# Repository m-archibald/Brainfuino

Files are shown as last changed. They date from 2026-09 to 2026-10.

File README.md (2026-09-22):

# Brainfuino [-]+.

```text
  ____            _        __       _           
 | __ ) _ __ __ _(_)_ __  / _|_   _(_)_ __   ___  
 |  _ \| '__/ _` | | '_ \| |_| | | | | '_ \ / _ \ 
 | |_) | | | (_| | | | | |  _| |_| | | | | | (_) |
 |____/|_|  \__,_|_|_| |_|_|  \__,_|_|_| |_|\___/ 
```

**An Arduino-like development board that executes raw Brainfuck natively in silicon.**

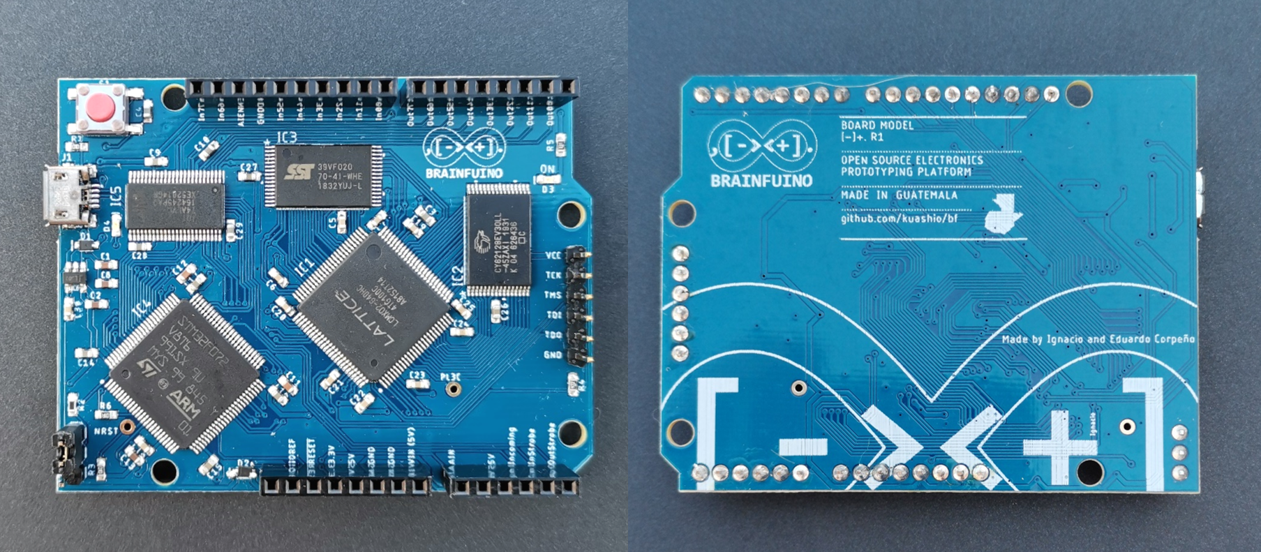
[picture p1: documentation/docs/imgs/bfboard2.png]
The Brainfuino [-]+.
[](https://youtu.be/QloNq8AoHvU)







> ### 📖 [Read the Full Documentation](https://m-archibald.github.io/Brainfuino/)
>
> Comprehensive guides covering quick start, hardware architecture, FPGA toolchain, DirtyJTAG / Diamond flashing, STM32 firmware, 3D printing, and Brainfuck programming are live at **[https://m-archibald.github.io/Brainfuino/](https://m-archibald.github.io/Brainfuino/)**!

---

## What is Brainfuino?

You may have seen the Brainfuino [Hackaday project](https://hackaday.com/2021/01/12/make-room-for-a-new-arduino-competitor-with-native-brainfck/) released during COVID in 2021. Originally created by Eduardo Corpeño, it's a programming board that runs the esoteric programming language Brainfuck completely in hardware. The language is extremely minimal, with just 8 characters, yet it is entirely Turing complete. When uploading code to the Brainfuino, there is no conversion or compression, the ascii brainfuck characters are saved into rom exactly as they are written. Programming in Brainfuck is difficult, hilarious, and rewarding, and doing it with Brainfuino is even better.

---

## Two Processors: Pure Hardware and Quality of Life

There are two processors on the Brainfuino, the actual Brainfuck based soft processor implemented in hardware on the Lattice FPGA, and the STM32 which makes the whole thing user "friendly". Since the FPGA is configured basically as an old fashioned Harvard CPU, instructions move through the soft processor in a continuous stream of parallel bits, these flash into and out of existence, and the STM32 is there to catch them and serialize them so you can use it with a modern PC instead of an ancient parallel based terminal interface. The FPGA does all the hard work here though. When programs are run, all the output is being generated real time in hardware via the FPGA. The FPGA reads bytes of data from good old parallel flash program memory, and when it encounters bytes representing one of the 8 ascii characters used in Brainfuck it executes that with its built in soft processor based instruction set according to the character. Since it's a harvard style cpu, it also uses parallel based RAM to read and write data to and from for computation purposes. The STM32 uses its hardware timer to drive a clock pin to the FPGA at speeds from 500 khz up to 12 mhz. You may wonder if the STM32 is overkill, and your curiosity is valid, it probably is overkill, but by leveraging a separate microcontroller for these quality of life improvements, it allows the Brainfuck soft processor implemented in Verilog on the Lattice FPGA to remain pure and stay true to its purpose to compute Brainfuck. We leave the rest to the STM32: Usb communication, parallel to serial conversion, program memory flushing and prep, variable clock speed control, and an interactive terminal interface.

---

## Why Brainfuino?

As to answer the question of why? Well: The challenge. And to quote the original author Eduardo Corpeño, with the Brainfuino you get "bragging rights for writing code that works! You certainly won't get that from the Arduino."

---

## What's in Revision 1.1

My revision 1.1 of the Brainfuino has:
- Improved clock routing to the FPGA soft processor using an FPGA pin optimized for clock input rather than a generic GPIO
- Proper VBus to 3.3v connection on the STM32 increasing STM32 clock stability
- JLCPCB compatible parts list and reduced cost by switching to prestocked "basic" components.
- USB C!
- A nifty 3D printed case
- KiCAD design files (migrated from the original Autodesk Eagle)

See the original demo video: [Brainfuino: Hardware Brainfuck Processor (YouTube)](https://www.youtube.com/watch?v=QloNq8AoHvU)

---

## Three Languages in One Project

Three different programming paradigms come together to bring Brainfuino to life:

| Language | Layer | Purpose |
| :--- | :--- | :--- |
| **Brainfuck** | **Application** | The end-user language. Programs are written in standard Brainfuck and run directly on the hardware tape. |
| **Verilog HDL** | **Processor Core** | Defines the`brainfuck_uP` digital architecture, instruction decoder, and state machine synthesized into the FPGA bitstream (`.jed`). |
| **Embedded C**  | **Coprocessor Firmware** | Powers the STM32F072 microcontroller, managing USB CDC communications, clock synthesis, and ROM flashing. |

---

## Repository Structure

This repository is the consolidated monorepo for the entire Brainfuino project:

- [`brainfuino-PCB/`](./brainfuino-PCB/): Hardware schematics and board layouts for **Rev 1.0** (Eagle) and **Rev 1.1** (KiCad with JLCPCB fabrication Gerbers, BOM, and CPL).
- [`brainfuck_uP-FPGA-softprocessor/`](./brainfuck_uP-FPGA-softprocessor/): Lattice MachXO2 soft-processor in Verilog, pin constraints (`.lpf`), and Lattice Diamond project files.
- [`companion-STM32-firmware/`](./companion-STM32-firmware/): STM32F072 firmware (STM32CubeIDE project) handling USB CDC serial, clock generation, and ROM flashing.
- [`3D-printable-case/`](./3D-printable-case/): SolidWorks (`.SLDPRT`) and 3D printing CAD models (`.STEP`) for the custom enclosure.
- [`documentation/`](./documentation/): Comprehensive MkDocs Material documentation source files and project guides.

---

## Project Origins & Acknowledgements

The Brainfuino project was originally conceived, designed, and built by **Eduardo Corpeño** ([kuashio](https://github.com/kuashio)).

- **Video Demonstration:** [Brainfuino: Hardware Brainfuck Processor (YouTube)](https://youtu.be/QloNq8AoHvU)
- **Project Build Log:** [Brainfuino on Hackaday.io](https://hackaday.io/project/176757-brainfuino)
- **Original Soft-Processor:** [kuashio/brainfuck_uP](https://github.com/kuashio/brainfuck_up)
- **Original STM32 Firmware:** [kuashio/brainfuino-firmware](https://github.com/kuashio/brainfuino-firmware)
- **Brainfuck IDE:** [Visual brainfuck](https://sites.google.com/site/visualbf/)

Continued and maintained by:

- **Matthew Archibald:** Hardware modernization, KiCad Rev 1.1 redesign, JLCPCB manufacturing packages, 3D-printable case, and documentation.
- **Thalia Archibald:** Software architecture, compiler engineering, and curator of the [bfcorpus repository](https://github.com/thaliaarchi/bfcorpus) and [bfcoq](https://github.com/thaliaarchi/bfcoq).

---

### Ready to Build or Program?

Check out the official documentation for step-by-step assembly guides, bitstream flashing, and terminal operation:
**[https://m-archibald.github.io/Brainfuino/](https://m-archibald.github.io/Brainfuino/)**

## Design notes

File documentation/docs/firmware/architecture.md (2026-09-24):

# STM32 Coprocessor Firmware Architecture

The **STM32F072V8T6** acts as the executive companion to the FPGA soft-processor. While the FPGA executes Brainfuck code, the STM32 manages everything outside the CPU core:

1. Synthesizing system clock pulses.
2. Managing USB communications and CDC virtual serial port emulation.
3. Controlling reset lines and programming parallel ROM with new Brainfuck code.
4. Relaying characters between the terminal and the FPGA.
5. Sampling analog voltages via its internal 12-bit ADC.

---

## State Machine Overview

The firmware implements two primary operational states:

```mermaid
stateDiagram-v2
    [*] --> STATE_RUN: Boot / Reset
    
    state STATE_RUN {
        [*] --> CleanPassthrough
        CleanPassthrough --> SerialInput: Keyboard Keystrokes (passes to FPGA inPort)
        CleanPassthrough --> ReadFPGAOutput: FPGA asserts portWR
    }
    
    STATE_RUN --> STATE_PROGRAM: Hold Button (>= 3 seconds)
    
    state STATE_PROGRAM {
        HoldReset: Assert BF_RST low
        StatusLED: Turn ON Red LED
        RAMBuffer: Buffer paste (or stream to Flash if > 8 kB)
        EraseROM: Erase parallel Flash sectors
        FastWriteROM: Direct register write to Flash with progress %
        VerifyROM: Read-back verification against RAM
        HoldReset --> StatusLED
        StatusLED --> RAMBuffer
        RAMBuffer --> EraseROM
        EraseROM --> FastWriteROM
        FastWriteROM --> VerifyROM
    }
    
    STATE_PROGRAM --> STATE_RUN: Short Press Button (< 3 seconds)
```

---

## Flash ROM Programming & Streaming Engine

The 256 kB Flash memory chip (`SST39LF020`) has its control and address pins shared between the FPGA and the STM32:

1. **Isolation:** When `STATE_PROGRAM` is active, the STM32 pulls the FPGA reset line low (`BF_RST = 0`). This places the FPGA's 18-bit program counter lines into high impedance (`assign pc_pins = (reset) ? pc : 18'bzz...`), releasing the ROM address bus.
2. **Dual-Mode Flashing Strategy:**
   * **Programs ≤ 4 kB:** Buffered in internal STM32 SRAM (`prog_buffer`). Once a 100 ms idle timeout elapses, the STM32 erases ROM, programs bytes with live percentage updates, verifies against RAM, appends an endless loop (`[-]+[]`), and auto-launches.
   * **Streaming Engine (> 4 kB up to 256 kB):** When incoming code exceeds 4 kB, the firmware transitions into streaming mode. It erases the Flash chip and writes the initial 4 kB chunk. Subsequent packets are buffered through a circular staging FIFO (`stream_staging`, 1 kB) and continuously written to Flash.
3. **Hardware USB CDC Flow Control (NAK Backpressure):**
   * Parallel Flash erase takes ~20 ms, and byte programming takes ~10 µs per byte. To prevent host USB buffer overflows during rapid terminal pasting, the firmware implements true hardware flow control at the USB CDC endpoint level.
   * When the staging buffer is near capacity or during Flash erase, `CDC_Receive_Callback` halts endpoint re-arming and sets `cdc_rx_paused = 1`. The STM32 hardware USB engine returns hardware **NAK tokens** to the host PC, pausing host transmissions with zero dropped bytes.
   * As the main execution loop drains the staging FIFO to Flash, `CDC_Resume_Rx()` re-arms the OUT endpoint (`USBD_CDC_ReceivePacket`), smoothly resuming host transmission.
4. **Byte Programming:** Using direct single-cycle register writes (`GPIOE->ODR` for address lines `A0`–`A15` and `GPIOB->ODR` for data lines `D0`–`D7`), the STM32 writes the program to Flash in tens of milliseconds while streaming live percentage progress to the terminal.
5. **Auto-Launch & Termination:** Automatically appends `[-]+[]` to cleanly park the FPGA PC at end-of-program, pulses reset, and auto-launches.

---

## USB CDC Virtual Serial Port & Software DFU Jump

The STM32F072 features built-in USB 2.0 Full-Speed hardware with an internal PHY and dedicated crystal-less clock recovery (using ST's Clock Recovery System `CRS`), eliminating the need for an external crystal oscillator.

Incoming serial bytes are processed in `CDC_Receive_Callback()` in `main.c`, while outgoing characters from the FPGA are collected via an interrupt routine and buffered into the CDC transmit endpoint.

### Software DFU Bootloader Jump Architecture

To eliminate the need for physical jumper manipulation during firmware updates:

1. **Trigger Command:** Receiving the serial token `!DFU!` in `STATE_RUN` sets `dfu_requested = 1`.
2. **Physical USB Disconnect:** In Thread Mode, `Execute_DFU_Jump()` shuts down the USB stack and pulls the USB DP line (`PA12`) LOW for 200 ms. This forces the host operating system to recognize a genuine physical USB disconnection.
3. **SRAM Persistence Flag:** The firmware writes `0xDEADBEEF` to a reserved address at the top of SRAM (`0x20003FF0`) and invokes `NVIC_SystemReset()`.
4. **Startup Intercept:** In `startup_stm32f072v8tx.s`, the very first instructions in `Reset_Handler` inspect `0x20003FF0`. If the magic value is present, the handler clears the flag, re-initializes the Main Stack Pointer (`MSP`) from the ST system ROM vector table at `0x1FFFC800`, and branches directly to the ROM DFU bootloader entry point (`0x1FFFC804`). The board seamlessly re-enumerates as an ST DFU bootloader device.

---

## Smart Hardware Clock-Pausing & Output Throttling

Brainfuino's MachXO2 FPGA soft-processor executes Brainfuck instructions in parallel without hardware wait-states. At high frequencies, output instructions (`.`) hold data on the bus for only 20 clock cycles (1.66 µs at 12 MHz). Closely-spaced prints (e.g. `\r\n` line endings in Mandelbrot or ASCII banner loops) would outpace Cortex-M0 interrupt latency, causing dropped characters.

To guarantee **100% character fidelity at all speeds**, the firmware implements a hardware clock-pausing mechanism:

1. **Falling-Edge Strobe Detection:** `BF_OUTSTRB` (`PC3`) is configured in `GPIO_MODE_IT_FALLING`. When `portWR` drops LOW, data on `PB0`–`PB7` has already settled for 20 clock cycles, catching the FPGA at the start of its output hold window.
2. **Instant Hardware Clock Gating:** The very first assembly instruction inside `EXTI2_3_IRQHandler` gates the STM32's MCO output on `PA8`:
   ```c
   RCC->CFGR &= ~RCC_CFGR_MCO;  // 1 CPU cycle hardware freeze
   ```
   This instantly suspends the FPGA master clock, freezing the soft-processor with the output byte held static on the bus.
3. **Trace Settle & Bus Latch:** Two `__NOP()` cycles allow all PCB trace line skews to settle completely. The STM32 reads `(uint8_t)GPIOB->IDR` directly from register memory.
4. **Buffer Backpressure & Resume:**
   * If the USB circular queue has capacity, the clock is resumed in the same interrupt (`~200 ns` total pause).
   * If the USB circular queue is near capacity (`used >= OUTBOX_CAPACITY - 8`), `mco_throttled = 1` keeps the FPGA clock suspended until the USB endpoint transmits a packet and the queue drains below 50%.

---

## 25-Speed Dual-Engine Frequency Ladder & Parallel ROM Timing

The clock fed to the FPGA soft-processor pin `PA8` utilizes a **dual-engine architecture** supporting 25 distinct frequencies across 6 orders of magnitude (10 Hz to 12 MHz):

1. **Hardware PWM Engine (10 Hz – 50 kHz):** Generated by STM32 Timer 1 Channel 1 (`TIM1_CH1`, Alternate Function `AF2` on `PA8`) operating with 50% duty cycle, driven by the 48 MHz system clock through configurable prescalers (`PSC`) and auto-reload registers (`ARR`).
2. **Master Clock Output Engine (62.5 kHz – 12 MHz):** Generated by Microcontroller Clock Output (`MCO`, Alternate Function `AF0` on `PA8`) dividing either `HSI` (8 MHz) or `HSI48` (48 MHz).

--8<-- "snippets/clock-speeds.md"

### The 55 ns Physical Silicon Ceiling
The parallel NOR Flash on Brainfuino is the `SST39LF020-55-4C-WHE` (*T*~AA~ = 55 ns). Because the MachXO2 fetches instructions in a single cycle without wait-states:

$$F_{\text{max}} = \frac{1}{T_{AA} + T_{co} + T_{su} + 2\cdot T_{\text{trace}}} \approx \frac{1}{55\text{ ns} + 8.5\text{ ns}} \approx 15.75\text{ MHz}$$

Speeds above 12 MHz (such as 24 MHz at 41.6 ns or 48 MHz at 20.8 ns) physically violate the Flash access time, causing un-waitstated fetches to fail. **12 MHz** is the highest divider that provides positive timing margin (+28.3 ns) and delivers 100% character fidelity.

---

## Manual Stepping & Burst Accumulator Engine

When Manual Stepping Mode is enabled, the STM32 halts the continuous clock signal on `PA8`. The coprocessor features an accumulator engine (`manual_step_ticks_pending`) that coordinates stepping:

* **Keystroke Accumulation:** Each trigger keystroke adds the configured step multiplier (1, 10, 100, 1k, 10k, or 100k ticks) to the pending counter. Rapidly pressed or spammed keys pile up in the accumulator and drain without loss.
* **PWM Stepping Precision:** For frequencies ≤ 50 kHz, the engine enables `TIM1->CR1 |= TIM_CR1_CEN` and monitors hardware update interrupt flags (`TIM_SR_UIF`) on full cycle transitions.
* **MCO Burst Gating:** For frequencies ≥ 62.5 kHz, the engine gates `RCC->CFGR` using calibrated microsecond bursts while servicing USB CDC character streaming in real time.

---

## Non-Volatile Flash Configuration Persistence

Configuration menu preferences (active clock frequency, manual stepping mode, step multiplier, step trigger key, auto-program on paste, upload threshold, auto-reset, endless loop injection, and run mode speed hotkeys) are preserved across power cycles:

* **Flash Emulation Sector:** Stored in the top 2 kB page of the STM32F072's internal Flash memory: Page 63 (`0x0801F800` – `0x0801FFFF`), located above application code.
* **Integrity Validation:** Validated via a 32-bit magic word (`0xBF072C01`) and an additive checksum. If the page is unwritten or corrupted, safe defaults are loaded.
* **Delayed Wear Mitigation:** Runtime hotkey speed changes (`PgUp`/`PgDn` or numeric keys) start a non-blocking 3-second debounce timer. Settings only commit to internal Flash once the user stops adjusting speeds, preventing unnecessary flash write cycles during rapid frequency adjustments.
* **Seamless Boot Restoration:** `settings_load()` executes during system initialization before `state = STATE_RUN`, guaranteeing the user's preferred clock speed and settings apply immediately on power-up.

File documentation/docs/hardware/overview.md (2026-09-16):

# Hardware Architecture & Specifications

The Brainfuino is engineered in the classic **Arduino Uno form factor**. Why? Mostly for the fun and comedy of having an Arduino-compatible board that runs Brainfuck in native silicon! 

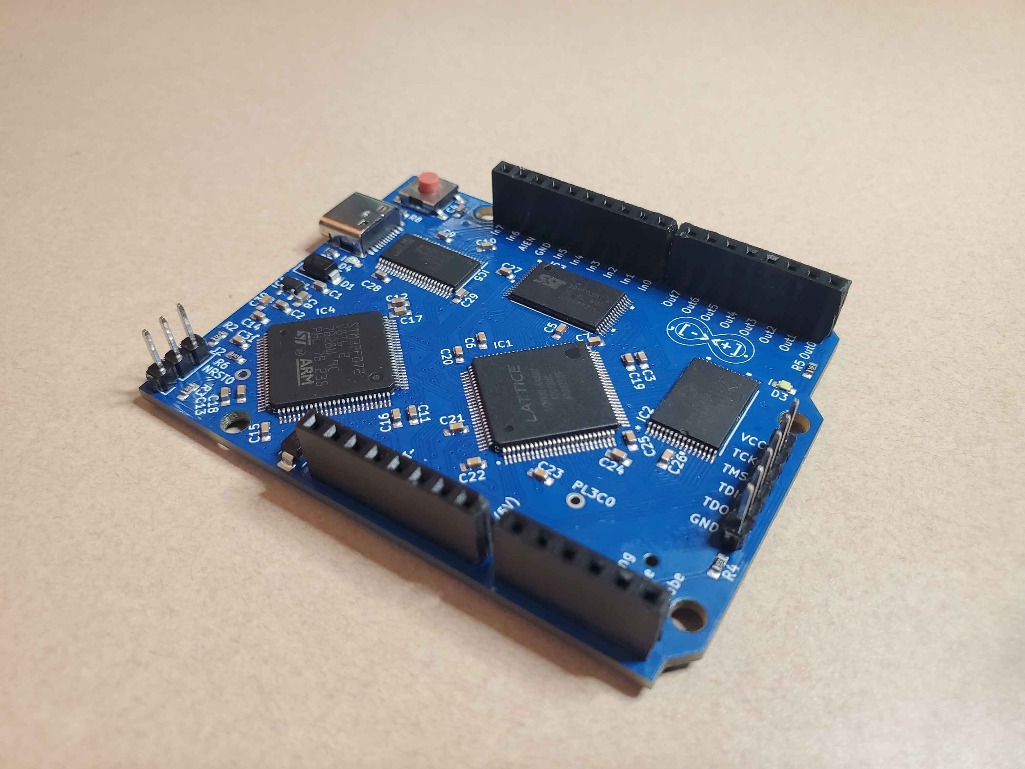
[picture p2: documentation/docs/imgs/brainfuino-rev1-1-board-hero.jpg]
Brainfuino Rev 1.1 Fully Assembled Board

*The Brainfuino Rev 1.1 hardware: featuring the Lattice MachXO2 FPGA, STM32F072 coprocessor, parallel SRAM/ROM, and Arduino Uno-compatible shield headers.*

While standard Arduino shields can physically plug into the headers ("if you really like pain, lol"), the pin definitions are customized to support Brainfuino's native **8-bit parallel I/O buses**.

---

## The Center of the Machine: Lattice MachXO2

Architecturally, the **Lattice MachXO2 FPGA is the absolute center of the universe**. All other subsystems—Flash memory, SRAM, level translators, and the STM32 coprocessor—exist entirely to serve the FPGA's execution pipeline:

```mermaid
flowchart TD
    ROM["256 kB Flash ROM<br/>(SST39LF020)<br/>Brainfuck ASCII Code Space"]
    RAM["128 kB Parallel SRAM<br/>(CY62128EV30)<br/>Brainfuck Data Tape"]
    
    FPGA["Lattice MachXO2 FPGA<br/>LCMXO2-640HC-4TG100C<br/>'brainfuck_uP' Soft-Processor"]

    STM["STM32F072 Coprocessor<br/>System Clock • USB CDC • Flash Writer"]
    TRANS["74ALVC164245 Level Shifter<br/>16-bit 3.3V to 5V Buffer"]
    HEADERS["Physical Arduino Headers<br/>8-bit Parallel In • 8-bit Parallel Out<br/>InStrobe • OutStrobe • Incoming"]

    PWR["Power: USB-C 5V to SPX3819 3.3V LDO"]

    ROM <-->|18-bit PC Address and 8-bit Instruction| FPGA
    FPGA <-->|17-bit Data Pointer and 8-bit Tape Bus| RAM
    STM -->|Clock: 0.5 to 48 MHz| FPGA
    STM <-->|Reset and USB Serial Stream| FPGA
    STM -.->|Sector Erase and Flash Burner| ROM
    FPGA <-->|3.3V Parallel In and Out Buses| TRANS
    TRANS <-->|5V Pin Signals| HEADERS
    PWR --> FPGA
    PWR --> STM
    PWR --> ROM
    PWR --> RAM
```

---

## Bill of Materials (Core Silicon)

| Designator | Part Number | Package | Role |
| :--- | :--- | :--- | :--- |
| **IC1** | `LCMXO2-640HC-4TG100C` | TQFP-100 | **Lattice MachXO2 FPGA**: Hosts the `brainfuck_uP` processor state machine. |
| **IC2** | `CY62128EV30LL-45AXI` | TSOP-32 | **128 kB Static RAM**: Serves as the Brainfuck data tape memory. |
| **IC3** | `SST39LF020-55-4C-WHE` | TSOP-32 | **256 kB Parallel Flash**: Holds the Brainfuck ASCII program code. |
| **IC4** | `STM32F072V8T6` | TQFP-100 | **ARM Cortex-M0 Coprocessor**: Bridges USB, drives system clock, writes ROM, and provides ADC input. |
| **IC5** | `74ALVC164245PAG8` | TSSOP-48 | **16-bit Level Shifter**: Translates between 3.3V FPGA logic levels and 5V header pin levels. |
| **IC6** | `SPX3819M5-L-3-3` | SOT-23-5 | **3.3V 500mA LDO Regulator**: Powers the FPGA, MCU, and memories from USB 5V. |
| **J1** | 16-pin USB-C | SMD | **USB 2.0 Interface**: Host data and 5V board power. |

---

## Power & Level Shifting (3.3V to 5V)

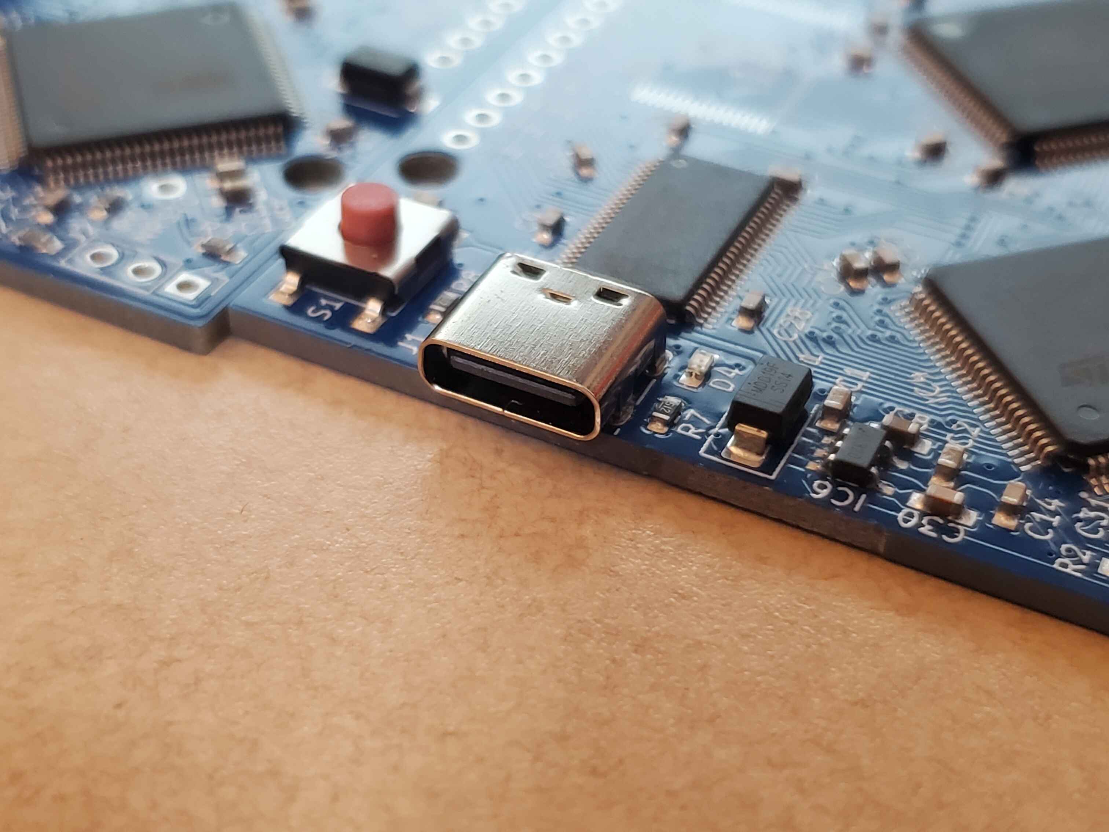
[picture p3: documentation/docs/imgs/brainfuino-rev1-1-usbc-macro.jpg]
Brainfuino Rev 1.1 USB-C and Power Subsystem

*Macro view of the USB Type-C connector J1, reset button S1, Schottky diode D4, and SPX3819 LDO regulator.*

### Power Rails
* **5V Rail:** Sourced directly from USB-C VBUS through protection Schottky diodes (`SS12`). Supplies the 5V power header and the 5V side of the `74ALVC164245` transceiver.
* **3.3V Rail:** Regulated by the `SPX3819` ultra-low-noise LDO. Powers the FPGA core, I/O banks, STM32 MCU, SRAM, and Flash ROM.

### Shield Compatibility & Translation
Standard Arduino Uno shields typically expect 5V logic. The MachXO2 FPGA operates strictly at 3.3V logic levels. Connecting 5V directly to the FPGA pins would damage the silicon.

The **74ALVC164245** dual-supply bus transceiver provides bidirectional level translation between the 3.3V FPGA I/O and the 5V shield headers with nanosecond switching delays.

---

## Physical Headers & Pinout

Unlike an Arduino Uno, which exposes arbitrary general-purpose GPIOs (D0–D13), the Brainfuino headers directly expose the FPGA soft-processor's native **8-bit parallel buses** (`In0`–`In7`, `Out0`–`Out7`) and handshake control strobes (`InStrobe`, `OutStrobe`, `Incoming`, `AIN`, `AIEN`).

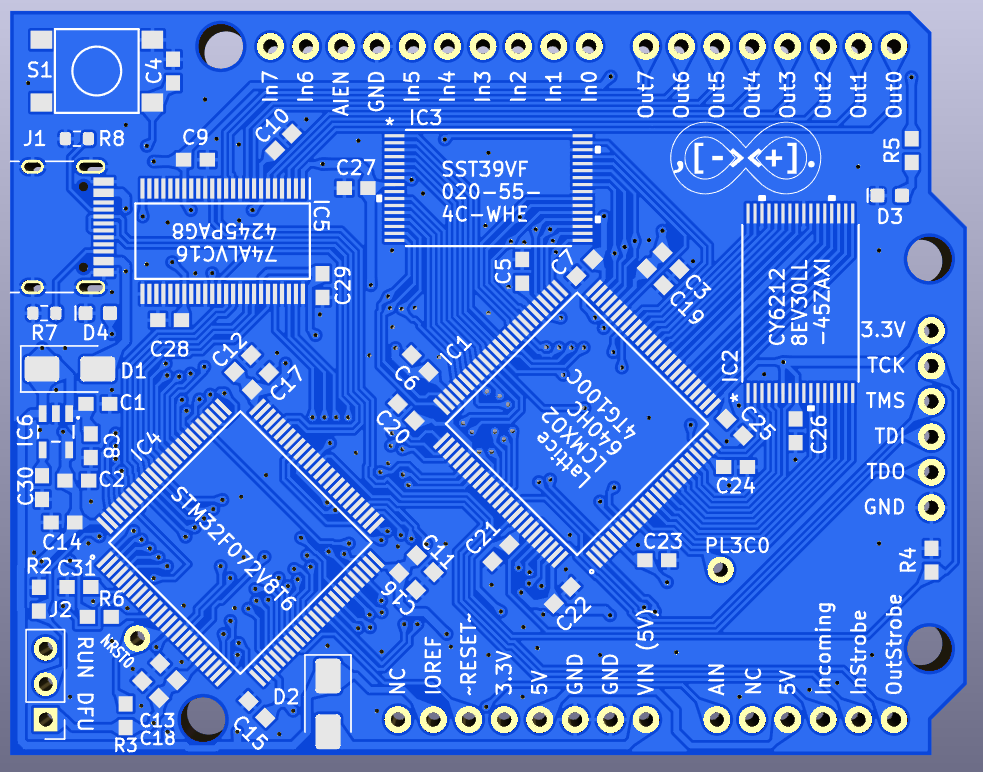
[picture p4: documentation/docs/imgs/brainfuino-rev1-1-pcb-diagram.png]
Brainfuino Rev 1.1 PCB Layout & Pinout

*Top-down PCB layout diagram showing IC designators, parallel I/O buses (In0–In7, Out0–Out7), control strobes, and programming headers.*

### Onboard Programming Headers
* **FPGA JTAG (6-pin):** `TCK`, `TMS`, `TDI`, `TDO`, `GND`, `3.3V` (used with Lattice Diamond or DirtyJTAG).
* **STM32 SWD (4-pin):** `SWDIO`, `SWCLK`, `GND`, `3.3V` (used with ST-Link).

---

## Board Silkscreen & Artwork

The underside of the Brainfuino Rev 1.1 PCB showcases custom silkscreen graphics celebrating the Brainfuck instruction set and open-source origins:

<div class="grid cards" markdown="1">

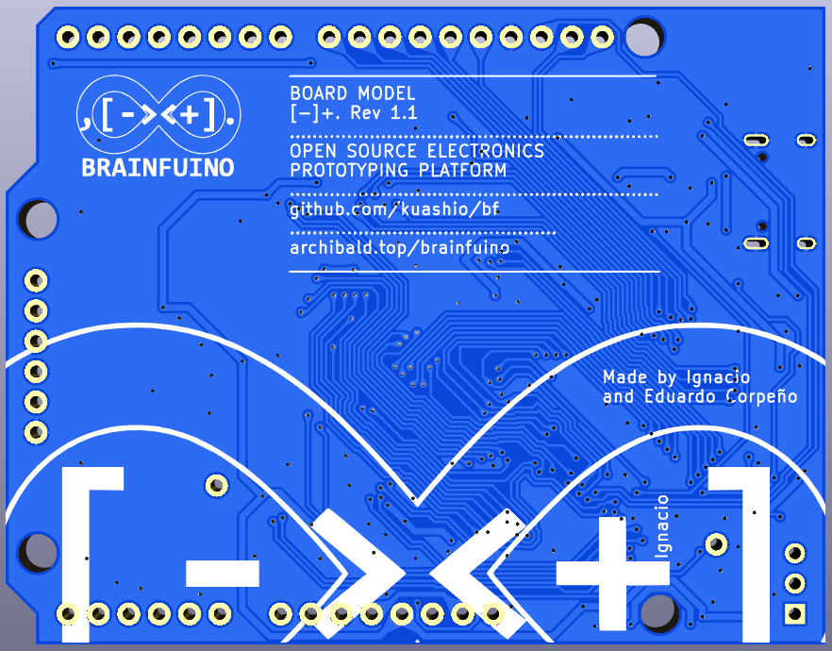
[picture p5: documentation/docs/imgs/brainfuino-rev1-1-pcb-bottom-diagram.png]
Brainfuino Rev 1.1 Bottom Silkscreen Render
-   
    
    ---
    
    **Bottom Artwork Layout**
    Vector silkscreen rendering highlighting the Arduino-style infinity loop transformed into `[-><+]`, project URLs, and attribution to Ignacio and Eduardo Corpeño.

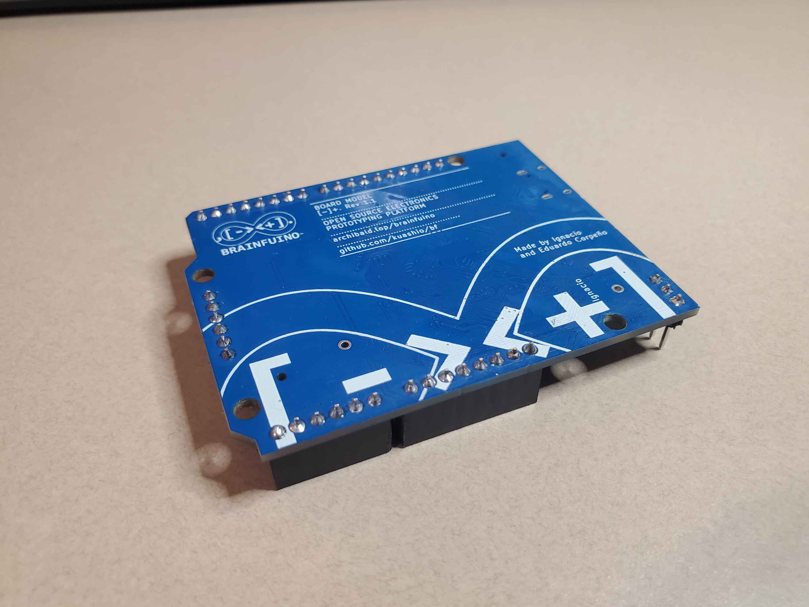
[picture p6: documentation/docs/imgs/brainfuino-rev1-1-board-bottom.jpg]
Brainfuino Rev 1.1 Manufactured Board Bottom
-   
    
    ---
    
    **Fabricated Physical Board**
    The finished Rev 1.1 board fresh from fabrication, showing the crisp white silkscreen artwork on blue solder mask.

</div>

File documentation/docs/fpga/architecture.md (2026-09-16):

# FPGA Soft-Processor Architecture

At the heart of the Brainfuino lies **`brainfuck_uP`**, a custom soft-processor core designed in Verilog by Eduardo Corpeño and synthesized for the **Lattice MachXO2-640HC** FPGA.

Unlike general-purpose microprocessors that require an instruction set architecture (ISA) decoding binary opcodes into ALU control signals, `brainfuck_uP` natively interprets **raw ASCII characters** directly in hardware.

---

## Harvard Memory Model

The architecture features strict separation between code and data memories:

```mermaid
flowchart LR
    subgraph Core ["Brainfuino Core"]
        CPU["brainfuck_uP Core<br/>(MachXO2 FPGA)"]
        PC["Program Counter pc<br/>18-bit register"]
        PTR["Data Pointer p<br/>17-bit register"]
        BRK["Brackets Counter<br/>18-bit register"]
    end

    subgraph Memory ["Memory Subsystems"]
        ROM["Parallel Flash ROM (256 kB)<br/>Instruction Memory"]
        RAM["Parallel SRAM (128 kB)<br/>Data Memory (Brainfuck Tape)"]
    end

    PC -->|18-bit Address Bus| ROM
    ROM -->|8-bit ASCII Instruction| CPU
    PTR -->|17-bit Address Bus| RAM
    CPU <-->|8-bit Data Bus and Control| RAM
```

* **Instruction Memory (ROM):**
    * **Size:** 256 kB (Addresses `0x00000` to `0x3FFFF`).
    * **Bus:** 18-bit unidirectional address bus (`pc_pins[17:0]`), 8-bit instruction bus.
    * **Contents:** The raw Brainfuck source file, stored as ASCII text.
* **Data Memory (RAM):**
    * **Size:** 128 kB (Addresses `0x00000` to `0x1FFFF`).
    * **Bus:** 17-bit address bus (`p[16:0]`), 8-bit bidirectional data bus (`pData[7:0]`), with active-low Read (`RD`) and Write (`WR`) strobes.
    * **Contents:** The Brainfuck memory tape, initialized to zeroes at boot.

---

## Native ASCII Instruction Decoder

In the Verilog source code, the processor state machine matches incoming bytes directly against ASCII character literals:

```verilog
case (instruction)
    "+": begin ... end // Increment current memory cell
    "-": begin ... end // Decrement current memory cell
    ">": begin ... end // Increment data pointer (p <= p + 1)
    "<": begin ... end // Decrement data pointer (p <= p - 1)
    ".": begin ... end // Output character from current memory cell
    ",": begin ... end // Wait for incoming character and store in memory
    "[": begin ... end // Jump forward to matching ']' if *p == 0
    "]": begin ... end // Jump backward to matching '[' if *p != 0
    default: begin
        // Any character other than the 8 Brainfuck commands
        // is treated as a comment / NOP!
        pc <= pc + 8'd1;
    end
endcase
```

Because all non-Brainfuck characters hit the `default` branch and simply advance the Program Counter (`pc <= pc + 1`), you can freely include whitespace, tabs, newlines, and comments directly inside your Brainfuck source files!

---

## State Machine Execution Flow & One-Hot Encoding

The processor is orchestrated by a 7-state finite state machine (FSM). 

### What is "One-Hot" Encoding?

In software or simple microcontroller firmware, state machines often use an integer counter:
* State 0 = `3'b000`
* State 1 = `3'b001`
* State 2 = `3'b010` ... up to State 6 = `3'b110`.

While binary encoding saves bits (only 3 bits for 7 states), inside an FPGA it is suboptimal because every state transition requires combinational logic gates (AND, OR, NOT) to decode the binary pattern.

In an FPGA, flip-flops are physically integrated into every logic slice and are effectively "free." **One-hot encoding** allocates a dedicated flip-flop to each individual state. Exactly **one** flip-flop is active (`1` or "hot") at any given moment:

```verilog
`define STATE_0 7'b0000001
`define STATE_1 7'b0000010
`define STATE_2 7'b0000100
`define STATE_3 7'b0001000
`define STATE_4 7'b0010000
`define STATE_5 7'b0100000
`define BOOT_UP 7'b1000000
```

**Advantages of One-Hot in FPGAs:**
1. **Blazing Speed:** Testing if the CPU is in `STATE_0` requires reading a single register bit (`state[0] == 1`). There is zero decoding latency, allowing clock speeds up to **48 MHz**.
2. **Glitch-Free Operation:** In binary encoding, transitioning from `001` to `010` can briefly pass through `000` or `011` due to microsecond path delays, causing electrical glitches. One-hot transitions directly and cleanly.
3. **Minimal Logic Depth:** Synthesis tools can implement state transitions using direct multiplexer multiplexing rather than wide Boolean equations.

---

### Detailed State-by-State Execution

| State | Purpose | Description & Actions |
| :--- | :--- | :--- |
| `BOOT_UP` | Power-on Initialization | Asserts active-low `WR = 0` to SRAM and counts down an internal `delay` timer to ensure parallel RAM is fully stabilized and zeroed before code execution begins. |
| `STATE_0` | Instruction Fetch & Decode | Evaluates the incoming byte on `instruction`:<br/>• **Pointer moves (`<`, `>`):** Execute in a **single clock cycle** (`p <= p ± 1; pc <= pc + 1;`).<br/>• **Arithmetic (`+`, `-`):** Latches memory byte into accumulator `acc <= pData ± 1`, stages `RD <= 1`, and advances to `STATE_1`.<br/>• **Input (`,`):** Waits for `incoming == 1`, latches `inPort`, and moves to `STATE_1`.<br/>• **Output (`.`):** Latches `outPort <= pData` and moves to `STATE_1`.<br/>• **Loops (`[`, `]`):** Checks `pData` condition. If jump needed, stages `brackets <= 1` and moves to `STATE_5`. |
| `STATE_1` | Memory & Strobe Staging | Drives or samples the bidirectional RAM data bus (`pData`). Stages port read/write strobes (`portRD`, `portWR`). |
| `STATE_2` | Active Strobe Assertion | Asserts active read/write strobes (`WR <= 0` or `RD <= 0`, `portRD <= 0`, `portWR <= 0`) to initiate physical memory latching. |
| `STATE_3` | Strobe Hold Time | Enforces the minimum write pulse width and hold times required by the `CY62128` SRAM datasheet. |
| `STATE_4` | Writeback & PC Increment | Completes the memory write cycle, sets `WR <= 1`, increments the program counter (`pc <= pc + 1`), and returns cleanly to `STATE_0` for the next instruction. |
| `STATE_5` | Bracket Nesting Search | Multi-cycle seek state. Scans forward or backward through ROM instruction-by-instruction, incrementing/decrementing `brackets` until finding the matching pair. |

---

## Hardware Bracket Matching (`[` and `]`)

Handling nested loops in hardware is typically challenging. `brainfuck_uP` achieves this using a dedicated **18-bit bracket nesting counter** (`reg [17:0] brackets`) and a direction flag (`reg FWD`):

1. **Loop Entry (`[`):**
    * If the current memory cell `pData == 0`, the loop must be skipped.
    * The processor sets `FWD = 1`, initializes `brackets = 1`, and enters `STATE_5`.
    * In `STATE_5`, the PC advances byte-by-byte:
        * If another `[` is encountered: `brackets <= brackets + 1`
        * If a `]` is encountered: `brackets <= brackets - 1`
    * When `brackets == 0`, the matching closing bracket has been found, and normal execution resumes.
2. **Loop Exit (`]`):**
    * If `pData != 0`, execution must jump back to the loop header.
    * The processor sets `FWD = 0`, sets `brackets = 1`, and steps the PC backward (`pc <= pc - 1`) in `STATE_5` until the corresponding `[` is located.

Because the counter is 18 bits wide, the processor supports loops nested up to **262,143 levels deep**—vastly exceeding any practical Brainfuck program!

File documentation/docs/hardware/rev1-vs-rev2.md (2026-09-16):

# Revision Comparison: Rev 1.0 vs Rev 1.1

The Brainfuino hardware has evolved through two primary revisions.

---

## High-Level Comparison

| Feature | Rev 1.0 | Rev 1.1 (Current) |
| :--- | :--- | :--- |
| **EDA Tool** | Autodesk Eagle (`.sch`, `.brd`) | **KiCad 9** (`.kicad_sch`, `.kicad_pcb`) |
| **Connector** | Micro-USB | **USB Type-C** |
| **Fabrication Prep** | Generic Eagle CAM outputs | **Pre-packaged JLCPCB Gerber, BOM, and CPL files** |
| **FPGA Pin Mapping** | Original pin assignments | **Optimized routing layout** (requires updated `.lpf` file) |
| **Trace Lengths & Timing** | Initial layout | **Length-checked parallel traces** with propagation delay calculations so data arrives synchronized |
| **Mounting & Case** | Standalone board | Tested with 3D printed case |

---

## FPGA Pin Mapping Changes (`.lpf`)

??? warning "FPGA Pin Mapping Changes (`.lpf`)"
    Revision 1.0 (micro-USB) and Rev 1.1 (USB-C) have slightly different pin assignments for the FPGA. Specifically, in Rev 1.1 the clock input pin was moved to a **dedicated clock-optimized FPGA pin**, which requires a different pin assignment (`.lpf`) file when compiling the firmware in Lattice Diamond:
    
    * Use `brainfuino_v1.1.jed` (or default `brainfuck_uP.lpf`) for **Rev 1.1 boards**.
    * Use `brainfuino_v1.0.jed` for older **Rev 1.0 Eagle boards**.
    * Precompiled `.jed` bitstreams for both revisions are located in [`brainfuck_uP-FPGA-softprocessor/bitstreams/`](https://github.com/m-archibald/Brainfuino/tree/main/brainfuck_uP-FPGA-softprocessor/bitstreams).

---

## Why Switch from Eagle to KiCad?

1. **Open & Accessible Toolchain:** KiCad 9 is completely open-source and free without board size or layer restrictions, making it much easier for community members to inspect, fork, and modify the design.
2. **Modern JLCPCB Integration:** Rev 1.1 uses the KiCad JLCPCB Fabrication Toolkit, generating accurate Pick-and-Place (CPL) and Bill of Materials (BOM) files automatically with matched LCSC part numbers.
3. **USB-C Upgrade:** Eliminates fragile micro-USB connectors in favor of modern, reversible USB Type-C connectivity.

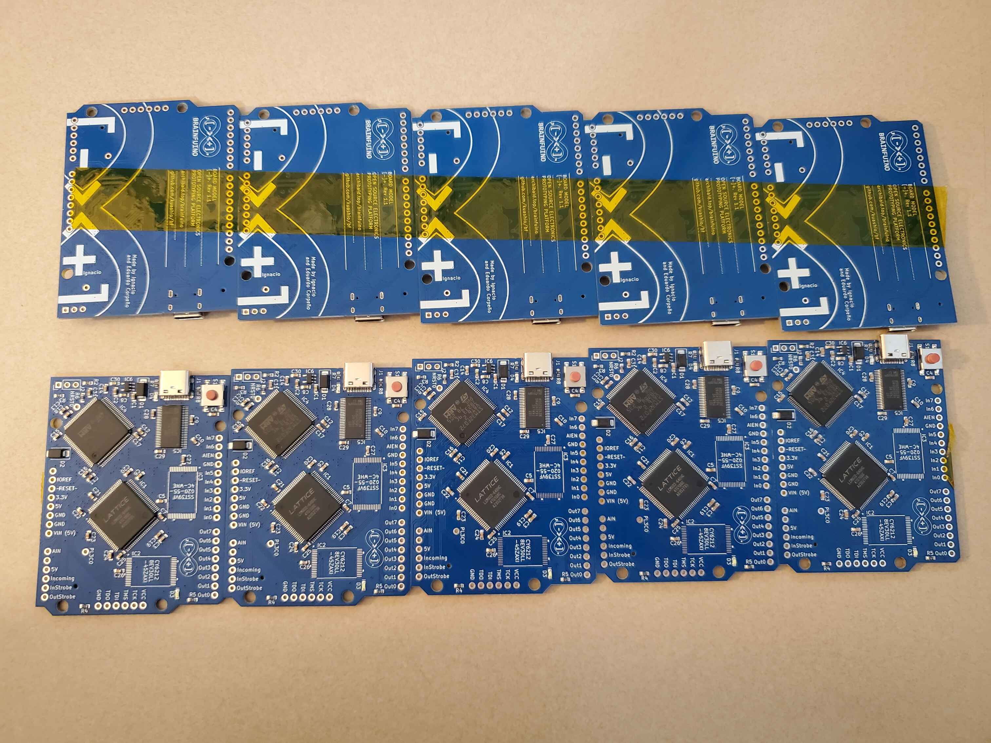
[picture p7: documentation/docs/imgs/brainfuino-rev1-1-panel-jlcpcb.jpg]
Brainfuino Rev 1.1 JLCPCB Production Panel

*A manufactured panel of 5 Brainfuino Rev 1.1 boards fresh from JLCPCB: showing bottom silkscreen and top SMT assembly before hand-soldering unstocked memory chips.*

---

## Hand-Soldering Unstocked Components

When ordering small prototype batches from JLCPCB, certain specialized parallel memory ICs (such as the TSOP-32 SRAM or Flash ROM) may occasionally be out of stock in JLCPCB's local parts library.

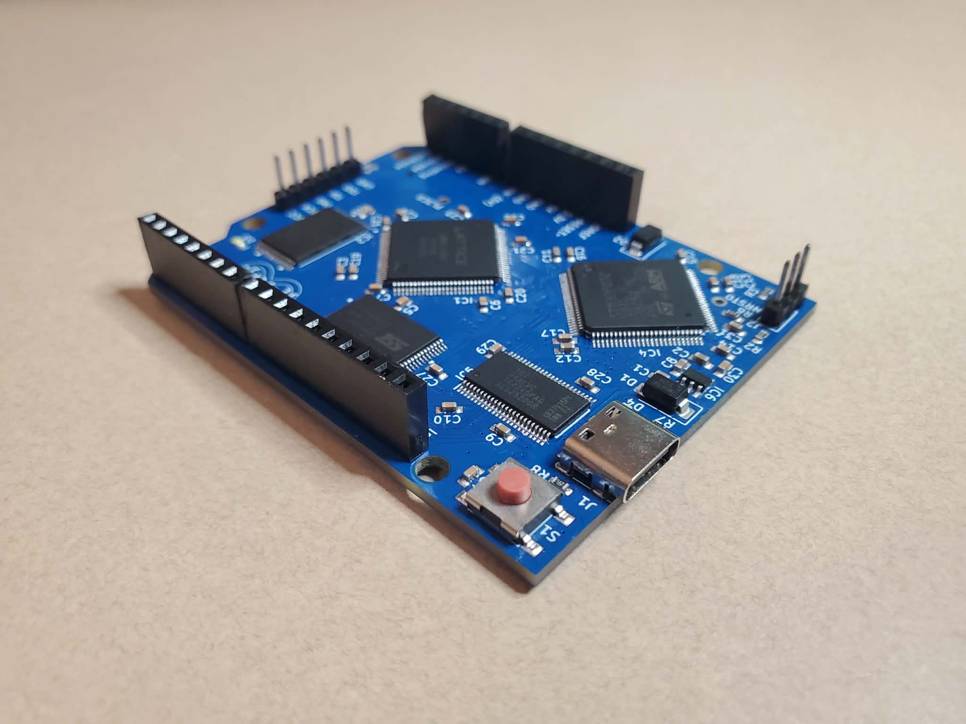
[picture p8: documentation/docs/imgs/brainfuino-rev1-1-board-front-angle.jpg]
Brainfuino Rev 1.1 Hand-Soldered Board

*Completed Brainfuino Rev 1.1 board after hand-soldering TSOP-32 RAM/ROM and pin headers onto the SMT-assembled JLCPCB baseboard.*

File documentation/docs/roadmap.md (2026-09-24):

# Project Roadmap & Future Enhancements

The Brainfuino project continues to evolve from an esoteric proof-of-concept into a polished, hackable hardware development platform. This roadmap outlines current progress, architectural enhancements, and future hardware/firmware milestones.

---

## Status Overview

| Feature | Subsystem | Status | Priority / Notes |
| :--- | :--- | :---: | :--- |
| **3D-Printable Enclosure** | Mechanical | :material-check-circle: **Done** | Custom case with retention hook and single M3 fastener ([Assembly Guide](case/assembly.md)) |
| **KiCad 9 PCB Revision (Rev 1.1)** | Hardware | :material-check-circle: **Done** | USB-C, length-tuned buses, JLCPCB SMT files ([Comparison](hardware/rev1-vs-rev2.md)) |
| **Documentation Suite & CI/CD** | Docs | :material-check-circle: **Done** | MkDocs Material suite, automated GitHub Pages deployment |
| **Dedicated Program Mode** | STM32 Firmware | :material-check-circle: **Done** | Dedicated mode switch via 3s button hold, fast flasher with progress bar and streaming fallback |
| **Smart Clock-Pausing & Throttle** | STM32 Firmware | :material-check-circle: **Done** | 1-cycle MCO gating on falling edge with bus settle and outbox backpressure |
| **25-Speed Ladder & Manual Stepping** | STM32 Firmware | :material-check-circle: **Done** | 10 Hz to 12 MHz dual-engine (PWM + MCO), single & burst stepping accumulator |
| **Non-Volatile Settings Storage** | STM32 Firmware | :material-check-circle: **Done** | Flash Page 63 emulated EEPROM preserves user configuration across power cycles |
| **Multi-Program Library & TOC** | STM32 Firmware | :material-check-circle: **Done** | Internal 76 kB flash partition, 64-slot TOC, dynamic compaction, non-BF pruning |
| **Interactive Terminal Menu UI** | STM32 Firmware | :material-check-circle: **Done** | Multi-page raspi-config style interface with Left/Right option cycling ([Guide](user-guide/config-menu.md)) |
| **USB DFU Bootloader Mode** | STM32 Firmware | :material-check-circle: **Done** | Soft-jump into ST factory ROM bootloader over USB (`!DFU!` or `.\build.ps1 -Flash`) |
| **In-Circuit FPGA JTAG Flashing** | Hardware (Rev 1.2) | :material-clock-outline: **Planned** | Route STM32 GPIOs directly to MachXO2 JTAG for zero-dongle single-cable bitstream updates |
| **High-Capacity QSPI/SPI Flash** | Hardware (Rev 1.2) | :material-clock-outline: **Planned** | 8 MB – 16 MB W25Q128 NOR Flash for massive offline program library and media streaming |
| **Hardware Flow Control UART** | Hardware (Rev 1.2) | :material-clock-outline: **Planned** | USART1 (PA9/PA10) + RTS/CTS (PD11/PD12) for DEC VT100 / vintage terminal pause support |

---

## Firmware & Software Roadmap

### Multi-Program Flash Library & Dynamic TOC Engine — :material-check-circle: Completed
* **The Goal:** Enable storing, organizing, and launching multiple Brainfuck programs directly from non-volatile memory without relying on an external PC.
* **Implementation Details:**
    * **Memory Architecture:** Dedicated 76 kB user partition (Pages 25–62) and 2 kB Table of Contents (Page 24) in the STM32F072's internal 128 kB Flash.
    * **Dynamic Allocation:** Programs of arbitrary lengths (from tiny 50-byte snippets to 76 kB full-scale programs) pack consecutively.
    * **Zero-Erase Tombstone Deletion:** Deleting a program writes `0x0000` to its 16-bit status field in the TOC without erasing Flash pages.
    * **On-Demand Compaction:** Active programs are packed forward only when contiguous space at the end of the pool is exhausted.
    * **Comment Pruning Engine:** Settings for pruning non-Brainfuck characters on paste and when uploading to the library maximize storage efficiency.
    * **Pre-Run Verification:** Interactive prompt allows running a program on the FPGA soft-processor to verify correct execution before committing to Flash, with a 10-second countdown and option to skip (`n`) for instant saving.
    * **Protected Slot 00:** Factory Brainfuino ASCII demo is permanently preserved in Slot 00.

### Dedicated Program Mode — :material-check-circle: Completed
* **The Problem:** Single-key commands (`1`–`7` for clock speed, `!` for dump) previously intercepted terminal keystrokes directly. Interactive programs could not accept number keys without accidentally switching clock speeds.
* **The Solution:** Implemented a dedicated **Program Mode** entered via a 3-second button hold. When in standard Run Mode, incoming characters pass cleanly through to the running Brainfuck soft-processor without interception.

### Smart Variable Clock Rate & Output Throttle — :material-check-circle: Completed
* **The Problem:** At high clock speeds, output instructions (`.`) hold data on the bus for only 20 clock cycles (1.66 µs at 12 MHz). Closely-spaced prints (e.g. `\r\n` line endings in Mandelbrot) outpaced Cortex-M0 interrupt latency, causing dropped characters.
* **The Solution:** Implemented hardware clock-pausing directly in `EXTI2_3_IRQHandler` on `BF_OUTSTRB` falling edge. The STM32 gates MCO in 1 instruction (`RCC->CFGR &= ~RCC_CFGR_MCO`), latches data with zero bus skew, and resumes or throttles based on USB queue capacity.

### 25-Speed Frequency Ladder (10 Hz – 12 MHz) & Manual Stepping Mode — :material-check-circle: Completed
* **The Finding:** Discovered that the `SST39LF020-55` parallel Flash ROM has a maximum address access time of 55 ns (18.18 MHz physical limit). Speeds of 24 MHz (41.6 ns) and 48 MHz (20.8 ns) violated silicon access times during single-cycle fetch.
* **The Solution:** Implemented a dual-engine architecture providing 25 speeds spanning 6 orders of magnitude:
    * **10 Hz – 50 kHz:** Hardware TIM1 PWM generating square wave clocks with full cycle precision.
    * **62.5 kHz – 12 MHz:** MCO hardware clock dividers with positive timing margin (+28.3 ns at 12 MHz).
* **Manual Stepping Mode:** Added single-stepping and burst-stepping capabilities with an accumulator queue engine supporting Spacebar, Tab, or Enter trigger keys with 1 to 100k tick multipliers.

### Non-Volatile Flash Configuration Persistence & Delayed Wear Leveling — :material-check-circle: Completed
* **The Feature:** All configuration menu settings automatically write to the STM32's top internal Flash page (Page 63: `0x0801F800`) on exit with CRC verification and wear-mitigation checking.
* **Delayed Wear Leveling:** Runtime hotkey speed changes (`PgUp`/`PgDn`) use a 3-second debounce timer before committing to Flash, safeguarding flash cycle endurance during rapid adjustments.

### Interactive Terminal Menu & UI Improvements (raspi-config style) — :material-check-circle: Completed
* **The Goal:** Enhance the companion serial terminal with an interactive, user-friendly multi-page text UI for managing programs and configuring STM32 firmware features, accessible via a 6-second button hold (with smooth breathing PWM fade on the Red LED) or terminal command (`!MENU` / `!CONFIG`).
* **Implementation Details:**
    * **Architecture:** Multi-page layout (Main Menu, Program Library, Hardware Settings) with non-blocking ISR-to-Thread-Mode event passing.
    * **Full Navigation:** ANSI / VT100 cursor control (`Up`/`Down`), Left/Right value cycling, direct numeric shortcuts, and quick-action hotkeys (`a` to add, `d` to delete).
    * **Full Documentation:** See the [Configuration Menu & Program Library Guide](user-guide/config-menu.md).

---

## Hardware Roadmap (Rev 1.2 & Beyond)

With over 15 uncommitted GPIO pins available on the 100-pin TQFP package of the `STM32F072V8T6`, the next hardware revision (Rev 1.2) is planned around three key additions:

---

### 1. In-Circuit FPGA JTAG Flashing via STM32
* **The Goal:** Eliminate external JTAG programmers (no Raspberry Pi Pico, ST-Link, or Lattice HW-USBN dongles) and allow both the FPGA bitstream (`.jed`) and Brainfuck code (`.b`) to be flashed over a single USB-C cable or directly through the Web Flasher.
* **Architecture & Wiring:**
    * Route 4 dedicated STM32 GPIO pins directly to the Lattice MachXO2 JTAG port:
        * **`PD8`** → `TCK` (Test Clock)
        * **`PD9`** → `TMS` (Test Mode Select)
        * **`PD10`** → `TDI` (Test Data In)
        * **`PD11_JTAG`** (or `PF6`) → `TDO` (Test Data Out)
    * The external 6-pin header is retained for backwards compatibility with external debuggers.
* **Firmware Implementation:**
    * Integrate an embedded XSVF/SVF player or expose a USB-JTAG bridge (such as CMSIS-DAP or DirtyJTAG) via a secondary USB endpoint.
    * Users can drag-and-drop a new `.jed` bitstream in the browser or terminal to update the `brainfuck_uP` core instantly.

---

### 2. High-Capacity QSPI / SPI NOR Flash Memory
* **The Goal:** Expand onboard offline storage from the internal 76 kB STM32 partition to **8 MB – 16 MB** using an inexpensive 8-pin NOR Flash IC (e.g. Winbond `W25Q64` or `W25Q128` in SOIC-8 / WSON-8).
* **Architecture & Wiring:**
    * Connected to STM32 high-speed SPI/QSPI peripheral pins (`SCK`, `MOSI`, `MISO`, `CS`).
    * Proposed pinout: `PD12` (CS), `PD13` (SCK), `PD14` (MISO), `PD15` (MOSI).
* **Use Cases:**
    * **Massive Program Library:** Store hundreds of full-length Brainfuck programs, self-interpreters, benchmarks, and operating systems permanently on-board.
    * **Offline Flasher Mode:** The STM32 can stage programs into the parallel Flash ROM on the fly with zero host PC connected.
    * **High-Bandwidth Media Streaming:** Store complete 30 fps video animations (e.g., Bad Apple) or audio samples and stream them into the soft-processor in real time.

---

### 3. Vintage Terminal UART with Hardware Flow Control (RTS/CTS)
* **The Goal:** Provide a dedicated serial interface with hardware handshaking for interfacing with vintage ASCII video terminals (DEC VT100, VT220, Wyse), thermal printers, and retro computers without dropping characters.
* **Why Hardware Flow Control is Critical:**
    * Vintage CRT terminals have small input buffers and slow screen-scrolling rates. When scrolling or processing escape sequences, the terminal drops its **CTS (Clear To Send)** line LOW to signal: *"Pause transmission, my screen buffer is full!"*
    * With dedicated CTS/RTS handshaking, the STM32 catches FPGA output characters into a ring buffer and automatically pauses UART transmission while CTS is deasserted, resuming instantly when the terminal is ready.
* **Simultaneous USB & UART Operation:**
    * On the STM32F072, `PA11` and `PA12` are dedicated to USB Full-Speed (`USB_DM` / `USB_DP`).
    * By assigning `USART1` data to `PA9`/`PA10` and mapping flow control to Port D, USB CDC and the hardware UART operate **simultaneously without pin conflicts**:
        * **`PA9`**: `USART1_TX` (Transmit Data to Terminal)
        * **`PA10`**: `USART1_RX` (Receive Data from Keyboard)
        * **`PD11`**: `USART1_CTS` (Clear To Send — input from Terminal)
        * **`PD12`**: `USART1_RTS` (Request To Send — output to Terminal)
* **Bonus — Emergency ROM Bootloader:**
    * ST's built-in factory ROM bootloader natively listens on **`PA9`/`PA10`** when `BOOT0 = 1`. If USB is unavailable, users can unbrick or flash firmware directly over this header using any standard USB-UART adapter.

---

### Rev 1.2 Pin Budget & Assignment Table

| Subsystem | Signal Name | STM32 Pin | Alternate Function / Role |
| :--- | :--- | :--- | :--- |
| **FPGA JTAG** | `TCK` | **`PD8`** | Clock input to MachXO2 JTAG engine |
| **FPGA JTAG** | `TMS` | **`PD9`** | Mode select input to MachXO2 |
| **FPGA JTAG** | `TDI` | **`PD10`** | Serial data input to MachXO2 |
| **FPGA JTAG** | `TDO` | **`PF6`** | Serial data output from MachXO2 |
| **SPI Flash** | `FLASH_CS` | **`PD13`** | Chip select for W25Q128 Flash |
| **SPI Flash** | `FLASH_SCK` | **`PD14`** | SPI master clock (up to 18 MHz) |
| **SPI Flash** | `FLASH_MISO` | **`PD15`** | SPI master in / slave out |
| **SPI Flash** | `FLASH_MOSI` | **`PF9`** | SPI master out / slave in |
| **Terminal UART** | `USART1_TX` | **`PA9`** | Transmit data (also ST ROM bootloader TX) |
| **Terminal UART** | `USART1_RX` | **`PA10`** | Receive data (also ST ROM bootloader RX) |
| **Terminal UART** | `USART1_CTS` | **`PD11`** | Hardware flow control input (AF0) |
| **Terminal UART** | `USART1_RTS` | **`PD12`** | Hardware flow control output (AF0) |
| **USB Interface** | `USB_DM` | **`PA11`** | Dedicated USB-C data minus line |
| **USB Interface** | `USB_DP` | **`PA12`** | Dedicated USB-C data plus line |

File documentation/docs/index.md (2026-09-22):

# Brainfuino [-]+.

> **Yes, this is real. Yes, it runs Brainfuck natively in silicon. No, we will not apologize.**

<div class="grid cards" markdown="1">

-   Brainfuino Rev 1.1 Assembled Hardware

    ---

    **Rev 1.1 Hardware**
    
    Lattice MachXO2 FPGA soft-processor paired with an STM32F072 coprocessor, parallel SRAM tape memory, and Flash ROM.

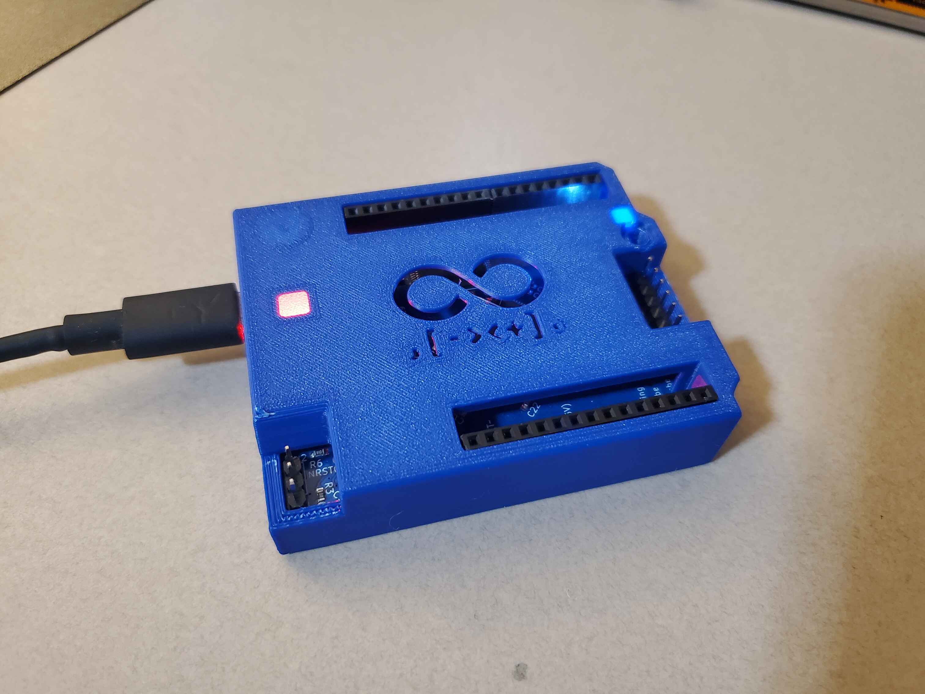
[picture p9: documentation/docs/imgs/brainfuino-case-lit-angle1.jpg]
Brainfuino in 3D Printed Case Running
-   

    ---

    **Custom 3D-Printed Enclosure**
    
    Protective portable case with status LED illumination, single-screw assembly, and exposed programming cutouts.

</div>

---

## What is Brainfuino?

You may have seen the Brainfuino [Hackaday project](https://hackaday.com/2021/01/12/make-room-for-a-new-arduino-competitor-with-native-brainfck/) released during COVID in 2021. Originally created by Eduardo Corpeño, it's a programming board that runs the esoteric programming language Brainfuck completely in hardware. The language is extremely minimal, with just 8 characters, yet it is entirely Turing complete. When uploading code to the Brainfuino, there is no conversion or compression, the ascii brainfuck characters are saved into rom exactly as they are written. Programming in Brainfuck is difficult, hilarious, and rewarding, and doing it with Brainfuino is even better.

---

## Two Processors: Pure Hardware and Quality of Life

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

```mermaid
flowchart TD
    ROM["256 kB Parallel ROM<br/>(Raw ASCII Brainfuck Code)"]
    RAM["128 kB Parallel RAM<br/>(The Physical Tape Memory)"]
    
    FPGA["Lattice MachXO2 FPGA<br/>'brainfuck_uP' Soft-Processor Core<br/>Native ASCII State Machine"]

    STM32["STM32F072 Coprocessor<br/>(Host Interface & Clock Synth)<br/>Clock Generation • USB Serial • Flash Burner"]

    SHIELD["Arduino-Style Headers<br/>Parallel 8-bit In/Out & Handshakes<br/>(Via 74ALVC164245 Level Shifter)"]

    ROM <-->|18-bit PC Address and 8-bit Instruction| FPGA
    FPGA <-->|17-bit Pointer and 8-bit Bidirectional Tape| RAM
    STM32 -->|Clock Pulses: 500 kHz to 12 MHz| FPGA
    STM32 <-->|Reset and Serialized ASCII Stream| FPGA
    STM32 -.->|Flash Programming Bus| ROM
    FPGA <-->|3.3V to 5V Level Shifter| SHIELD
```

---

## Why Brainfuino?

As to answer the question of why? Well: The challenge. And to quote the original author Eduardo Corpeño, with the Brainfuino you get "bragging rights for writing code that works! You certainly won't get that from the Arduino."

---

## What's in Revision 1.1

My revision 1.1 of the Brainfuino has:
- Improved clock routing to the FPGA soft processor using an FPGA pin optimized for clock input rather than a generic GPIO
- Proper VBus to 3.3v connection on the STM32 increasing STM32 clock stability
- JLCPCB compatible parts list and reduced cost by switching to prestocked "basic" components.
- USB C!
- A nifty 3D printed case
- KiCAD design files (migrated from the original Autodesk Eagle)

See the original demo video: [Brainfuino: Hardware Brainfuck Processor (YouTube)](https://www.youtube.com/watch?v=QloNq8AoHvU)

---

## Project Origins & The Team

The Brainfuino project is the brainchild of **Eduardo Corpeño**, a brilliant electrical and computer engineer, FPGA specialist, and university professor of 20+ years:

* Watch Eduardo's original video demo: **[Brainfuino: Hardware Brainfuck Processor (YouTube)](https://youtu.be/QloNq8AoHvU)**.
* Read the original project build log: **[Brainfuino on Hackaday.io](https://hackaday.io/project/176757-brainfuino)**.

Today, the project is maintained and expanded by:

* **Matthew Archibald (Hardware):** Hardware redesigns (Rev 1.1 in KiCad), PCB fabrication, 3D printable case engineering, and documentation.
* **Thalia Archibald (Software):** Software architecture, and curator of the [bfcorpus repository](https://github.com/thaliaarchi/bfcorpus).

---

## Explore the Docs

Use the left sidebar to navigate the guides:

* **[Quick Start Guide](user-guide/quick-start.md):** Connect via USB and run your first Brainfuck program in under 5 minutes.
* **[Terminal Commands](user-guide/terminal-commands.md):** Clock speed toggles (`1`–`7`), program dump (`!`), output buffer dumping (`@`), and upload instructions.
* **[Hardware & PCB](hardware/overview.md):** Schematic walkthrough, BOM, level shifting, and the actual header pinout.
* **[FPGA Soft-Processor](fpga/architecture.md):** Deep dive into the `brainfuck_uP` Verilog core, state machine, and bracket depth counter.
* **[STM32 Firmware](firmware/architecture.md):** Coprocessor architecture, clock generator, USB CDC, and memory flashing.
* **[3D Printed Case](case/assembly.md):** Printing specs and assembly instructions.
* **[Brainfuck Guide & Examples](brainfuck/language-guide.md):** Language cheat sheet, hardware quirks, and tested sample programs.
* **[Project Roadmap](roadmap.md):** Planned firmware modes, dynamic clock throttling, multi-program storage, and potential future ideas.

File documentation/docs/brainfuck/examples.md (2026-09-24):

# Brainfuck Code Examples & Demos

These tested Brainfuck examples are verified for native execution on the Brainfuino. Copy and paste them into your serial terminal to run them!

---

## 1. Official Brainfuino Text Art Banner

[:material-download: Download `banner.b`](../programs/basic/banner.b){ .md-button .md-button--small }

This program outputs the official Brainfuino ASCII logo to the serial terminal. With the companion STM32's **Append Endless Loop** feature enabled (on by default), the hardware automatically halts the program counter at EOF without needing manual halt loops. Paste this code directly into your serial terminal (e.g. Tera Term or PuTTY) at 9600 or 115200 baud:

```brainfuck title="Brainfuino Text Art Banner Generator"
++++++++++[>+++++++++>++++++++++++>++++++>+++++>++++++++>+++++++++++>++++<<<<<<<-]>+>+++>>>>>--------..<<<<<<++++....>>>>>>............<<<<<<.>>>>>>........<<<<<<..>>>>>>.......<<<<<<.>>>>>>.............<<<<<<<+++++++++++++.---.>>>>>>>.<<<<<+.>>>>>.<<<<<<..>>>>>>.+++++++++.---------.<<<<<<.>>>>>>.<<<<<<..>>>>>>.<<<<<<..>>>>>>.<<<<<<.>>>>>>++++++++.<<<<<<.>>>>>>+.<<<<<<.>>>>>>---------.<<<<<<..>>>>>>..+++++++++++++++.---------------.<<<<<<.>.<.>>>>>>...<<<<<<.>>>>>>++++++++.<<<<<<.>>>>>>+.<<<<<<.>>>>>>---------.<<<<<<..>>>>>>...<<<<<<...>>>>>>..<<<<<<<+++.---.>>>>>>>.<<<<<.>>>>>..<<<<<<.>>>>>>.<<<<<<---.>.>>>>>.+++++++.<<<<<<+++..>>>>>>++++++++.---------------.<<<<<<.+.>>>>>>.<<<<<.>>>>>.<<<<<.>>>>>.+++++++.<<<<<<-.>>>>>>-------.<<<<<<---.>.>>>>>.<<<<<.<+++.>.>>>>>.<<<<<.>>>>>.<<<<<.>>>>>.<<<<<.>>>>>.<<<<<.>>>>>.+++++++.<<<<<<.>>>>>>-------.<<<<<<---.>>>>>>.+++++++++++++++.---------------.<<<<<<+++.>>>>>>.<<<<<<---.>>>>>>.<<<<<<<+++.---.>>>>>>>.<<<<<.>>>>>.<<<<<.<+++.>>>>>>+++++++++.---------.<<<<<.>>>>>.<<<<<.>>>>>.<<<<<.>>>>>.++++++++.<<<<<<.>.>>>>>--------.<<<<<.>>>>>.<<<<<.>>>>>.<<<<<.>>>>>.<<<<<.>>>>>.<<<<<.>>>>>..<<<<<<.>.>>>>>.<<<<<.<.>.>>>>>.<<<<<.>>>>>.<<<<<.>>>>>.<<<<<.>>>>>.<<<<<.>>>>>.<<<<<.>>>>>.++++++++.<<<<<<.>>>>>>+.---------.<<<<<.<<+++.---.>>>>>>>.<<<<<.<....>>>>>>+++++++++++++++.<<<<<.<.>.>>>>>---------------..<<<<<<---.+++..>>>>>>++++++++++++.<<<<<<.>.<.>.<.>.>>>>>------------.<<<<<.<.>.<.>.>>>>>..<<<<<<---.+++..>>>>>>++++++++++++.<<<<<<.>.<.>.<.>.>>>>>------------.<<<<<.<.>.<---.+++...>>>>>>+++++++++++++++.---------------.<<<<<<<+++.---.>>>>>>>..................................................<<<<<<<+++.---.
```

**Terminal Output:**
<pre class="ascii-banner">
  ____            _        __       _             
 | __ ) _ __ __ _(_)_ __  / _|_   _(_)_ __   ___  
 |  _ \| '__/ _` | | '_ \| |_| | | | | '_ \ / _ \ 
 | |_) | | | (_| | | | | |  _| |_| | | | | | (_) |
 |____/|_|  \__,_|_|_| |_|_|  \__,_|_|_| |_|\___/ 
</pre>

---

## 2. Classic "Hello World!"

[:material-download: Download `hello.b`](../programs/basic/hello.b){ .md-button .md-button--small }

The quintessential Brainfuck program, taken from the [cwfitzgerald/brainfuck-benchmark](https://github.com/cwfitzgerald/brainfuck-benchmark/blob/master/benches/hello.b) suite. It sets up an initial counter to multiply values into cell targets before printing each ASCII character. Because none of the comment letters contain Brainfuck operator characters, the commented source can be pasted or flashed directly into memory.

```brainfuck title="Hello World (Benchmark Edition)"
+++++ +++++             initialize counter (cell #0) to 10
[                       use loop to set the next four cells to 70/100/30/10
    > +++++ ++              add  7 to cell #1
    > +++++ +++++           add 10 to cell #2 
    > +++                   add  3 to cell #3
    > +                     add  1 to cell #4
    <<<< -                  decrement counter (cell #0)
]                   
> ++ .                  print 'H'
> + .                   print 'e'
+++++ ++ .              print 'l'
.                       print 'l'
+++ .                   print 'o'
> ++ .                  print ' '
<< +++++ +++++ +++++ .  print 'W'
> .                     print 'o'
+++ .                   print 'r'
----- - .               print 'l'
----- --- .             print 'd'
> + .                   print '!'
> .                     print '\n'
```

*Source: [cwfitzgerald/brainfuck-benchmark](https://github.com/cwfitzgerald/brainfuck-benchmark/blob/master/benches/hello.b)*

**Terminal Output:**
```text
Hello World!
```

---

## 3. Interactive Character Echo

[:material-download: Download `echo.b`](../programs/basic/echo.b){ .md-button .md-button--small }

Reads an incoming character from the serial terminal and echoes it back immediately.

```brainfuck title="Echo Program"
,[.,]
```

**Explanation:**
1. `,`: Waits for incoming serial byte and stores it in the current cell.
2. `[`: If the character is non-zero, enters the loop.
3. `.`: Outputs the character back to the terminal.
4. `,`: Reads the next character from the input buffer.
5. `]`: Loops back to check if the next character is non-zero.

---

## 4. Sierpinski Triangle Generator

[:material-download: Download `sierpinski.b`](../programs/fractals/sierpinski.b){ .md-button .md-button--small }

An iconic Brainfuck fractal program authored by **NYYRIKKI** (2002) formatted in the shape of a Sierpinski triangle. It computes and renders a 32-line Sierpinski fractal pattern across an 80-column display (the EOF halt loop is automatically appended by the firmware):

```brainfuck title="Sierpinski Triangle by NYYRIKKI (2002)"
[ This program prints Sierpinski triangle on 80-column display. ]
                                >    
                               + +    
                              +   +    
                             [ < + +    
                            +       +    
                           + +     + +    
                          >   -   ]   >    
                         + + + + + + + +    
                        [               >    
                       + +             + +    
                      <   -           ]   >    
                     > + + >         > > + >    
                    >       >       +       <    
                   < <     < <     < <     < <    
                  <   [   -   [   -   >   +   <    
                 ] > [ - < + > > > . < < ] > > >    
                [                               [    
               - >                             + +    
              +   +                           +   +    
             + + [ >                         + + + +    
            <       -                       ]       >    
           . <     < [                     - >     + <    
          ]   +   >   [                   -   >   +   +    
         + + + + + + + +                 < < + > ] > . [    
        -               ]               >               ]    
       ] +             < <             < [             - [    
      -   >           +   <           ]   +           >   [    
     - < + >         > > - [         - > + <         ] + + >    
    [       -       <       -       >       ]       <       <    
   < ]     < <     < <     ] +     + +     + +     + +     + +    
  +   .   +   +   +   .   [   -   ]   <   ]   +   +   +   +   +    
 * * * * * M a d e * B y : * N Y Y R I K K I * 2 0 0 2 * * * * *    
```

---

---

## 5. Mandelbrot Fractal Viewer

[:material-download: Download `mandelbrot.b` (11.6 kB)](../programs/fractals/mandelbrot.b){ .md-button .md-button--primary }

Authored by **Erik Bosman** (2004), this is one of the most famous Brainfuck benchmark programs in existence. It computes and renders a 2D ASCII visualization of the Mandelbrot set directly over serial. It rigorously stresses nested loop pipelines, 16-bit register arithmetic, and high-frequency character transmission.

* **Author:** Erik Bosman (2004)
* **Source:** [kostya/benchmarks/mandel.b](https://github.com/kostya/benchmarks/blob/master/brainfuck/mandel.b) / [frerich/brainfuck samples/mandelbrot.bf](https://github.com/frerich/brainfuck/blob/master/samples/mandelbrot.bf)

**Terminal Output Preview:**
```text
                                                 ****                                   
                                               ********                                 
                                              **********                                
                                              **********                                
                                               ********                                 
                                           ***************                              
                                       ***********************                          
                                     ***************************                        
                                   *******************************                      
                                   *******************************                      
                                 ***********************************                    
                                *************************************                   
                                *************************************                   
...
```

??? example "View Brainfuck Source (`mandelbrot.b` - 11,669 bytes)"
    Because `mandelbrot.b` is 11.6 kB, it is recommended to download the file directly or run it via the Python runner:
    ```bash
    python programs/pi/run_pi.py programs/fractals/mandelbrot.b --count 200
    ```

---

## 6. Decimal Fibonacci Sequence Generator

[:material-download: Download `fibonacci.b`](../programs/math/fibonacci.b){ .md-button .md-button--small }

Authored by **Daniel B. Cristofani**, this program computes and outputs an unbounded stream of multi-precision decimal Fibonacci numbers (0, 1, 1, 2, 3, 5, 8, 13, 21, 34, ...) with newline separation. Unlike naive implementations that overflow 8-bit cells after the 13th number (233), this program maintains multi-cell decimal registers to scale indefinitely across the tape.

* **Author:** Daniel B. Cristofani
* **Source:** [Daniel B. Cristofani's `fib.b` (brainfuck.org)](http://www.brainfuck.org/fib.b)

```brainfuck title="Decimal Fibonacci Generator by Daniel B. Cristofani"
>++++++++++>+>+[
    [+++++[>++++++++<-]>.<++++++[>--------<-]+<<<]>.>>[
        [-]<[>+<-]>>[<<+>+>-]<[>+<-[>+<-[>+<-[>+<-[>+<-[>+<-
            [>+<-[>+<-[>+<-[>[-]>+>+<<<-[>+<-]]]]]]]]]]]+>>>
    ]<<<
]
```

**Terminal Output:**
```text
0
1
1
2
3
5
8
13
21
34
55
89
144
233
377
610
...
```

---

## 7. Streaming Golden Ratio Generator

[:material-download: Download `golden.b`](../programs/math/golden.b){ .md-button .md-button--small }

Authored by **Daniel B. Cristofani** (2019), this program computes and streams the decimal digits of the Golden Ratio (φ = (1 + √5)/2 ≈ 1.6180339887..., [OEIS A001622](https://oeis.org/A001622)) continuously in pure Brainfuck.

* **Author:** Daniel B. Cristofani (2019)
* **Source:** [Daniel B. Cristofani's `golden.b` (brainfuck.org)](http://www.brainfuck.org/golden.b)

```brainfuck title="Golden Ratio Generator by Daniel B. Cristofani (2019)"
+>>>>>>>++>+>+>+>++<[
    +[
        --[++>>--]->--[
            +[
                +<+[-<<+]++<<[-[->-[>>-]++<[<<]++<<-]+<<]>>>>-<<<<
                <++<-<<++++++[<++++++++>-]<.---<[->.[-]+++++>]>[[-]>>]
            ]+>>--
        ]+<+[-<+<+]++>>
    ]<<<<[[<<]>>[-[+++<<-]+>>-]++[<<]<<<<<+>]
    >[->>[[>>>[>>]+[-[->>+>>>>-[-[+++<<[-]]+>>-]++[<<]]+<<]<-]<]]>>>>>>>
]
```

**Terminal Output:**
```text
1.618033988749894848204586834365638117720309...
```

---

## 8. Arbitrary-Precision Factorials

[:material-download: Download `factorial.b`](../programs/math/factorial.b){ .md-button .md-button--small }

Authored by **Daniel B. Cristofani** (2019), this program computes and emits consecutive factorials (1!, 2!, 3!, 4!, ..., [OEIS A000142](https://oeis.org/A000142)) in multi-precision decimal format. It uses an optimized long-multiplication and carry algorithm.

* **Author:** Daniel B. Cristofani (2019)
* **Source:** [Daniel B. Cristofani's `factorial2.b` (brainfuck.org)](http://www.brainfuck.org/factorial2.b)

```brainfuck title="Arbitrary-Precision Factorials by Daniel B. Cristofani (2019)"
>>>>++>+[
    [
        >[>>]<[>+>]<<[>->>+<<<-]>+[
            [+>>[<<+>>-]>]+[-<<+<]>-[
                -[<+>>+<-]++++++[>++++++++<-]+>.[-]<<[
                    >>>[[<<+>+>-]>>>]<<<<[[>+<-]<-<<]>-
                ]>>>[
                    <<-[<<+>>-]<+++++++++<[
                        >[->+>]>>>[<<[<+>-]>>>+>>[-<]<[>]>+<]<<<<<<-
                    ]>[-]>+>>[<<<+>>>-]>>>
                ]<<<+[-[+>>]<<<]>[<<<]>
            ]>>>[<[>>>]<<<[[>>>+<<<-]<<<]>>>>>>>-[<]>>>[<<]<<[>+>]<]<<
        ]++>>
    ]<<++++++++.+
]
```

**Terminal Output:**
```text
1
1
2
6
24
120
720
5040
40320
362880
3628800
...
```

---

## 9. Interactive Conway's Game of Life

[:material-download: Download `life.b`](../programs/games/life.b){ .md-button .md-button--small }

John Horton Conway's Game of Life 2D cellular automaton running on a 10×10 toroidal grid. Authored by **Daniel B. Cristofani** (2021), this program duplicates the interactive interface of the classic program by **Linus Åkesson** (2007). Enter cell coordinates (e.g. `be` to toggle row `b`, column `e`), type `q` to quit, or send a bare newline (`\n`) to advance to the next generation!

* **Author:** Daniel B. Cristofani (2021) based on interface by Linus Åkesson (2007)
* **Source:** [Daniel B. Cristofani's `life.b` (brainfuck.org)](http://www.brainfuck.org/life.b) / [Linus Åkesson's Game of Life](http://www.linusakesson.net/programming/brainfuck/index.php)

```brainfuck title="Conway's Game of Life (10x10 Toroidal)"
>>>->+>+++++>++++++++++[[>>>+<<<-]>+++++>+>>+[<<+>>>>>+<<<-]<-]>>>>[
  [>>>+>+<<<<-]+++>>+[<+>>>+>+<<<-]>>[>[[>>>+<<<-]<]<<++>+>>>>>>-]<-
]+++>+>[[-]<+<[>+++++++++++++++++<-]<+]>>[
  [+++++++++.-------->>>]+[-<<<]>>>[>>,----------[>]<]<<[
    <<<[
      >--[<->>+>-<<-]<[[>>>]+>-[+>>+>-]+[<<<]<-]>++>[<+>-]
      >[[>>>]+[<<<]>>>-]+[->>>]<-[++>]>[------<]>+++[<<<]>
    ]<
  ]>[
    -[+>>+>-]+>>+>>>+>[<<<]>->+>[
      >[->+>+++>>++[>>>]+++<<<++<<<++[>>>]>>>]<<<[>[>>>]+>>>]
      <<<<<<<[<<++<+[-<<<+]->++>>>++>>>++<<<<]<<<+[-<<<+]+>->>->>
    ]<<+<<+<<<+<<-[+<+<<-]+<+[
      ->+>[-<-<<[<<<]>[>>[>>>]<<+<[<<<]>-]]
      <[<[<[<<<]>+>>[>>>]<<-]<[<<<]]>>>->>>[>>>]+>
    ]>+[-<<[-]<]-[
      [>>>]<[<<[<<<]>>>>>+>[>>>]<-]>>>[>[>>>]<<<<+>[<<<]>>-]>
    ]<<<<<<[---<-----[-[-[<->>+++<+++++++[-]]]]<+<+]>
  ]>>
]
```

**Terminal Output:**
```text
 abcdefghij
a----------
b----------
c----------
d----------
e----------
f----------
g----------
h----------
i----------
j----------
>
```

---

## 10. Unbounded Streaming π Spigot (128 kB SRAM)

[:material-download: Download `pi_stream.b` (20.2 kB)](../programs/pi/pi_stream.b){ .md-button .md-button--primary }
[:material-book-open-page-variant: Read Full Technical Deep-Dive →](pi-spigot.md){ .md-button }

An unbounded streaming π spigot executing directly on bare FPGA silicon. Based on Jeremy Gibbons' Linear Fractional Transformation (LFT) spigot algorithm, it features a **pure Brainfuck dynamic on-demand self-expanding tape engine**:
- **Instantaneous Boot**: Starts with only 4 active slots (64 bytes), emitting early digits in **< 0.05 seconds** (2,033× faster than fixed-allocation startup).
- **Dynamic Growth**: Dynamically activates new 16-byte register slots across the full 128 kB SRAM tape (8,000 slots) whenever arithmetic carries propagate.
- **Hardware Verified**: Emits continuous digits (`3.141592653...`) at 12 MHz on bare silicon.

* **Algorithm:** Jeremy Gibbons (2004), *Unbounded Spigot Algorithms for the Digits of Pi*
* **Architecture:** [Brainfuino Dynamic Tape Spigot Specification](pi-spigot.md)

**Terminal Output:**
```text
=======================================================
>>> FPGA SOFT-PROCESSOR LAUNCHED ON SILICON!
>>> Streaming Pi digits in real-time:
=======================================================
3.141592653...
```

??? example "View Brainfuck Code Preview (`pi_stream.b` - 20,261 bytes)"
    Because `pi_stream.b` is 20 kB, it is recommended to download the file directly or use the automated Python runner:
    ```bash
    python programs/pi/run_pi.py programs/pi/pi_stream.b --count 10
    ```
    For the complete source code, mathematical proofs, and architectural details, see the [Streaming π Spigot Deep-Dive](pi-spigot.md).

---

??? tip "Brainfuck Programs, Compilers & Formal Verification"
    Looking for more Brainfuck programs, compilers, or formal proofs?
    
    * **[Daniel B. Cristofani (brainfuck.org)](http://brainfuck.org/):** Archive of classic Brainfuck algorithms, quines, games, and reference implementations.
    * **[Linus Åkesson (linusakesson.net)](http://www.linusakesson.net/programming/brainfuck/index.php):** Creator of the original Brainfuck Game of Life and Mandelbrot viewer explorations.
    * **[bfcoq (Thalia Archibald)](https://github.com/thaliaarchi/bfcoq):** A formally verified Brainfuck compiler and Turing-completeness proof written in the Coq theorem prover.
    * **[Thalia's Research (thalia.dev)](https://thalia.dev/):** Compilers, programming language theory, and explorations of unexpected Turing completeness.
    * **[Brainfuck Community Archive](https://esolangs.org/wiki/Brainfuck):** Comprehensive reference collection of classic Brainfuck algorithms, games, fractals, and interpreters.

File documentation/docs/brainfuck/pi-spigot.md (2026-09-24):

# Unbounded Streaming π Spigot on Bare Silicon

This document details the architecture, mathematics, and hardware verification of an unbounded streaming π spigot executing in pure Brainfuck on the Brainfuino FPGA soft-processor.

Operating directly on bare silicon with a 128 kB SRAM memory tape and 12 MHz clock, the program emits continuous decimal digits of π in real-time without external floating-point libraries, operating systems, or runtimes.

---

## Downloads & Source Files

| File | Description | Download |
| :--- | :--- | :--- |
| **`pi_stream.b`** | Pure Brainfuck streaming binary (20,261 bytes, dynamic tape) | [Download `pi_stream.b`](../programs/pi/pi_stream.b){ .md-button } |
| **`generate_pi_stream.py`** | Python generator that synthesizes the spigot Brainfuck code | [Download `generate_pi_stream.py`](../programs/pi/generate_pi_stream.py){ .md-button } |
| **`run_pi.py`** | Hardware flasher & real-time digit verification runner | [Download `run_pi.py`](../programs/pi/run_pi.py){ .md-button } |

---

## 1. Mathematical Spigot Foundation

The algorithm is based on **Jeremy Gibbons' streaming spigot algorithm** (2004) using 2×2 integer matrices to represent Linear Fractional Transformations (LFTs):

$$\begin{pmatrix} q & r \\ s & t \end{pmatrix}(x) = \frac{q x + r}{s x + t}$$

Using the Lambert / Euler continued fraction expansion for π:

$$\pi = \begin{pmatrix} 1 & 0 \\ 0 & 1 \end{pmatrix} \prod_{k=1}^\infty \begin{pmatrix} k & 4k+2 \\ 0 & 2k+1 \end{pmatrix}(0)$$

Since the lower-left element s remains 0 throughout execution, the transformation simplifies to an upper-triangular state matrix (q, r, 0, t).

### Spigot Step Logic

At each iteration k ≥ 1 with state matrix (q, r, t):

1. **Extract Digit Candidate**:

    $$
    n = \lfloor (3q + r) / t \rfloor
    $$

2. **Refinement Check**:
    Test whether the interval bounds produce the same integer digit:

    $$
    4q + 2r - 2t < n \cdot t
    $$

3. **Branch A (Digit Produced)**:
    If the condition holds, digit n is confirmed:
    - Output ASCII digit n (`'0' + n`)
    - If this is the first digit, also output decimal point `.`
    - Scale matrix for base-10 streaming:

        $$
        q \leftarrow 10q, \quad r \leftarrow 10(r - n \cdot t)
        $$

4. **Branch B (Ingest Next Matrix)**:
    If the digit cannot yet be confirmed:
    - Ingest next term (k, 4k+2, 2k+1) where l = 2k+1:

        $$
        r \leftarrow q(4k+2) + r \cdot l, \quad t \leftarrow t \cdot l, \quad q \leftarrow q \cdot k, \quad l \leftarrow l + 2, \quad k \leftarrow k + 1
        $$

---

## 2. Multi-Precision Tape Memory Architecture

To handle numbers growing to thousands of decimal digits, memory is partitioned into **16-byte register slots** across the 128 kB SRAM tape (8,000 total slots available).

```text
[ Tape Cell 0..15: Global State Header ]
  Cell 0 : Zero boundary marker (always 0)
  Cell 1 : Streaming loop condition
  Cell 2-4: Global arithmetic scratch cells
  Cell 5 : k (current iteration, 8-bit)
  Cell 6 : l (odd factor 2k+1, 8-bit)
  Cell 7 : n (extracted digit candidate)
  Cell 8 : Comparison sign flag
  Cell 9 : Branch condition result
  Cell 10: Inverted branch flag
  Cell 11: Decimal point emitted flag
  Cell 12: Output ASCII character buffer
  Cell 13: Loop control
  Cell 14: Return pass comparison accumulator
  Cell 15: Scratch / temporary

[ Slot 0..N-1: 16-byte Multi-Precision BCD Register Slots ]
  Offset 0 : Active Slot Flag (1 = active slot, 0 = tape boundary)
  Offset 1 : q (decimal digit, 0..9)
  Offset 2 : r (decimal digit, 0..9)
  Offset 3 : t (decimal digit, 0..9)
  Offset 4 : TMP1 (scratch register A)
  Offset 5 : TMP2 (scratch register B)
  Offset 6 : CARRY (arithmetic carry / borrow)
  Offset 7 : SCRATCH1 (local register preservation)
  Offset 8 : SCRATCH2 (local division scratch)
  Offset 9 : DM_C (divmod constant 10 scratch)
  Offset 10: DM_T1 (divmod temporary 1)
  Offset 11: DM_T2 (divmod temporary 2)
  Offset 12: DM_Z (divmod zero-detect flag)
  Offset 13-15: Spare auxiliary scratch cells
```

---

## 3. Dynamic On-Demand Tape Expansion

Fixed-length tapes suffer from a fundamental trade-off: small tapes run quickly but run out of digits, while large tapes (like 8,000 slots) waste millions of clock cycles sweeping across empty memory.

The Brainfuino spigot solves this with **pure Brainfuck self-expansion**:

1. **Minimal Boot Allocation**:
   Execution starts with only **4 active slots** (64 bytes). Slot 4 has `FLAG = 0`.
2. **Carry Out Detection**:
   In `add_reg` and `mul_scalar_const`, when the forward pass exits the last active slot, the pointer lands on `slot_{last+1}`:
   - If `CARRY > 0`: an arithmetic overflow occurred.
   - `slot_{last+1}.FLAG` is set to 1.
   - The carry is moved into the destination register of `slot_{last+1}`.
   - `slot_{last+2}.FLAG` is cleared to 0.
3. **The 20-Byte Pure Brainfuck Conditional Advance Idiom**:
   ```brainfuck
   [ >>>>>>>>>>>>>>>> [-] ]
   ```
   - **If expansion occurred (`*ptr == 1`)**: loop enters, steps right 16 cells to the new inactive slot boundary, clears it to 0, and exits cleanly.
   - **If no expansion occurred (`*ptr == 0`)**: loop is skipped entirely.
   - In both cases, the pointer lands on the first inactive slot, allowing the exact same return sweep (`<16 [ <16 ]`) to step back to `Cell 0`.

This ensures **0% wasted cycles on inactive slots** while dynamically scaling up to the full 128 kB SRAM boundary.

---

## 4. Bare Silicon Hardware Benchmarks (`COM22` at 12 MHz)

Verified on physical Brainfuino hardware with the companion STM32 clock generator set to 12 MHz:

```text
=======================================================
HARDWARE EXECUTION SUMMARY
=======================================================
Target Program     : programs/pi/pi_stream.b (Dynamic Tape)
Code Size Flashed  : 20,261 bytes (Flash ROM: 256 kB)
Hardware Output    : 3.141592653
Expected Reference : 3.141592653

>>> [PASS] 100% HARDWARE VERIFICATION SUCCESSFUL!
>>> Computed 10 digits of Pi on bare FPGA silicon!

Digit Streaming Timeline:
  Digit '3': +0.00s (sub-millisecond boot!)
  Digit '.': +0.00s
  Digit '1': +0.05s
  Digit '4': +1.03s
  Digit '1': +1.46s
  Digit '5': +4.32s
  Digit '9': +10.89s
  Digit '2': +14.27s
  Digit '6': +21.33s
  Digit '5': +33.05s
  Digit '3': +40.67s
=======================================================
```

### Comparative Architecture Performance

| Metric / Digit | Fixed 8,000 Slots (128 kB) | Fixed 256 Slots (4 kB) | Dynamic Self-Expanding (4 → N) |
| :--- | :--- | :--- | :--- |
| **Startup / Boot Latency** | 42.84 s | 1.35 s | **< 0.05 s (Instantaneous)** |
| **Digit 1 (`3.1`)** | 101.67 s | 3.81 s | **0.05 s (2,033× faster!)** |
| **Digit 3 (`3.141`)** | ~220 s | 13.23 s | **1.46 s (150× faster!)** |
| **Digit 5 (`3.14159`)** | ~500 s | 50.26 s | **10.89 s (45× faster!)** |
| **Digit 9 (`3.141592653`)**| > 1,000 s | 120.54 s | **40.67 s (25× faster!)** |
| **Tape Capacity** | Fixed at 128 kB | Fixed at 4 kB | **Scales on demand up to 128 kB** |
| **Wasted Cycles** | 99.9% on early digits | 95% on early digits | **0% (Only active slots are swept)** |

---

## 5. Running on Your Brainfuino

### Using the Python Hardware Runner (Automated)

The automated runner connects to Brainfuino over USB CDC serial, streams the 20 kB code into SPI Flash ROM, resets the processor, and monitors the real-time digit stream:

```bash
# Flash and validate first 10 digits
python programs/pi/run_pi.py programs/pi/pi_stream.b --count 10 --timeout 60

# Run already-flashed program from Flash ROM without re-uploading
python programs/pi/run_pi.py programs/pi/pi_stream.b --run-only --count 15
```

### Using a Serial Terminal (Manual)

1. Connect Brainfuino to your PC via USB CDC serial (`COM22` on Windows, `/dev/ttyACM0` on Linux) at **115200 baud**.
2. If using Tera Term or PuTTY, send the contents of [`pi_stream.b`](../programs/pi/pi_stream.b) using the **Send File** feature.
3. Once transmission finishes, the companion STM32 automatically detects the end of the file, flashes the program into SPI Flash ROM, and resets the FPGA soft-processor to begin streaming digits.

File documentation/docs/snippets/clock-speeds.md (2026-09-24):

| Idx | Frequency | Generator / Prescaler | Period | Application / Timing Margin |
| :---: | :--- | :--- | :--- | :--- |
| `1` | **10 Hz** | TIM1 PWM (PSC: 47999, ARR: 99) | 100.0 ms | Human-speed instruction stepping, visually tracking register LEDs |
| `2` | **25 Hz** | TIM1 PWM (PSC: 47999, ARR: 39) | 40.0 ms | Ultra-slow execution, oscilloscope & visual debugging |
| `3` | **50 Hz** | TIM1 PWM (PSC: 47999, ARR: 19) | 20.0 ms | Very slow pacing |
| `4` | **100 Hz** | TIM1 PWM (PSC: 47999, ARR: 9) | 10.0 ms | Slow step-by-step program inspection |
| `5` | **250 Hz** | TIM1 PWM (PSC: 47999, ARR: 3) | 4.0 ms | Smooth slow-motion execution |
| `6` | **500 Hz** | TIM1 PWM (PSC: 47999, ARR: 1) | 2.0 ms | Low frequency inspection |
| `7` | **1 kHz** | TIM1 PWM (PSC: 479, ARR: 99) | 1.0 ms | 1 kHz clock baseline |
| `8` | **2 kHz** | TIM1 PWM (PSC: 479, ARR: 49) | 500.0 µs | Audio-frequency experimentation |
| `9` | **5 kHz** | TIM1 PWM (PSC: 479, ARR: 19) | 200.0 µs | Moderate low-speed execution |
| `10` | **10 kHz** | TIM1 PWM (PSC: 479, ARR: 9) | 100.0 µs | Logic analyzer trace verification |
| `11` | **25 kHz** | TIM1 PWM (PSC: 479, ARR: 3) | 40.0 µs | High PWM speed |
| `12` | **50 kHz** | TIM1 PWM (PSC: 479, ARR: 1) | 20.0 µs | **Maximum hardware PWM speed** (+19.9 µs ROM margin) |
| `13` | **62.5 kHz** | MCO HSI (8 MHz) / 128 | 16.0 µs | Ultra-slow MCO stepping |
| `14` | **125 kHz** | MCO HSI (8 MHz) / 64 | 8.0 µs | Slow visual stepping, watching I/O operations |
| `15` | **250 kHz** | MCO HSI (8 MHz) / 32 | 4.0 µs | Stepping and interactive algorithm inspection |
| `16` | **500 kHz** | MCO HSI (8 MHz) / 16 | 2.0 µs | **Default safe clock**, balanced speed for general programs |
| `17` | **750 kHz** | MCO HSI48 (48 MHz) / 64 | 1.33 µs | Intermediate speed |
| `18` | **1 MHz** | MCO HSI (8 MHz) / 8 | 1.0 µs | 1 MHz baseline |
| `19` | **1.5 MHz** | MCO HSI48 (48 MHz) / 32 | 666.7 ns | Intermediate speed |
| `20` | **2 MHz** | MCO HSI (8 MHz) / 4 | 500.0 ns | Smooth intermediate speed |
| `21` | **3 MHz** | MCO HSI48 (48 MHz) / 16 | 333.3 ns | Moderate speed |
| `22` | **4 MHz** | MCO HSI (8 MHz) / 2 | 250.0 ns | Fast execution |
| `23` | **6 MHz** | MCO HSI48 (48 MHz) / 8 | 166.7 ns | High speed |
| `24` | **8 MHz** | MCO HSI (8 MHz) / 1 | 125.0 ns | High speed execution |
| `25` | **12 MHz** | MCO HSI48 (48 MHz) / 4 | 83.3 ns | **Maximum safe speed** (+28 ns margin above 55 ns ROM limit) |

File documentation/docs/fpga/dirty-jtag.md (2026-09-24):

# DIY JTAG Programming with DirtyJTAG & openFPGALoader

You do not need an expensive proprietary ($300) Lattice hardware programmer to flash the Brainfuino. Any open-source or commercial JTAG adapter supported by **[openFPGALoader](https://trabucayre.github.io/openFPGALoader/compatibility/cable.html)** will work!

If you don't already own a dedicated JTAG debugger, you can turn a low-cost microcontroller board into a high-speed JTAG programmer using **DirtyJTAG**.

---

## Choosing a DIY JTAG Adapter

| Adapter Option | Typical Cost | Setup Complexity | Notes |
| :--- | :---: | :--- | :--- |
| **Raspberry Pi Pico** | ~$4 | **Extremely Easy (Recommended)** | Just drag-and-drop a `.UF2` firmware file onto the Pico over USB. |
| **STM32F103 "Blue Pill"** | ~$3 | Easy | Requires flashing firmware onto the Blue Pill using an ST-Link (~$6). |
| **FTDI / Commercial JTAG** | $10 – $30 | None | Directly supported by openFPGALoader out of the box. |

---

## 1. Setting Up the DirtyJTAG Firmware

### Option A: Raspberry Pi Pico (Recommended)
1. Download the pre-built `.UF2` firmware from the **[pico-dirtyJtag releases page](https://github.com/phdussud/pico-dirtyJtag/releases/tag/V1.07)**.
2. Hold down the `BOOTSEL` button on your Raspberry Pi Pico and plug it into your computer via USB.
3. Drag and drop the downloaded `.UF2` file onto the `RPI-RP2` mass storage drive.
4. The Pico will reboot automatically as an open-source DirtyJTAG programmer!

### Option B: STM32F103 "Blue Pill"
Follow the official **[DirtyJTAG Blue Pill installation guide](https://github.com/dirtyjtag/DirtyJTAG/blob/master/docs/install-bluepill.md)** to flash the firmware using an ST-Link programmer.

---

## 2. JTAG Header Wiring

Connect the jumper wires from your programmer directly to the 6-pin JTAG header on the Brainfuino (**Programmer &rarr; Brainfuino**):

### Option A: Raspberry Pi Pico (`pico-dirtyJtag`)

| JTAG Signal | Pico Pin Number | Pico GPIO | Brainfuino JTAG Pin | Description |
| :--- | :---: | :---: | :---: | :--- |
| **TCK** | **Pin 24** | GPIO18 | **TCK** | Test Clock |
| **TMS** | **Pin 25** | GPIO19 | **TMS** | Test Mode Select |
| **TDI** | **Pin 21** | GPIO16 | **TDI** | Test Data In |
| **TDO** | **Pin 22** | GPIO17 | **TDO** | Test Data Out |
| **GND** | **Pin 23 / 28** | GND | **GND** | Common Ground |
| **3.3V** | **Pin 36** | 3V3 (OUT) | **3.3V / VCC** | Target Logic Supply / Sense |

*(Note: Optional debug UART RX/TX on `pico-dirtyJtag` is GPIO12 / Pin 16 and GPIO13 / Pin 17).*

### Option B: STM32F103 "Blue Pill" (`DirtyJTAG`)

| JTAG Signal | Blue Pill Pin | Brainfuino JTAG Pin | Description |
| :--- | :---: | :---: | :--- |
| **TCK** | **PA0** | **TCK** | Test Clock |
| **TMS** | **PA1** | **TMS** | Test Mode Select |
| **TDI** | **PA2** | **TDI** | Test Data In |
| **TDO** | **PA3** | **TDO** | Test Data Out |
| **GND** | **GND** | **GND** | Common Ground |
| **3.3V** | **3.3V** | **3.3V / VCC** | Target Logic Supply / Sense |

---

## 3. Flashing with openFPGALoader (Linux)

This flashing method runs on Linux (e.g. Ubuntu / Debian):

### Install openFPGALoader
```bash
sudo apt update && sudo apt install openFPGALoader
```

*(For other Linux distributions or building from source, see the [openFPGALoader documentation](https://trabucayre.github.io/openFPGALoader/)).*

### Program the MachXO2 Bitstream
1. Obtain the compiled `.jed` bitstream file from [`brainfuck_uP-FPGA-softprocessor/bitstreams/`](https://github.com/m-archibald/Brainfuino/tree/main/brainfuck_uP-FPGA-softprocessor/bitstreams) (`brainfuino_v1.1.jed` for Rev 1.1 boards or `brainfuino_v1.0.jed` for Rev 1.0 boards).
2. Plug your DirtyJTAG programmer into your USB port and connect the JTAG wires to the Brainfuino.
3. Run the following command (substituting `brainfuino_v1.1.jed` or `brainfuino_v1.0.jed`):

```bash
openFPGALoader -c dirtyJtag -f brainfuino_v1.1.jed
```

*(If you are using a different programmer cable, replace `dirtyJtag` with your cable type, e.g. `ft2232`, `ft232RL`, etc.)*

### Verification

The utility will detect the MachXO2 FPGA, erase Flash, and stream the bitstream:

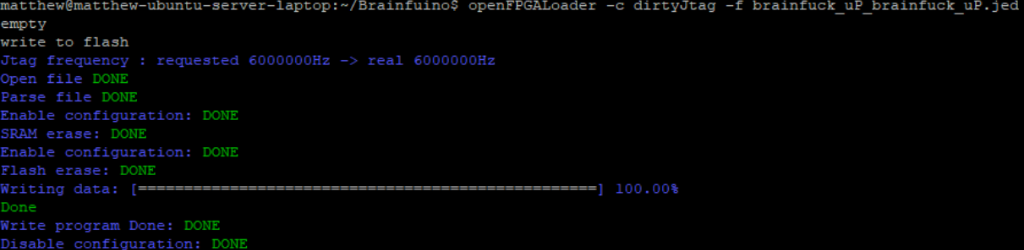
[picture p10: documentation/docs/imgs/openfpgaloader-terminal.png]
openFPGALoader programming the Brainfuino FPGA over DirtyJTAG


```text
write to flash
Jtag frequency : requested 60000000Hz -> real 60000000Hz
Open file DONE
Parse file DONE
Enable configuration: DONE
SRAM erase: DONE
Enable configuration: DONE
Flash erase: DONE
Writing data: [==================================================] 100.00%
Done
Write program Done: DONE
Disable configuration: DONE
```

Once you see `Disable configuration: DONE`, the FPGA is permanently programmed and ready to run!

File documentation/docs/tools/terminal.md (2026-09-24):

# Web Serial Terminal

The **Brainfuino Web Serial Terminal** allows you to connect directly to your Brainfuino from modern web browsers (Chrome, Edge, Opera, or Brave) using the **Web Serial API**—with zero software installation required.

<div class="grid cards" markdown="1">

-   [:octicons-link-external-16: **Open Dedicated Fullscreen Terminal**](web-terminal.html){ .md-button .md-button--primary target="_blank" }

    ---

    Launches the full-screen terminal interface with sidebar controls, quick speed toggles, and log downloading.

-   [:octicons-terminal-16: **CLI Runner**](../user-guide/quick-start.md)

    ---

    Prefer a command-line terminal? Use `python run_program.py` from your local terminal.

</div>

---

## Live Embedded Terminal

You can interact with your board right here inside the documentation:

<iframe src="../web-terminal.html" style="width: 100%; height: 750px; border: 1px solid var(--md-default-fg-color--lightest); border-radius: 12px; background: #ffffff;" allow="serial"></iframe>

---

## Supported Browsers & Setup

| Browser | Web Serial Support | Setup Required |
| :--- | :---: | :--- |
| **Google Chrome** | :material-check-circle: **Native** | None. Supported out of the box on Windows, Mac, Linux, and ChromeOS. |
| **Microsoft Edge** | :material-check-circle: **Native** | None. Works out of the box. |
| **Brave Browser** | :material-alert: **Permission Flag** | Brave blocks Web Serial by default. Navigate to `brave://settings/content/serialPorts` and allow sites to ask for permission, or enable the `#brave-commands` flag in `brave://flags`. |
| **Opera** | :material-check-circle: **Native** | None. Works out of the box. |
| **Firefox / Safari** | :material-close-circle: **Unsupported** | Mozilla and Apple have not yet implemented the Web Serial API. Please use a Chromium browser. |

---

## Features & Shortcuts

- **Universal Port Picker:** Click **Connect Brainfuino** to pick any available COM port.
- **Direct Keystroke Streaming:** Click inside the terminal to stream keystrokes directly to the FPGA (supports arrow keys, Backspace, Enter, and hotkeys).
- **Line Mode:** Type commands into the bottom bar and press `Enter` to send with configurable line endings (`LF`, `CR`, `CRLF`).
- **Hardware Quick Actions:**
    - `!RST`: Reset the FPGA soft-processor.
    - `!MENU`: Open the interactive VT100 configuration menu.
    - `1`–`7`: Dynamically switch clock speeds on the fly (500 kHz to 12 MHz).
- **Save Log:** Download the entire session output as a timestamped `.txt` file with one click.

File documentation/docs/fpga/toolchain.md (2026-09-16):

# FPGA Toolchain & Bitstream Generation

The FPGA project is built using **Lattice Diamond**, the official development environment for Lattice MachXO2 devices.

The source files and project configuration reside in [`brainfuck_uP-FPGA-softprocessor/`](https://github.com/m-archibald/Brainfuino/tree/main/brainfuck_uP-FPGA-softprocessor).

---

## Toolchain Requirements

* **Software:** [Lattice Diamond](https://www.latticesemi.com/latticediamond) (v3.11 or newer recommended).
* **License:** Lattice Diamond Free Node-Locked License (available free from Lattice Semiconductor).
* **Hardware Programmer:** Lattice HW-USBN-2A USB programmer, an FTDI-based JTAG cable, or a Raspberry Pi Pico running DirtyJTAG.

---

## Project Structure

Within `brainfuck_uP-FPGA-softprocessor/`:

* `brainfuck_uP.ldf`: The main Lattice Diamond project file.
* `brainfuck_uP.lpf`: Logical Preference File (pin assignments, I/O standards, and timing constraints).
* `brainfuck_uP/brainfuck_uP.xcf`: Pre-configured Lattice Programmer session file.
* `brainfuck_uP/source/brainfuck_uP.v`: The top-level Verilog module describing the CPU core, state machine, and memory buses.
* `brainfuck_uP/source/memory.v`: Memory interface simulation model.
* `brainfuck_uP/source/testing_brainfuck_uP.v`: Testbench harness for logic verification.

---

## Building the Bitstream (`.jed`)

1. Open **Lattice Diamond**.

2. Go to **File → Open → Project** and select `brainfuck_uP.ldf`.

3. In the **Process View** pane, verify the active target device parameters:
    * **Family:** MachXO2
    * **Device:** `LCMXO2-640HC`
    * **Package:** `TG100` (TQFP-100)
    * **Speed Grade:** `4`
    * **Synthesis Tool:** Lattice Synthesis Engine (`LSE`)

4. Verify that `brainfuck_uP.lpf` is the active constraint file.

5. In the Process pane, expand **Export Files** and check the box next to **JEDEC File** (or right-click and click **Run**).

6. Lattice Diamond will automatically execute the complete build flow:
    * **Synthesize Design (LSE):** Parses Verilog and synthesizes gates into MachXO2 LUT primitives.
    * **Translate Design (NGDBuild):** Merges primitives and constraints.
    * **Map Design:** Maps logic to physical slices, I/O banks, and clock trees.
    * **Place & Route Design (PAR):** Optimizes trace routes and checks timing limits.
    * **Generate JEDEC File:** Produces `brainfuck_uP/brainfuck_uP_brainfuck_uP.jed`.

---

## Flashing the MachXO2 FPGA

The Lattice MachXO2 features onboard non-volatile Flash configuration memory, meaning it retains its bitstream permanently across power cycles.

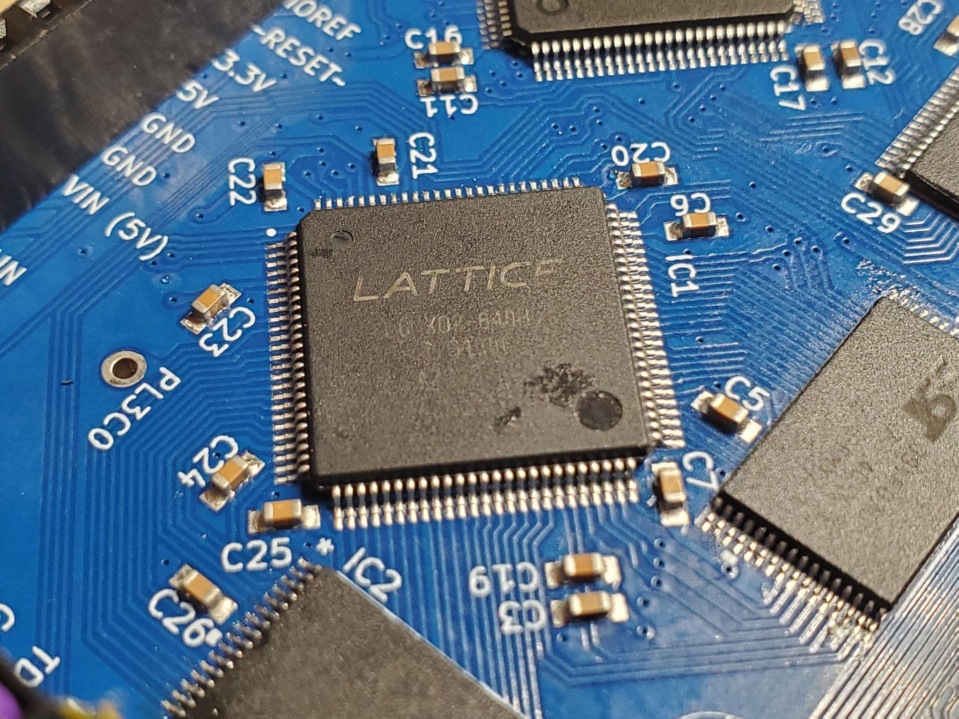
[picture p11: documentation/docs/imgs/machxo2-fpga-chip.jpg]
Lattice MachXO2 FPGA on the Brainfuino PCB


1. Connect your JTAG programmer to the 6-pin JTAG header on the Brainfuino board:
    * Pins: `TCK`, `TMS`, `TDI`, `TDO`, `GND`, `3.3V`

2. In Lattice Diamond, go to **Tools → Programmer** (or open the pre-configured project file `brainfuck_uP/brainfuck_uP.xcf`).

3. In Programmer:
    * Click **Detect Cable** and select your connected USB programmer.
    * Click **Scan** to detect the connected `LCMXO2-640HC` device.

4. Ensure the device operation is configured as:
    * **Access Mode:** `Flash Programming Mode`
    * **Operation:** `FLASH Erase,Program,Verify`
    * **File:** Browse to `brainfuck_uP/brainfuck_uP_brainfuck_uP.jed`

5. Click **Program** (the green icon) in the toolbar.

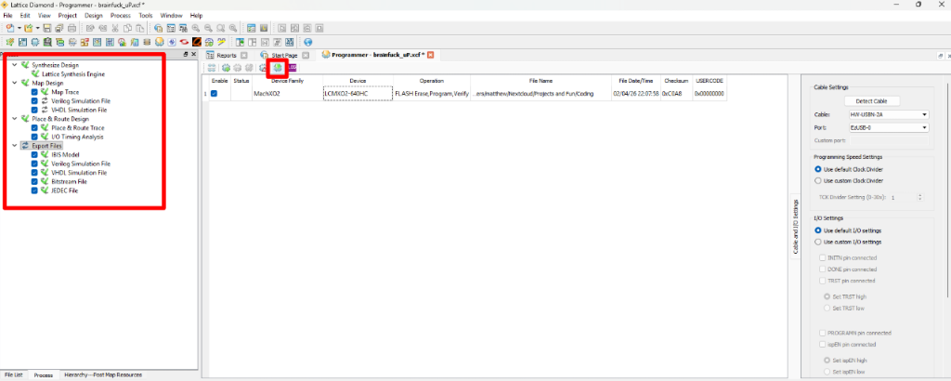
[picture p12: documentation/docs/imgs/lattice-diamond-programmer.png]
Lattice Diamond Synthesis and Programmer Session
    

6. Once the status bar turns green (**PASS**), the FPGA is configured and ready to execute native Brainfuck!

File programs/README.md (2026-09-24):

# Brainfuino Example Programs Catalog

A collection of tested, hardware-verified Brainfuck programs for the **Brainfuino** native hardware Brainfuck computer (Lattice MachXO2 FPGA soft-processor + STM32 coprocessor).

---

## Directory Structure

```text
programs/
├── basic/
│   ├── banner.b          # Official Brainfuino ASCII text art banner (1.3 kB)
│   ├── hello.b           # Classic benchmark Hello World with comments (0.8 kB)
│   └── echo.b            # Interactive character echo via serial UART (5 bytes)
├── fractals/
│   ├── sierpinski.b      # 80-column Sierpinski triangle by NYYRIKKI (1.3 kB)
│   └── mandelbrot.b      # ASCII Mandelbrot set renderer by Erik Bosman (11.6 kB)
├── math/
│   ├── fibonacci.b       # Unbounded decimal Fibonacci generator by Daniel B. Cristofani (247 B)
│   ├── golden.b          # Infinite streaming Golden Ratio by Daniel B. Cristofani (375 B)
│   └── factorial.b       # Arbitrary-precision factorial generator by Daniel B. Cristofani (554 B)
├── games/
│   └── life.b            # Conway's Game of Life by Daniel B. Cristofani / Linus Åkesson (760 B)
└── pi/
    ├── pi_stream.b       # Dynamic self-expanding streaming Pi spigot (20.2 kB)
    ├── generate_pi_stream.py # Pure Brainfuck spigot code generator
    └── run_pi.py         # Hardware flasher & real-time digit validation runner
```

---

## How to Flash to Hardware

### Method 1: Paste directly into Serial Terminal
For short-to-medium programs (`banner.b`, `hello.b`, `echo.b`, `sierpinski.b`, `fibonacci.b`, `golden.b`, `factorial.b`, `life.b`):
1. Connect Brainfuino via USB CDC serial (`COM22` on Windows, `/dev/ttyACM0` on Linux) at **115200 baud**.
2. Copy and paste the raw Brainfuck code directly into your terminal emulator (Tera Term, PuTTY, minicom).
3. The companion STM32 automatically buffers the incoming code, flashes it to memory, and launches execution on the FPGA soft-processor.

### Method 2: Flash via Python Hardware Runner
For large programs like `pi_stream.b` or `mandelbrot.b`:
```bash
python programs/pi/run_pi.py programs/fractals/mandelbrot.b --count 20 --timeout 120
python programs/pi/run_pi.py programs/pi/pi_stream.b --count 10 --timeout 60
```

---

## Program Details & Verified Sources

### 1. Basic Demos (`programs/basic/`)
* **`banner.b`** (1,348 bytes)
    * **Description:** Emits the official Brainfuino ASCII text banner over serial.
    * **Author:** Brainfuino Project
* **`hello.b`** (779 bytes)
    * **Description:** Canonical benchmark edition of Hello World featuring comments that skip non-operator characters.
    * **Source:** [cwfitzgerald/brainfuck-benchmark](https://github.com/cwfitzgerald/brainfuck-benchmark/blob/master/benches/hello.b)
* **`echo.b`** (5 bytes)
    * **Description:** Character echo loop `, [ . , ]` testing bidirectional serial UART I/O.
    * **Author:** Urban Müller (1993)

### 2. Fractals (`programs/fractals/`)
* **`sierpinski.b`** (1,327 bytes)
    * **Description:** Computes and renders a 32-line Sierpinski fractal pattern across an 80-column display.
    * **Author:** NYYRIKKI (2002)
    * **Source:** [Brainfuck Community Archive](https://esolangs.org/wiki/Brainfuck#Sierpinski_triangle)
* **`mandelbrot.b`** (11,669 bytes)
    * **Description:** ASCII Mandelbrot set renderer testing deep nested loops, 16-bit register arithmetic, and high-frequency output throttling.
    * **Author:** Erik Bosman (2004)
    * **Source:** [kostya/benchmarks/mandel.b](https://github.com/kostya/benchmarks/blob/master/brainfuck/mandel.b) / [frerich/brainfuck](https://github.com/frerich/brainfuck/blob/master/samples/mandelbrot.bf)

### 3. Mathematical Sequences (`programs/math/`)
* **`fibonacci.b`** (247 bytes)
    * **Description:** Generates and outputs an unbounded stream of multi-precision decimal Fibonacci numbers (0, 1, 1, 2, 3, 5, 8, 13, 21, 34, ...).
    * **Author:** Daniel B. Cristofani
    * **Source:** [Daniel B. Cristofani's fib.b (brainfuck.org)](http://www.brainfuck.org/fib.b)
* **`golden.b`** (375 bytes)
    * **Description:** Computes and streams the digits of the Golden Ratio (φ = 1.6180339887...) continuously in decimal.
    * **Author:** Daniel B. Cristofani (2019)
    * **Source:** [Daniel B. Cristofani's golden.b (brainfuck.org)](http://www.brainfuck.org/golden.b)
* **`factorial.b`** (554 bytes)
    * **Description:** Arbitrary-precision factorial generator emitting 1!, 2!, 3!, 4!, ... in decimal with newline separation.
    * **Author:** Daniel B. Cristofani (2019)
    * **Source:** [Daniel B. Cristofani's factorial2.b (brainfuck.org)](http://www.brainfuck.org/factorial2.b)

### 4. Interactive Games (`programs/games/`)
* **`life.b`** (760 bytes)
    * **Description:** John Horton Conway's Game of Life 2D cellular automaton with a 10×10 toroidal grid. Enter coordinates (e.g. `be`) to toggle cells, or send a bare newline to advance generations.
    * **Author:** Daniel B. Cristofani (2021) based on the interface by Linus Åkesson (2007)
    * **Source:** [Daniel B. Cristofani's life.b (brainfuck.org)](http://www.brainfuck.org/life.b) / [Linus Åkesson's Game of Life](http://www.linusakesson.net/programming/brainfuck/index.php)

### 5. Streaming π Spigot (`programs/pi/`)
* **`pi_stream.b`** (20,261 bytes)
    * **Description:** Unbounded streaming π spigot based on Jeremy Gibbons' Linear Fractional Transformation (LFT) matrix algorithm.
    * **Dynamic On-Demand Tape:** Starts with 4 active slots (64 bytes) for sub-millisecond boot and dynamically expands across 128 kB SRAM (up to 8,000 slots) on carry propagation.
    * **Source:** [Brainfuino Pi Spigot Architecture](../documentation/docs/brainfuck/pi-spigot.md)

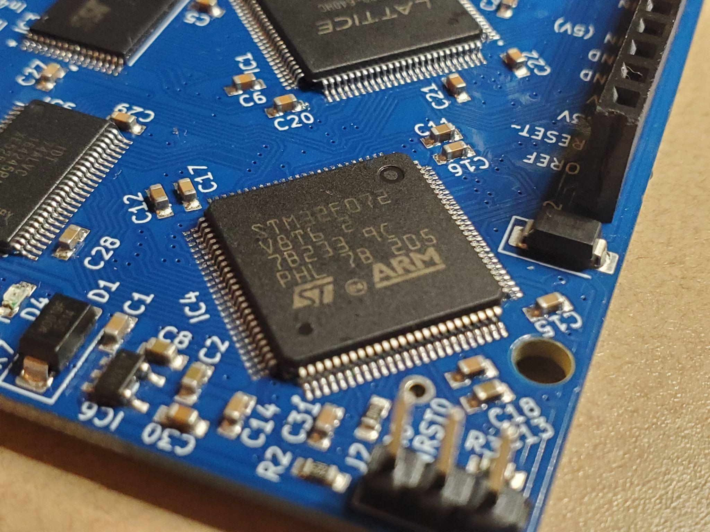
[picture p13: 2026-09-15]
documentation/docs/imgs/stm32-board-closeup.jpg

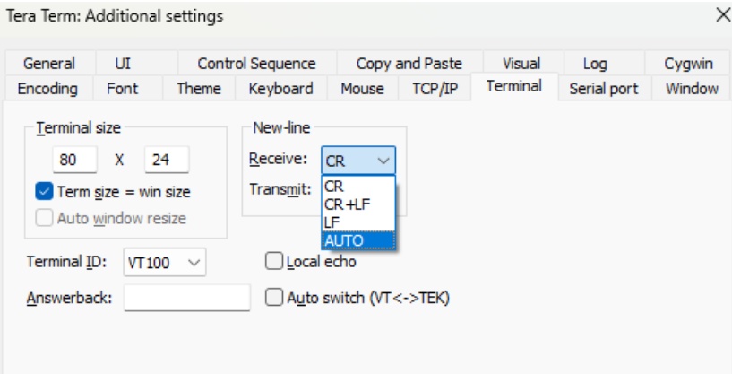
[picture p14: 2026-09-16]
documentation/docs/imgs/teraterm-newline-settings.jpg

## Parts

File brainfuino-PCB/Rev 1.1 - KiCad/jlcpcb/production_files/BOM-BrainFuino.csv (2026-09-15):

Comment | Designator | Footprint | LCSC | Quantity
0.1uF | C10,C14,C15,C16,C17,C26,C27,C28,C29,C3,C31,C4,C9 | 0603 | C14663 | 13
1.0uF | C13,C2,C8 | 0603 | C15849 | 3
100k | R3 | 0603 | C25803 | 1
10nF | C18,C19,C20,C21,C22,C23,C24,C25,C30,C5,C6,C7 | 0603 | C57112 | 12
10uF | C1 | 0603 | C19702 | 1
22k | R2 | 0603 | C31850 | 1
4.7k | R4,R5 | 0603 | C23162 | 2
4.7uF | C11,C12 | 0603 | C19666 | 2
5.1k | R7,R8 | R_0603_1608Metric | C23186 | 2
680 | R6 | 0603 | C23212 | 1
74ALVC164245PAG8 | IC5 | SOP50P810X120-48N | C2677360 | 1
CY62128EV30LL-45AXI | IC2 | TSOP-32 | C2944685 | 1
GREEN | D3 | LED-0603 | C2290 | 1
LCMXO2-640HC-4TG100C | IC1 | QFP50P1600X1600X160-100N | C1519051 | 1
RED | D4 | LED-0603 | C2286 | 1
RESET | S1 | TACTILE_SWITCH_SMD_6.2MM_TALL | C2909692 | 1
SPX3819M5_3_3 | IC6 | SOT23-5 | C9055 | 1
SS12 | D1,D2 | D_SMA | C2480 | 2
SST39LF020-55-4C-WHE | IC3 | TSOP32_WH_SST | C630573 | 1
STM32F072V8T6 | IC4 | QFP50P1600X1600X160-100N | C125825 | 1
USB_C_Receptacle_USB2.0_16P | J1 | USB_C_Receptacle_HRO_TYPE-C-31-M-12 | C165948 | 1

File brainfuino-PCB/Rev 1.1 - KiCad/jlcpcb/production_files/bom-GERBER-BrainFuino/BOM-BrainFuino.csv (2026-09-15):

Comment | Designator | Footprint | LCSC | Quantity
0.1uF | C10,C14,C15,C16,C17,C26,C27,C28,C29,C3,C4,C9 | 0603 | C1591 | 12
1.0uF | C13,C2,C8 | 0603 | C15849 | 3
100 | R6 | 0603 | C22775 | 1
100k | R1,R3 | 0603 | C25803 | 2
10nF | C18,C19,C20,C21,C22,C23,C24,C25,C30,C5,C6,C7 | 0603 | C57112 | 12
10uF | C1 | 0603 | C19702 | 1
1981568-1 | J1 | CONN5_1981568-1_TEC | C428487 | 1
22k | R2 | 0603 | C25768 | 1
330 | R5 | 0603 | C23138 | 1
3A/10V/280mV | D1,D2 | SOD-323 | C7502697 | 2
4.7k | R4 | 0603 | C25900 | 1
4.7uF | C11,C12 | 0603 | C19666 | 2
74ALVC164245PAG8 | IC5 | SOP50P810X120-48N | C2677360 | 1
CY62128EV30LL-45AXI | IC2 | TSOP-32 | C2944685 | 1
GREEN | D3 | LED-0603 | C2290 | 1
LCMXO2-640HC-4TG100C | IC1 | QFP50P1600X1600X160-100N | C1519051 | 1
RED | D4 | LED-0603 | C2286 | 1
RESET | S1 | TACTILE_SWITCH_SMD_6.2MM_TALL | C318884 | 1
SPX3819M5_3_3 | IC6 | SOT23-5 | C9055 | 1
SST39LF020-55-4C-WHE | IC3 | TSOP32_WH_SST | C630573 | 1
STM32F072V8T6 | IC4 | QFP50P1600X1600X160-100N | C125825 | 1

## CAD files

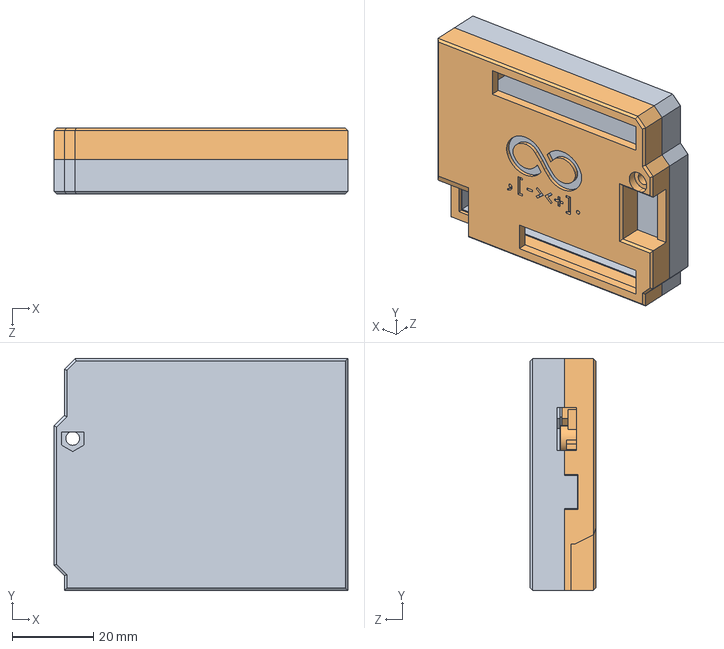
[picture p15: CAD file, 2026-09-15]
3D-printable-case/BrainFuinoCase.STEP
72.4 x 57.2 x 16.3 mm

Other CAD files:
3D-printable-case/BrainFuinoCase.SLDPRT

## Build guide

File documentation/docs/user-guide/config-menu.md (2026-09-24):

# Interactive Configuration Menu & Program Library

The Brainfuino coprocessor includes a rich, multi-page interactive text configuration menu (reminiscent of Raspberry Pi's `raspi-config`). It allows you to manage an onboard **Program Library** stored directly in the STM32's internal Flash, tune FPGA clock frequencies, customize upload thresholds and character pruning, configure runtime hotkeys, restore the default factory demo, or soft-reboot into the STM32 USB DFU bootloader without touching hardware jumpers.

---

## Accessing the Menu

You can enter the Configuration Menu at any time using either the hardware button or serial terminal:

=== "Physical Hardware Button"
    1. Press and hold the **Reset Button** on the Brainfuino.
    2. At **1 second**, the Red LED turns solid ON (Dedicated Program Mode threshold).
    3. Keep holding! At **3 seconds**, the Red LED begins **smoothly breathing / pulsing** (Settings Menu threshold).
    4. **Release the button** during this breathing window (between 3s and 8s).
    5. The soft-processor halts in reset, the Red LED pulses continuously, and the configuration menu appears in your terminal.
    6. *(Holding past **8 seconds** triggers a rapid LED strobe and restores the burned-in factory demo).*

=== "Serial Terminal Command"
    * While running, send either of the following commands:
      ```text
      !MENU
      ```
      or
      ```text
      !CONFIG
      ```
    * The menu will immediately render on your screen.

---

## Multi-Page Menu Architecture

The menu interface is divided into a **Main Menu** and dedicated submenus for **Program Library** management and **Hardware Settings**:

### Main Menu
```text
+-------------------------------------------------+
|          BRAINFUINO CONFIGURATION MENU          |
+-------------------------------------------------+
|  Use [Up/Down] & [Enter], or type [1-5, 0]      |
+-------------------------------------------------+
| > 1. Program Library         : [ ENTER -->] < |
|   2. Hardware Settings       : [ ENTER -->]   |
|   3. Reboot to USB DFU       : [   BOOT   ]   |
|   4. Restore Factory Demo    : [  FLASH   ]   |
|   5. Save & Exit             : [   EXIT   ]   |
|   0. Exit without Saving     : [ CANCEL   ]   |
+-------------------------------------------------+
|  Hardware: STM32F072 | Parallel ROM: 256 kB     |
+-------------------------------------------------+
Select option or use arrows + Enter: 
```

### Submenu 1: Program Library
```text
+-------------------------------------------------+
|            BRAINFUINO PROGRAM LIBRARY           |
+-------------------------------------------------+
| [Enter/L] Run [A] Add [D] Dump [X] Del [0] Back |
+-------------------------------------------------+
| > 00. Brainfuino Demo               [  1.6kB] < |
|   01. Mandelbrot                    [ 11.2kB]   |
|   02. Game of Life                  [  4.8kB]   |
|   [ + Add New Program ]                         |
|   0. Back to Main Menu             [   BACK   ] |
+-------------------------------------------------+
|  Library:  2 / 63 Programs | Used: 16.0 / 76 kB |
+-------------------------------------------------+
Select program [Enter/L=Run, A=Add, D=Dump, X=Del, 0=Back]: 
```

### Submenu 2: Hardware Settings
```text
+-------------------------------------------------+
|          BRAINFUINO HARDWARE SETTINGS           |
+-------------------------------------------------+
|  Use [Up/Down], [Left/Right], [Enter], or [1-9] |
+-------------------------------------------------+
| > 1. Auto-Program on Paste   : [ ENABLED  ] < |
|   2. Paste Upload Threshold  : [   16 B   ]   |
|   3. Auto-Reset after Flash  : [ ENABLED  ]   |
|   4. Append Endless Loop     : [  [-]+[]  ]   |
|   5. Prune non-BF on Paste   : [ ENABLED  ]   |
|   6. Prune non-BF in Library : [ ENABLED  ]   |
|   7. FPGA Clock Frequency    : [ 500 kHz  ]   |
|   8. Run Mode Speed Hotkeys  : [ PgUp/Dn  ]   |
|   9. Manual Stepping Mode    : [ DISABLED ]   |
|   0. Back to Main Menu       : [   BACK   ]   |
+-------------------------------------------------+
|  Hardware: STM32F072 | Parallel ROM: 256 kB     |
+-------------------------------------------------+
Select option or use arrows + Enter: 
```

*(When **Manual Stepping Mode** is set to `ENABLED`, options `A. Step Advance Ticks` and `B. Step Trigger Key` dynamically appear before option `0`).*

---

## Dual-Mode Navigation Controls

The menu architecture uses a hybrid parser supporting both modern rich terminal emulators and basic line-oriented serial monitors:

| Control | Modern Terminals (Tera Term, PuTTY, minicom) | Basic Terminals (Arduino Serial Monitor) |
| :--- | :--- | :--- |
| **Navigate Up / Down** | :material-arrow-up: Up Arrow / :material-arrow-down: Down Arrow | Type item number and press Send |
| **Cycle Option Forward** | :material-arrow-right: Right Arrow, :material-keyboard-space: Spacebar, or :material-keyboard-return: Enter | Type item number and press Send |
| **Cycle Option Backward** | :material-arrow-left: Left Arrow | — |
| **Direct Select / Enter** | Numbers `1` – `9`, `A` / `B` | Numbers `1` – `9`, `A` |
| **Dump Program Source (Library)**| `d` or `D` on highlighted slot | Type `d` and press Send |
| **Delete Program (Library)**| `x`, `X`, or `Delete` key on highlighted slot | Type `x` and press Send |
| **Add Program (Library)** | `a` or `A`, or select `[ + Add New Program ]` | Type `a` and press Send |
| **Return / Cancel / Exit**| `0`, `q`, `Q`, or `ESC` | `0` or `q` |
| **Hardware Button Exit** | Quick tap (< 3s) on Reset Button | Quick tap (< 3s) on Reset Button |

---

## Onboard Program Library

The STM32 internal Flash features a dedicated **76 kB storage partition** and a **64-slot Table of Contents (TOC)** allowing you to upload, name, store, verify, and run multiple Brainfuck programs on demand.

### 1. Running a Stored Program
From the **Program Library** submenu:
1. Use Up/Down arrows to highlight the desired program (or type its two-digit slot number).
2. Press **Enter** (or `l` / `L`).
3. The STM32 provides full visual feedback matching terminal pasting:
   * Displays program title and size.
   * Reports parallel Flash ROM erasure progress.
   * Streams 0–100% writing progress bar.
   * Performs readback verification (`Verifying ROM... OK!`).
   * Pulses the FPGA reset line and auto-launches program execution cleanly.

### 2. Adding a New Program
1. Select `[ + Add New Program ]` (or press `a` / `A`).
2. **Program Name:** Enter a custom name up to 15 characters (e.g. `Mandelbrot`) and press Enter.
3. **Paste Code:** The terminal prompts:
   ```text
   Preparing scratchpad... Ready.
   Paste Brainfuck code now (press Enter or pause 100ms when done)...
   ```
   Paste your Brainfuck code. If `Prune non-BF in Library` is enabled, all non-Brainfuck characters (comments, spaces, newlines) are stripped in real-time.
4. **Pruning Statistics & Pre-Run Verification Prompt:**
   Upon paste completion, the coprocessor displays exact pruning metrics:
   ```text
   Received 11264 valid bytes.
   [Prune Stats: Received 15300 B | Kept 11264 B | Saved 26.3% non-BF comments]
   Run on FPGA to verify before saving? [Y/n]: 
   ```
   * **Skip Verification (`n` or `N`):** Immediately commits the program to internal Flash without running.
   * **Verify on FPGA (`y`, `Y`, or Enter):** Immediately launches execution on the FPGA soft-processor. Program characters stream live to the terminal while a 10-second countdown runs:
     * **Abort / Cancel:** Press the hardware Reset Button or send `!RST` within 10 seconds. The program is discarded and parallel ROM is restored to the factory demo.
     * **Confirm Early:** Press **Enter** to save immediately before 10 seconds elapse.
     * **Auto-Save:** If no reset occurs within 10 seconds, the program auto-saves to internal Flash:
       ```text
       [10s Verification Elapsed: Auto-saving to Library...]
       [SUCCESS: Saved to Slot 01: 'Mandelbrot' (11264 bytes)]
       ```

### 3. Interactive Capacity Management & Defrag Progress
* **Scratchpad Architecture:** Incoming programs stream into the 256 kB external parallel Flash ROM as a fast scratchpad, allowing programs up to 256 kB to be pasted without exceeding STM32 internal RAM limits.
* **Insufficient Pool Space Warning:** If a pasted program exceeds remaining space in the 76 kB library pool, the coprocessor displays a warning listing active programs and prompts:
  ```text
  [Warning: Program requires 11264 B, but only 4096 B free (need 7168 B more)]
  Active programs that can be deleted to make room:
    Slot 01: TestGame        [8192 B]
  Type slot number to delete, or [0] to cancel: 
  ```
  Typing a slot number instantly deletes it and rechecks space. Once sufficient space is freed, the program proceeds directly to saving—**no re-pasting required!**
* **Defragmentation / Compaction Progress:** When active programs must be packed forward to create contiguous space, the coprocessor reports each program shifted and displays rewriting progress:
  ```text
  [Contiguous space needed: Defragmenting Library Partition...]
    Compacting Slot 01: 'Mandelbrot' (11264 B)...
    Compacting Slot 02: 'GameOfLife' (4800 B)...
  Rewriting Flash pool... Done.
  [Compaction complete: Active programs packed forward]
  ```
* **Tombstone Deletion (`x`):** Highlighting any user program (slots 01–63) and pressing `x`, `X`, or the `Delete` key immediately marks its status as deleted (`0x0000`). This takes **0 page erasures**, preserving Flash endurance.
* **Program Source Code Dumping (`d`):** Highlighting any program (including `00. Brainfuino Demo`) and pressing `d` or `D` dumps its raw Brainfuck source code directly to the serial terminal. Pressing any key returns smoothly to the Program Library menu.
* **Slot 00 Protection:** Slot `00. Brainfuino Demo` is permanently burned-in and cannot be deleted or overwritten.

---

## Configurable Hardware Options

### 1. Auto-Program on Paste
* **Options:** `ENABLED` *(default)*, `DISABLED`
* **Description:** When enabled, pasting Brainfuck code in standard Run Mode automatically transitions to Program Mode and flashes the new code to parallel ROM. When disabled, code uploads can only occur after deliberately entering Dedicated Program Mode (via 3-second button hold).

### 2. Paste Upload Threshold
* **Options:** `4 B`, `8 B`, `16 B` *(default)*, `32 B`, `64 B`
* **Description:** The minimum byte burst size required to trigger auto-programming. Setting this to 16 bytes or higher ensures that terminal escape sequences (such as arrow keys `\x1b[A`, Home `\x1b[1~`, or function keys) are never misinterpreted as code uploads while interacting with running Brainfuck programs.

### 3. Auto-Reset after Flash
* **Options:** `ENABLED` *(default)*, `DISABLED`
* **Description:** When enabled, the STM32 automatically un-resets the FPGA soft-processor and launches execution immediately upon completion of code writing. When disabled, the firmware holds the soft-processor halted until you press the hardware Reset Button.

### 4. Append Endless Loop
* **Options:** `[-]+[]` *(default)*, `NONE`
* **Description:** Automatically appends the robust Brainfuck halt idiom (`[-]+[]`) to the end of your program. This prevents the FPGA Program Counter from marching through unprogrammed ROM space (`0xFF`) and restarting at address `0`.
* **Recommendation:** Keep this enabled (`[-]+[]`). With this setting on, you do not need to append manual halt loops to your Brainfuck programs; standard Brainfuck programs will halt cleanly upon completion.

### 5. Prune non-BF on Paste
* **Options:** `ENABLED` *(default)*, `DISABLED`
* **Description:** When enabled, non-Brainfuck characters (comments, tabs, spaces, newlines) are automatically filtered out during direct paste uploads in Run Mode and Dedicated Program Mode, ensuring only valid instructions (`+`, `-`, `<`, `>`, `[`, `]`, `.`, `,`) are written to parallel ROM.

### 6. Prune non-BF in Library
* **Options:** `ENABLED` *(default)*, `DISABLED`
* **Description:** When enabled, non-Brainfuck characters are stripped during uploads to the internal Flash **Program Library**, maximizing storage density across the 76 kB pool.

### 7. FPGA Clock Frequency
* **Options (25 Speeds):**
  * **Ultra-Low Frequencies (TIM1 PWM):** `10 Hz`, `25 Hz`, `50 Hz`, `100 Hz`, `250 Hz`, `500 Hz`, `1 kHz`, `2 kHz`, `5 kHz`, `10 kHz`, `25 kHz`, `50 kHz`
  * **Standard & High Frequencies (MCO):** `62.5 kHz`, `125 kHz`, `250 kHz`, `500 kHz` *(default)*, `750 kHz`, `1 MHz`, `1.5 MHz`, `2 MHz`, `3 MHz`, `4 MHz`, `6 MHz`, `8 MHz`, `12 MHz`
* **Description:** Selects the master clock frequency fed to the MachXO2 FPGA soft-processor. Clock signals ≤ 50 kHz are generated by hardware timer `TIM1_CH1` (AF2 on PA8) in 50% PWM mode, providing clean square waves down to 10 Hz with 0% CPU overhead. Frequencies ≥ 62.5 kHz are generated via the STM32 Master Clock Output (`MCO`) pin using HSI/HSI48 clock dividers.
* **Silicon Timing Limit:** The parallel Flash ROM on Brainfuino (`SST39LF020-55`) has a maximum address access time of 55 ns (18.18 MHz theoretical maximum). **12 MHz** (83.3 ns cycle) is the maximum safe operating speed with +28 ns timing margin.

### 8. Run Mode Speed Hotkeys
* **Options:** `PgUp/Dn` *(default)*, `Up/Down`, `+ / -`, `NONE`
* **Description:** Allows dynamically stepping clock speeds up or down across all 25 frequencies during live program execution in Run Mode without entering the configuration menu. When a speed change occurs, a transient dimmed HUD indicator is displayed:
  ```text
  [Clock: 50 kHz]
  ```
* **Wear-Leveling Delayed Save:** Changes made via hotkeys use a **3-second debounce timer** before saving to internal Flash Page 63, preventing flash wear during rapid speed adjustments.

### 9. Manual Stepping Mode
* **Options:** `DISABLED` *(default)*, `ENABLED`
* **Description:** When enabled, the FPGA master clock is **halted by default in Run Mode**. Toggling this setting to `ENABLED` dynamically reveals sub-options **A** and **B** in the hardware settings menu:
  * **A. Step Advance Ticks:** `1 Tick`, `10 Ticks`, `100 Ticks` *(default)*, `1k Ticks`, `10k Ticks`, `100k Ticks`
  * **B. Step Trigger Key:** `Spacebar` *(default)*, `Tab`, `Enter`
* **Queueing / Tick Piling Behavior:** If the trigger key is held down or spammed rapidly, keystroke bursts accumulate in a pending tick queue and drain continuously without dropping a single clock cycle. All generated program characters stream out to the terminal in real time.

---

## Main Menu Actions

### 3. Reboot to USB DFU
* **Description:** Soft-resets the STM32 directly into the factory system memory USB DFU bootloader without touching hardware boot jumpers. Firmware can then be updated using `dfu-util` or STM32CubeProgrammer.

### 4. Restore Factory Demo
* **Description:** Immediately erases parallel Flash ROM, writes the built-in official Brainfuino ASCII logo banner demo from internal Flash, and restarts execution.

### 5. Save & Exit
* **Description:** Commits all modified hardware settings to internal Flash Page 63, exits the configuration menu, turns off the pulsing Red LED, and pulses the FPGA reset line to resume execution cleanly. On reset, prints:
  ```text
  [bf_µP reset] 500 kHz
  ```

### 0. Exit without Saving
* **Description:** Discards any pending hardware setting modifications and resumes execution without touching Flash Page 63.

---

## STM32 Internal Memory Map

The STM32F072's 128 kB internal Flash is cleanly organized into non-overlapping partitions:

| Range | Pages | Size | Purpose |
| :--- | :---: | :---: | :--- |
| `0x08000000` – `0x08013FFF` | 0 – 39 | 80 kB | **STM32 Firmware Application Code** |
| `0x08014000` – `0x080147FF` | 40 | 2 kB | **Library Table of Contents (TOC)** (64 slots × 32 B) |
| `0x08014800` – `0x0801F7FF` | 41 – 62 | 44 kB | **Library Program Payload Pool** (Dynamic allocation) |
| `0x0801F800` – `0x0801FFFF` | 63 | 2 kB | **Persistent Hardware Configuration** (Page 63) |

---

## Automated Hardware Verification Suite

The entire multi-page menu, program library partition, TOC engine, and navigation workflows are continuously validated on physical hardware using an automated Python test harness:

* **Script:** [`scripts/test_library_and_menu.py`](https://github.com/m-archibald/Brainfuino/blob/main/scripts/test_library_and_menu.py)
* **Execution:**
  ```powershell
  python scripts/test_library_and_menu.py
  ```
* **Coverage (10 Automated Verification Stages):**
  1. **Main Menu Rendering:** Verifies banner, framing, options 1–5, and 0.
  2. **Hardware Settings Submenu:** Validates all configuration entries, including both pruning toggles.
  3. **Left/Right Arrow Cycling:** Confirms bidirectional setting value cycling with VT100 escape codes.
  4. **Menu Navigation:** Tests back navigation (`0` key) and state persistence.
  5. **Program Library Listing:** Verifies TOC rendering, slot allocations, and capacity gauges.
  6. **Program Addition & Pruning:** Uploads code with comments, verifies comment stripping, and tests skipping pre-run verification (`n`).
  7. **Dynamic TOC Updating:** Confirms program name and byte size register in the Table of Contents.
  8. **Execution from Flash:** Loads the newly saved program into parallel ROM and verifies execution on the FPGA soft-processor.
  9. **Zero-Erase Tombstone Deletion:** Tests instant program deletion (`d` key) and confirms freed slot recovery.
  10. **Factory Restore:** Validates restoring the burned-in demo banner to parallel Flash.

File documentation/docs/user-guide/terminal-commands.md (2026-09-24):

# Terminal Commands & Interactive Controls

The FPGA soft-processor (`brainfuck_uP`) is pure hardware. It doesn't have a USB stack, an operating system, or a serial terminal interface. If you ran the FPGA standalone, you would need an external programmer to burn ROM chips, a function generator to pump clock signals, and a logic analyzer just to see your program's output.

To make the system actually user-friendly, the Brainfuino includes an **STM32F072 ARM Cortex-M0 coprocessor**. The STM32 acts as the FPGA's dedicated digital butler: generating clock signals, managing USB Virtual COM communication, writing programs to Flash, and translating parallel FPGA pulses into readable serial characters.

---

## Single-Key Shortcuts

When you send an individual character (payload length under 3 bytes), the STM32 intercepts it and performs the following actions:

### Clock Frequency Selection (Keys `1` – `7`)

--8<-- "snippets/clock-speeds.md"

### System Commands (Prefix `!`)

| Command | Action | Description |
| :---: | :--- | :--- |
| `!RESET` / `!RST` | Reset FPGA | Pulses the FPGA soft-processor reset line (`BF_RST`) and announces `[bf_µP reset] <speed>`. |
| `!DFU!` | Software DFU Reboot | Reboots STM32 into built-in USB DFU Bootloader mode for firmware updates without moving the `BOOT` jumper. |
| `!MENU!` / `!CONFIG!` | Config Menu | Opens interactive configuration and clock tuning menu. |

---

### Manual Stepping Mode (Single-Stepping & Burst Stepping)

When **Manual Stepping Mode** is enabled via the [Configuration Menu](config-menu.md#9-manual-stepping-mode), the FPGA master clock remains stopped until triggered by the configured keyboard shortcut:

* **Configurable Trigger Key:** Spacebar, Tab, or Enter.
* **Configurable Step Multiplier:** 1, 10, 100, 1,000, 10,000, or 100,000 clock ticks per keypress.
* **Burst Accumulation:** If you hold or spam the key rapidly, keystroke bursts accumulate in an internal queue and drain cleanly without dropping ticks, allowing frame-by-frame observation of Brainfuck execution.

---

## When the FPGA is "Too Fast": The Serial Bottleneck

??? warning "High Clock Speeds & Missed Characters"
    The Lattice MachXO2 FPGA soft-processor processes bytes with extreme speed. However, serial transmission over USB is fundamentally serialized. 
    
    When executing **write-intensive programs**—programs that spam the `.` output command in tight loops (such as Mandelbrot fractals, large ASCII art dumps, or matrix calculations)—the FPGA can produce parallel bytes on its output bus faster than the STM32 can packetize and transmit them over USB CDC.
    
    * **Zero Dropped Characters:** The firmware includes **Smart Hardware Clock-Pausing** ([read architecture details](../firmware/architecture.md#smart-hardware-clock-pausing-output-throttling)). The STM32 automatically freezes the FPGA master clock in 1 CPU instruction upon output strobe assertion, samples data with zero race conditions, and applies hardware backpressure if the USB buffer nears capacity.
    * **Operating Speeds:** Supported across all 13 clock frequencies from 62.5 kHz up to 12 MHz with 100% character fidelity.

---

## Interactive Program Input (`,` Command)

Brainfuck is not just a language for printing static text—it can take live input from your keyboard using the `,` command!

When your Brainfuck program reaches a `,` instruction:

1. The FPGA pauses and asserts a read request (`portRD`).
2. The STM32 places the ASCII key you type into the FPGA's 8-bit input port (`inPort[7:0]`) and asserts the `BF_INCMG` flag.
3. The FPGA accepts the byte and saves it directly into the memory tape cell pointed to by `p`.

### What Can You Build with Interactive Input?
* **Game of Life:** Use the keyboard to place cells, advance generations, or change rules.
* **Interactive Text Adventures:** Type direction commands (`n`, `s`, `e`, `w`) to navigate rooms and solve puzzles.
* **Terminal Mirror / Filter:** Build a program that transforms your typed input (e.g. converting lowercase to uppercase) and echoes it back in real time.

---

## Uploading New Code (Dedicated Program Mode)

To upload new Brainfuck code into Flash ROM:

1. **Enter Program Mode:**
   * Press and hold the hardware button for **3 seconds**.
   * The **Red LED** turns on at the 3-second mark to confirm you can release the button.
   * The FPGA is held in reset (`BF_RST = 0`) to release the ROM bus, and the terminal displays:
     ```text
     === BRAINFUINO PROGRAM MODE ===
     Paste Brainfuck code now (up to 256 kB)...
     ```
2. **Paste Your Code:**
   * Simply paste your Brainfuck code into the terminal emulator.
   * **Programs ≤ 4 kB:** The STM32 buffers the code in SRAM. When reception pauses for **100 ms**, it prints the total size, erases ROM, fast-writes to Flash while reporting live percentage progress (`Writing: 50% (2048 / 4096 bytes)...`), verifies against RAM, appends `[-]+[]`, and auto-launches.
   * **Programs > 4 kB (up to 256 kB):** If the 4 kB buffer fills, the firmware automatically announces:
     ```text
     Program larger than RAM buffer. Streaming directly to Flash...
     ```
     It erases ROM, writes the first 4 kB, and streams subsequent incoming packets straight into Flash using USB CDC hardware NAK flow control, displaying cumulative bytes written (`Wrote 5120 bytes...`, `Wrote 6144 bytes...`).
3. **Run Your Code:**
   * Flashing automatically appends an endless loop (`[-]+[]`) to halt the FPGA program counter cleanly at EOF, and auto-launches the new code immediately!
   * You can also give the button a **short press (< 3 seconds)** at any time to soft-reset the program.

---

## Hardware Button Behavior

The Brainfuino button utilizes a 35 ms hardware debounce filter to eliminate tactile contact chatter. The coprocessor measures the steady hold duration to provide intuitive 4-tier control:

| Action | Duration | Red LED Feedback | Result |
| :--- | :---: | :---: | :--- |
| **Short Press** (Run Mode) | < 3 seconds | **70 ms Blip** | Resets the running FPGA soft-processor (`BF_RST` pulse) and prints `[bf_µP reset] <speed>` (e.g. `[bf_µP reset] 500 kHz`). |
| **Short Press** (Config Mode) | < 3 seconds | Turns OFF | Exits configuration menu, saves settings, and resumes execution. |
| **Short Press** (Program Mode) | < 3 seconds | Turns OFF | Exits Program Mode and executes the program currently in ROM. |
| **Program Mode Hold** | 3 – 6 seconds | **Solid ON** | Enters **Dedicated Program Mode** (ready for Brainfuck code paste). |
| **Config Menu Hold** | 6 – 10 seconds | **Smooth Breathing / Pulse** | Enters **[Configuration Menu](config-menu.md)** (`STATE_CONFIG`) for tuning clock, hotkeys, and features. |
| **Factory Demo Restore** | ≥ 10 seconds | **Rapid Strobe** (50 ms) | Erases parallel ROM, restores official Brainfuino ASCII logo demo, and auto-launches it! |

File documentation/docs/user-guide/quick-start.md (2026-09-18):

# Quick Start Guide

Getting started with Brainfuino is remarkably simple. Because the board uses standard USB CDC (Virtual COM Port) emulation, no proprietary drivers or software suites are needed—just a serial terminal like PuTTY, Tera Term, minicom, or screen.

---

## 1. Connect Hardware

1. Plug a **USB-C data cable** into your computer and the Brainfuino.
2. The onboard power LEDs will illuminate, and your computer will detect an **STM32 Virtual COM Port** (e.g., `COM3` on Windows, `/dev/ttyACM0` on Linux, `/dev/cu.usbmodem...` on macOS).

---

## 2. Open a Serial Terminal

Open your serial terminal emulator of choice:

* **Windows:** [PuTTY](https://putty.org/) or [Tera Term](https://ttssh2.osdn.jp/)
* **Linux:** `screen /dev/ttyACM0 115200` or `minicom -D /dev/ttyACM0`
* **macOS:** `screen /dev/cu.usbmodem* 115200`

### Recommended Settings

| Setting | Value |
| :--- | :--- |
| **Port** | Assigned Virtual COM Port |
| **Baud Rate** | Any (Hardware USB CDC ignores baud settings) |
| **Data Bits** | 8 |
| **Parity** | None |
| **Stop Bits** | 1 |
| **Flow Control** | None |

??? tip "Preventing 'Stair-Stepping' in Serial Terminals"
    If incoming text steps diagonally across your terminal screen without returning to the left margin on newlines:
    * **In Tera Term:** Go to **Setup → Terminal → New-Line → Receive** and select **AUTO**.
    * **In PuTTY:** Under **Terminal**, check **Implicit CR in every LF**.
    
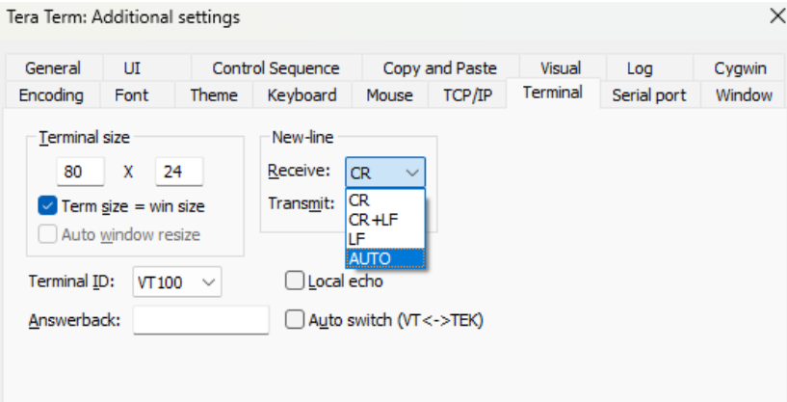
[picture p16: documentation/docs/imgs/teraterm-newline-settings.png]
Tera Term New-Line Receive Auto Setting
    

---

## 3. Run the Installed Program

1. Ensure the **BOOT jumper** is moved back to normal run mode so the STM32 can boot.
2. Press the **Reset Button** on the Brainfuino board.
3. The FPGA soft-processor resets its Program Counter (`pc = 0`), resets its Data Pointer (`p = 0`), and begins executing the program stored in parallel Flash ROM.
4. The board immediately executes the program and streams output directly to your serial console!

---

## 4. Uploading a New Brainfuck Program

The companion STM32 coprocessor monitors incoming serial packets: any pasted text will automatically be written to the parallel Flash memory.

1. Open any Brainfuck source file in your text editor and copy the code to your clipboard.
2. **Right-click** in your terminal emulator (e.g. Tera Term or PuTTY) to paste the code in.
3. When the incoming packet length is **3 or more bytes**, the STM32 automatically:
    * Pulls the FPGA reset line low (`BF_RST = 0`), pausing the soft-processor.
    * Turns on the status LED.
    * Erases the parallel Flash ROM sectors.
    * Writes the new code byte-by-byte into the parallel ROM.
    * Responds in the terminal: `Wrote <N> bytes`.

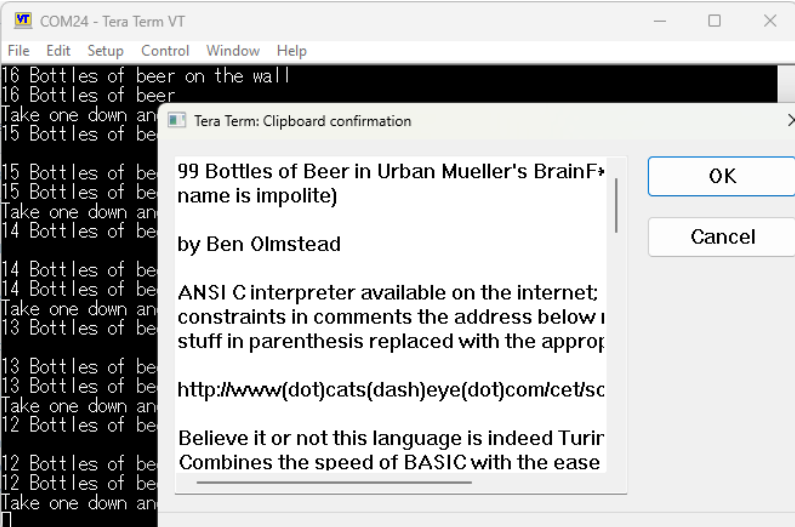
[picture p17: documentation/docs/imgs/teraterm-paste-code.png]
Pasting Brainfuck code into Tera Term
    

4. Press the hardware **Reset Button** on the Brainfuino to boot the FPGA into your new program!

```brainfuck title="Simple Hello World Example"
+[-->-[>>+>-----<<]<--<---]>-.>>>+.>>..+++[.>]<<<<.+++------.<<<.>>>>+.
```

---

## 5. Helpful Tips & Program Halting

??? tip "Automatic Program Halting (Append Endless Loop)"
    **Automatic Halting Enabled by Default:**
    
    The FPGA soft-processor fetches and executes instructions from ROM continuously. Without a halt loop, once execution reaches the end of your program, it would march through unprogrammed ROM (`0xFF`) until address 262,143, wrap back around to address 0, and restart the program.
    
    Brainfuino solves this automatically! The companion firmware includes an **Append Endless Loop** configuration option (enabled by default as `[-]+[]` in the [Configuration Menu](config-menu.md)). Whenever you upload code or load from the Program Library, the STM32 automatically appends the robust halt idiom to the end of your code before flashing.
    
    **Recommendation:** Keep **Append Endless Loop** enabled (`[-]+[]`). You do not need to add manual halt loops to your Brainfuck programs—any standard Brainfuck code will halt cleanly at EOF!
    
    **Behind the Scenes: The Robust `[-]+[]` Idiom:**
    Many online tutorials suggest ending programs with `+[]`. However, if your program finishes with the current tape cell containing **255**, adding 1 wraps to **0** (`255 + 1 = 0`). The loop `[]` checks if the cell is non-zero, sees `0`, skips right past the loop, and restarts anyway! Brainfuino's auto-injected `[-]+[]` idiom zeroes the cell first, adds 1, and enters an unbreakable infinite halt loop.

??? note "Single-Key Commands"
    When you press a single key (packet length under 3 bytes), the STM32 interprets hotkeys:
    
    * **Keys `1` through `7`:** Change FPGA clock frequency (500 kHz to 48 MHz).
    * **Key `!`:** Dump the entire program currently stored in ROM.
    * **Key `@`:** Retransmit buffered serial data from the FPGA output buffer.
    
    See the [Terminal Commands Reference](terminal-commands.md) for full details.

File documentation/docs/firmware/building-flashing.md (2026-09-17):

# Building & Flashing STM32 Firmware

The companion MCU firmware is organized as an **STM32CubeIDE** project located under [`companion-STM32-firmware/`](https://github.com/m-archibald/Brainfuino/tree/main/companion-STM32-firmware).

A pre-built production binary is always kept ready at:
[`companion-STM32-firmware/Debug/BrainfuinoMCU.hex`](https://github.com/m-archibald/Brainfuino/blob/main/companion-STM32-firmware/Debug/BrainfuinoMCU.hex).

---

## Toolchain Setup

To modify or rebuild the firmware:

1. Download and install [STM32CubeIDE](https://www.st.com/en/development-tools/stm32cubeide.html) (free from STMicroelectronics, cross-platform for Windows, Linux, and macOS).
2. Launch STM32CubeIDE and select your workspace directory.
3. Go to **File → Import → General → Existing Projects into Workspace**.
4. Browse to the root of `companion-STM32-firmware/` and click **Finish**.

---

## Rebuilding the Project

1. In the Project Explorer, right-click `BrainfuinoMCU`.
2. Select **Build Project** (or press ++ctrl+b++ / ++cmd+b++).
3. The GCC ARM toolchain compiles the STM32 HAL drivers, USB Device library, and `main.c`.
4. The output `.elf`, `.bin`, and `.hex` files are generated in the `Debug/` folder.

---

## Automated Command-Line Build & Flash Script

For the fastest development workflow, a cross-platform PowerShell automation script is provided at [`companion-STM32-firmware/build.ps1`](https://github.com/m-archibald/Brainfuino/blob/main/companion-STM32-firmware/build.ps1):

* **Compile Only:**
  ```powershell
  pwsh companion-STM32-firmware/build.ps1 -CompileOnly
  ```
  Locates the embedded GCC ARM toolchain automatically, compiles startup assembly and C sources, links the ELF binary, and generates `Debug/BrainfuinoMCU.hex`.

* **One-Click Build & Flash (over USB DFU):**
  ```powershell
  pwsh companion-STM32-firmware/build.ps1 -Flash
  ```
  Automatically compiles, auto-detects the Brainfuino virtual COM port, sends the `!DFU!` trigger command to reboot the STM32 into its factory USB DFU bootloader, connects via `STM32_Programmer_CLI`, flashes the binary, and immediately resumes program execution. **No jumper movement needed!**

---

## Automated Hardware Verification Test Suite

Hardware functionality and menu workflows can be verified end-to-end against a live Brainfuino board connected over USB:

* **Menu, Program Library, and TOC Test:**
  ```powershell
  python scripts/test_library_and_menu.py
  ```
  Runs an automated 10-stage test validating menu rendering, Left/Right arrow cycling, program addition and comment pruning, pre-run verification skipping (`n`), live FPGA execution, and zero-erase tombstone deletion.

* **Clock Speed & Printing Strobe Test:**
  ```powershell
  python scripts/test_logo_all_speeds.py
  ```
  Cycles through all 25 FPGA clock frequencies (from 10 Hz PWM up to 12 MHz MCO) and verifies zero dropped characters during high-speed execution.

---

## Flashing the Microcontroller

There are three methods to flash the firmware onto the STM32F072:

### Method 1: Automated Software USB DFU (Recommended)

Thanks to an SRAM persistence flag (`0xDEADBEEF` at `0x20003FF0`), the STM32 companion coprocessor can soft-reboot directly into ST's built-in factory ROM DFU bootloader without touching hardware jumpers:

1. Connect Brainfuino to your PC via USB-C.
2. Run `pwsh companion-STM32-firmware/build.ps1 -Flash`.
3. Or manually send `!DFU!` over any serial terminal (at 115200 baud). The board will disconnect its USB CDC port, re-enumerate as an ST DFU Device (`0483:df11`), and await firmware download via STM32CubeProgrammer.

---

### Method 2: Manual Hardware Boot Jumper DFU

If you ever flash a corrupt binary that hangs before USB initialization, you can always enter the factory DFU bootloader using the physical hardware header:

1. **Set DFU Mode:**
    * Place the jumper into the **BOOT** position (pulls `BOOT0` HIGH to 3.3V).
    
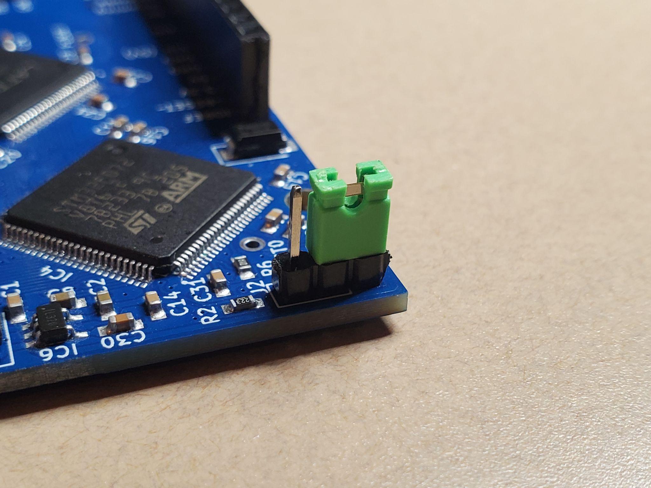
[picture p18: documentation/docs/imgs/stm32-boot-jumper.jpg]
Setting the BOOT jumper on the Brainfuino header
    

2. **Connect Hardware:**
    * Connect the Brainfuino to your computer using a **USB-C data cable**.

3. **Connect in STM32CubeProgrammer:**
    * Launch **STM32CubeProgrammer**.
    * In the top-right connection panel, select **USB** from the drop-down menu, verify that **Port USB1** appears (click the refresh icon if needed), and click **Connect**.
    
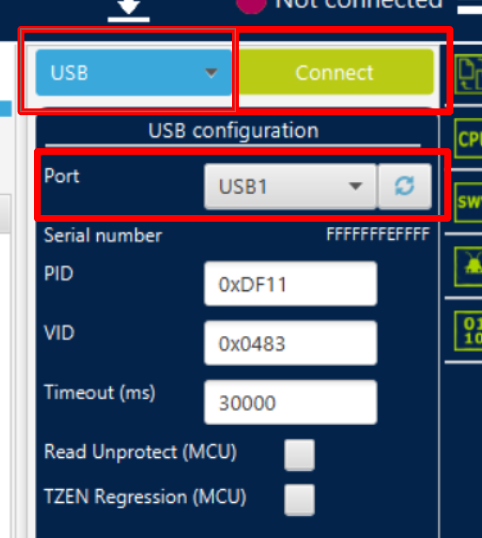
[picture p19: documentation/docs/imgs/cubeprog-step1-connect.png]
Select USB and click Connect in STM32CubeProgrammer
    

4. **Open the Firmware Binary:**
    * Click the **Open file** tab in the top bar:
    
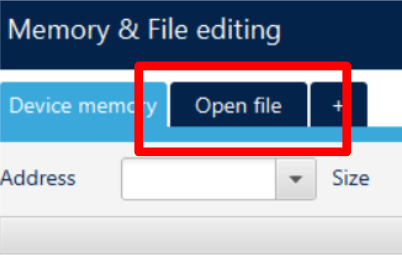
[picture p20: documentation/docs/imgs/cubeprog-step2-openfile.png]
Click Open file in STM32CubeProgrammer
    
    
    * Browse and select `BrainfuinoMCU.hex` (found under `companion-STM32-firmware/Debug/` or downloaded from the GitHub release).
    * The **BrainfuinoMCU.hex** tab will load, showing the firmware mapped to starting flash address `0x08000000`:
    
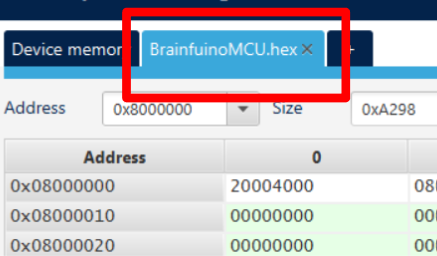
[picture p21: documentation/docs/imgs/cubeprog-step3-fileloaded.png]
BrainfuinoMCU.hex loaded into memory view
    

5. **Download & Flash Firmware:**
    * Click the blue **Download** button:
    
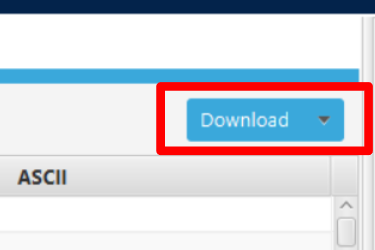
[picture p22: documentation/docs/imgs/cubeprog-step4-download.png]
Click Download to flash STM32
    
    
    * The programmer will erase sectors and write the firmware. Verify the console displays **File download complete**:
    
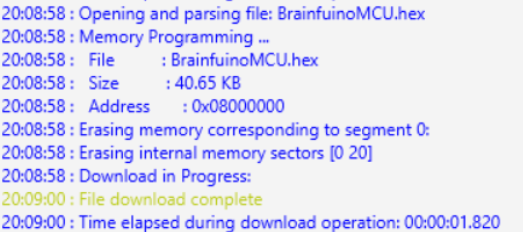
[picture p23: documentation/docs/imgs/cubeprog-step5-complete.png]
File download complete verification in STM32CubeProgrammer log
    

6. **Return to Run Mode:**
    * Unplug the board, move the `BOOT` jumper back so the STM32 can boot normally, and plug the USB-C cable back in.
    * The STM32 coprocessor is now fully programmed and ready to run!

---

### Method 3: Via ST-Link Programmer (Hardware Debugging)

If you are actively developing code and want live breakpoints, variable watches, and hardware stepping:

1. Connect an ST-Link v2 or v3 programmer to the 4-pin SWD header:
    * Pins: `SWDIO`, `SWCLK`, `GND`, `3.3V`
2. In STM32CubeIDE, click **Run → Debug** (or click the Bug icon).
3. The IDE will connect over SWD, flash the firmware into Flash memory, and pause execution at `main()`.

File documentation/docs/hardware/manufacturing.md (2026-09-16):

# Manufacturing & Assembly Guide

Everything needed to manufacture and assemble the **Brainfuino Rev 1.1** board is pre-packaged in the repository under [`brainfuino-PCB/Rev 1.1 - KiCad/jlcpcb/production_files/`](https://github.com/m-archibald/Brainfuino/tree/main/brainfuino-PCB/Rev%201.1%20-%20KiCad/jlcpcb/production_files).

---

## Production Files

The production directory contains three key files tailored for JLCPCB SMT assembly:

| File | Purpose |
| :--- | :--- |
| `GERBER-BrainFuino.zip` | Complete 2-layer Gerber and drill archive (copper, solder mask, silkscreen, edge cuts, NPTH/PTH). |
| `BOM-BrainFuino.csv` | Bill of Materials specifying designators, footprints, and matching **LCSC part numbers**. |
| `CPL-BrainFuino.csv` | Component Placement List (Centroid / Pick-and-Place data: X, Y coordinates, rotation, and layer). |

---

## Ordering via JLCPCB SMT Service

1. Go to [JLCPCB](https://jlcpcb.com/) and click **Order Now**.
2. Upload `GERBER-BrainFuino.zip`.
3. Select standard PCB options:
   - **Layers:** 2
   - **Dimensions:** Detected automatically (~68.6 mm × 53.4 mm Arduino Uno footprint)
   - **PCB Color:** Green, Blue, Black, or Purple (your preference!)
   - **Surface Finish:** HASL (with lead) or LeadFree HASL / ENIG
4. Under **SMT Assembly**, toggle **Enable**:
   - **Assembly Side:** Top Side
   - **Quantity:** Select desired assembled boards
5. Proceed to the SMT file upload step:
   - Upload `BOM-BrainFuino.csv` as the **BOM file**.
   - Upload `CPL-BrainFuino.csv` as the **CPL / Placement file**.
6. Review component placement and confirm any part substitutions if an LCSC part is out of stock.
7. Finalize order!

---

## Post-Assembly Bring-up Checklist

Once your manufactured boards arrive:

1. **Visual Inspection:**
    * Inspect solder joints on the fine-pitch QFP-100 packages (IC1 MachXO2 and IC4 STM32) and TSOP-32 memory chips for any solder bridges or misalignments.

2. **Power Rail Test:**
    * Without programming anything yet, plug in a USB-C cable and verify the voltages with a multimeter:
        * **5.0V** on the VBUS side of Schottky diode `D1/D2`.
        * **3.3V** on the output pin of regulator `IC6` (`SPX3819`).

3. **Flash STM32 Coprocessor:**
    * Connect an ST-Link programmer to the 4-pin STM32 SWD header:
        * Pins: `SWDIO`, `SWCLK`, `GND`, `3.3V`
    * Flash the binary: [`companion-STM32-firmware/Debug/BrainfuinoMCU.hex`](https://github.com/m-archibald/Brainfuino/blob/main/companion-STM32-firmware/Debug/BrainfuinoMCU.hex).

4. **Program FPGA Bitstream:**
    * Connect a programmer to the 6-pin JTAG header:
        * Pins: `TCK`, `TMS`, `TDI`, `TDO`, `GND`, `3.3V`
    * Write `brainfuino_v1.1.jed` (or `brainfuino_v1.0.jed` for Rev 1.0) into the MachXO2 internal flash. Both bitstreams are available in [`brainfuck_uP-FPGA-softprocessor/bitstreams/`](https://github.com/m-archibald/Brainfuino/tree/main/brainfuck_uP-FPGA-softprocessor/bitstreams).

5. **Serial Test:**
    * Unplug the programmers, reconnect via USB-C, and verify that the virtual COM port opens and responds in PuTTY!

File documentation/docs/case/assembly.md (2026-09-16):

# 3D Printable Case & Assembly

To protect your Brainfuino and make it portable on the go, a custom enclosure was designed specifically for the **Rev 1.1** PCB layout. Rather than a fragile snap-fit, the case features an integrated retaining hook on one side and secures firmly with a single screw fastener on the opposite side.

The CAD design files reside under [`3D-printable-case/`](https://github.com/m-archibald/Brainfuino/tree/main/3D-printable-case):

* `BrainFuinoCase.SLDPRT` (Native SolidWorks model)
* `BrainFuinoCase.STEP` (Standard STEP format for FreeCAD, Fusion 360, Onshape, or your slicer)

---

## Required Hardware

You only need two standard metric fasteners:

| Item | Quantity | Notes |
| :--- | :---: | :--- |
| **M3 × 14mm Socket Head Bolt** | 1 | Secures the case halves together. Longer screws (e.g. 16mm or 20mm) work fine too—simply add washers under the head or trim the screw shorter. |
| **M3 Hex Nut** | 1 | Presses into the captured nut pocket in the bottom shell. |

---

## 3D Printing Guidelines

The enclosure is optimized for FDM (Fused Deposition Modeling) 3D printers with standard 0.4 mm nozzles.

| Slicer Setting | Recommended Value | Notes |
| :--- | :--- | :--- |
| **Material** | PLA, PETG, or ABS | PLA gives crisp dimensional accuracy; PETG provides durability. |
| **Layer Height** | 0.20 mm | 0.16 mm or 0.20 mm recommended for smooth overhangs. |
| **Infill** | 15% – 25% | Gyroid or Grid infill pattern. |
| **Walls / Perimeters** | 3 or 4 | Ensures rigid screw holes and corners. |
| **Supports** | None needed | Designed to print cleanly flat-down on the build plate. |
| **Brim** | Optional | Helpful for sharp bed corners if printing with PETG/ABS. |

---

## Assembly Overview

Assembly takes less than a minute with only a single M3 bolt:

1. **Insert M3 Nut:** Press the **M3 nut** into the captive hexagonal pocket in the bottom shell.
2. **Seat the PCB:** Place the Brainfuino PCB into the bottom shell, aligning the USB-C port with its cutout.
3. **Hook the Retention Tab:** Hook the retaining tab on one side of the top lid into the slot on the bottom shell, then swing the lid closed over the board.
4. **Fasten M3 Bolt:** Insert the **M3 × 14mm bolt** into the single mounting hole and tighten until snug.

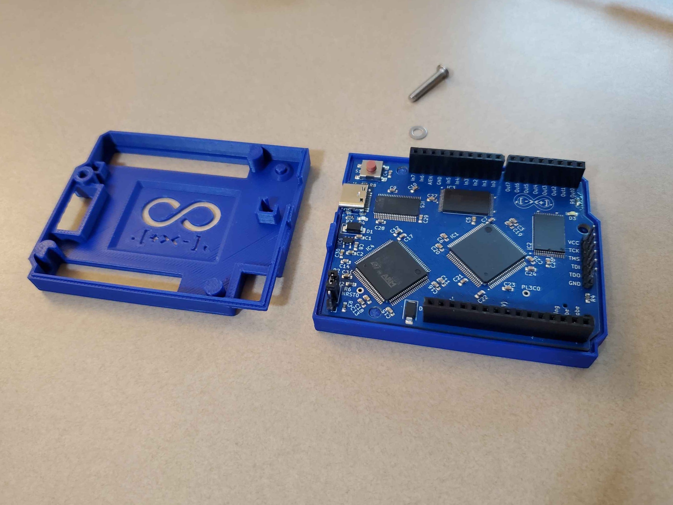
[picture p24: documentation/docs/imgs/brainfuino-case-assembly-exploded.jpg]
Brainfuino Enclosure Assembly Exploded View

*Exploded view showing top lid with retention hook, bottom shell with Brainfuino PCB seated, and single M3 mounting screw with washer.*

---

## Enclosure Details & Cutouts

The enclosure includes dedicated cutouts so all programming headers, debug jumpers, and buses remain accessible without opening the case:

<div class="grid cards" markdown="1">

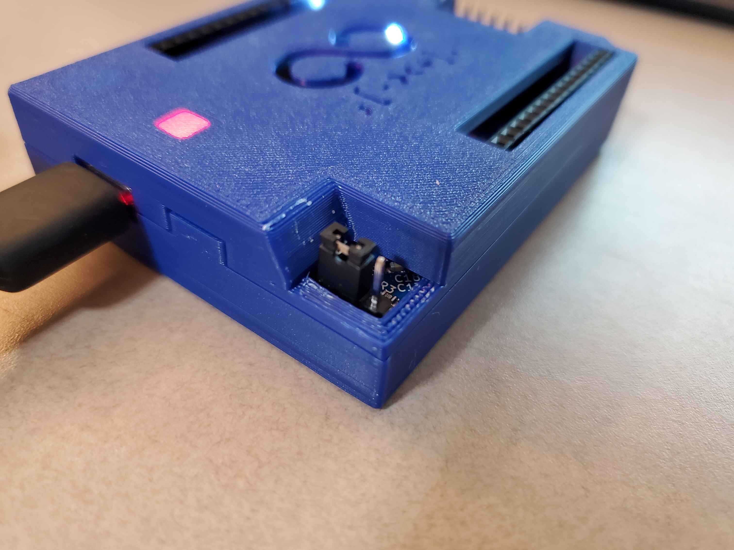
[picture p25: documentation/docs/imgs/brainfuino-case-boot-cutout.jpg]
Corner BOOT0 Jumper Cutout
-   

    ---

    **BOOT0 & Reset Jumper Notch**
    
    A recessed corner notch provides instant access to the STM32 `BOOT0` jumper and `NRST` header for entering DFU bootloader mode.

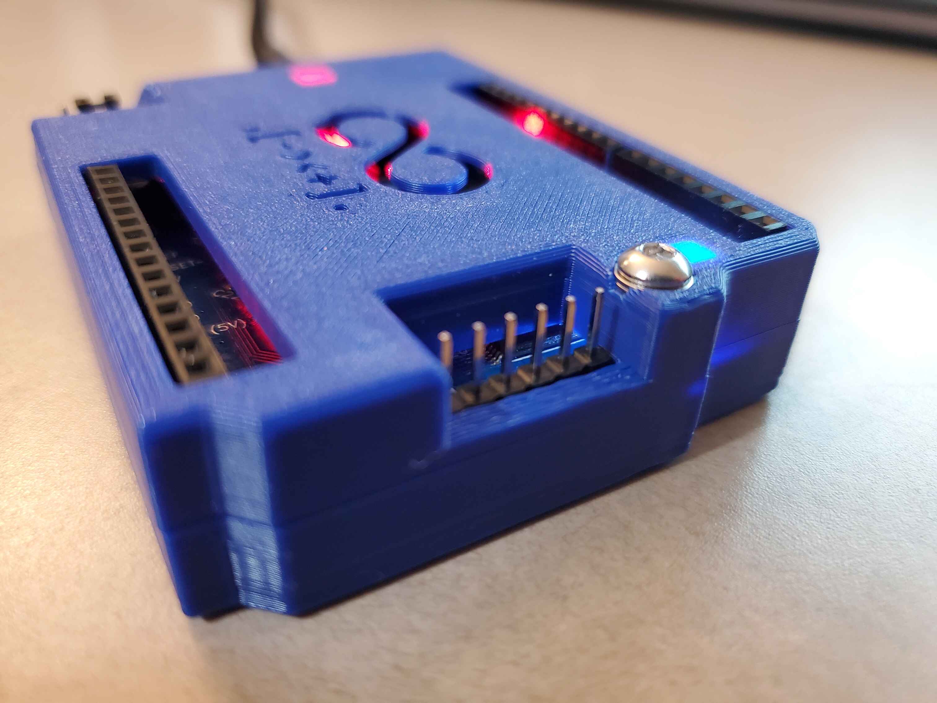
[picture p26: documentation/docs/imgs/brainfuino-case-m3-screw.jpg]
M3 Single Retaining Fastener
-   

    ---

    **Single Fastener Retention**
    
    The top lid hooks securely on one edge and locks down with a single M3 socket bolt and washer on the opposite corner.

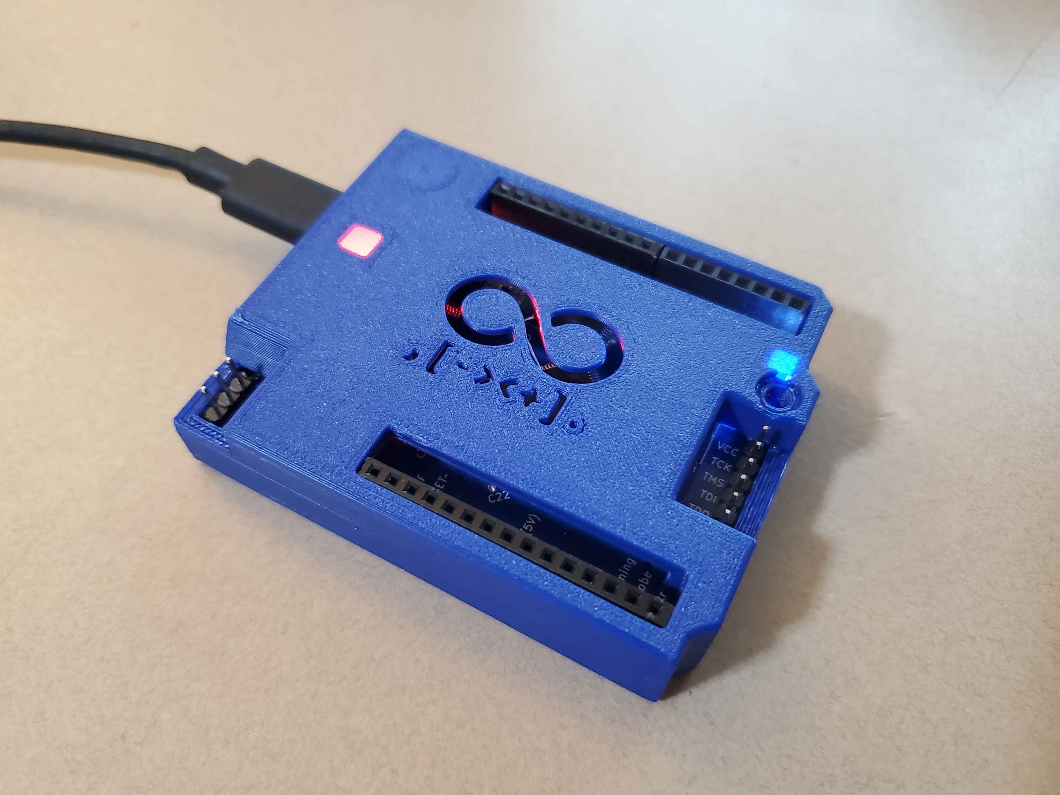
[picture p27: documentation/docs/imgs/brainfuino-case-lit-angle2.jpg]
JTAG Header and Arduino Headers
-   

    ---

    **JTAG & Shield Header Access**
    
    Recessed openings expose the 6-pin FPGA JTAG programming header (`VCC`, `TCK`, `TMS`, `TDI`, `TDO`, `GND`) and standard Arduino Uno pin headers.

-   Fully Assembled Brainfuino Running

    ---

    **Status LED Illumination**
    
    Translucent cutouts illuminate the infinity Brainfuino logo `[ - > < + ] .` and display red power and blue FPGA clock activity LEDs.

</div>

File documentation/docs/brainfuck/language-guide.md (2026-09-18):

# Brainfuck Language & Hardware Semantics

Brainfuck is an esoteric programming language created in 1993 by Urban Müller. Despite having only **eight commands**, the language is fully Turing-complete.

On the Brainfuino, these eight commands are executed directly in silicon by the `brainfuck_uP` soft-processor.

---

## The 8 Native Commands

| Command | Verilog Action | Equivalent in C | Description |
| :---: | :--- | :--- | :--- |
| `>` | `p <= p + 1; pc <= pc + 1;` | `p++;` | Increment the data pointer (points to the next memory cell). |
| `<` | `p <= p - 1; pc <= pc + 1;` | `p--;` | Decrement the data pointer (points to the previous memory cell). |
| `+` | `acc <= pData + 1;` | `(*p)++;` | Increment the byte at the data pointer. |
| `-` | `acc <= pData - 1;` | `(*p)--;` | Decrement the byte at the data pointer. |
| `.` | `outPort <= pData; portWR <= 0;` | `putchar(*p);` | Output the byte at the data pointer as an ASCII character. |
| `,` | `acc <= inPort; portRD <= 0;` | `*p = getchar();` | Accept one byte of input and store its value in the byte at the data pointer. |
| `[` | *Branch forward if `*p == 0`* | `while (*p) {` | If the byte at the data pointer is zero, jump the program counter forward to the command after the matching `]`. |
| `]` | *Branch backward if `*p != 0`* | `}` | If the byte at the data pointer is nonzero, jump the program counter back to the command after the matching `[`. |

---

## Hardware Execution Specifics

Because the Brainfuino runs on real physical chips (parallel SRAM and Flash ROM) rather than an emulator, keep these physical parameters in mind:

### 1. Memory Cell Size & Wraparound
* **Cell Size:** Exactly 8 bits (1 byte, unsigned 0 to 255).
* **Arithmetic Wraparound:**
  - `255 + 1` wraps cleanly to `0`.
  - `0 - 1` wraps cleanly to `255`.
* **Zeroing a Cell:** The standard idiom `[-]` decrements the cell until it reaches `0`. On Brainfuino, this takes N loop iterations, where N is the cell's initial value.

### 2. Memory Tape Bounds
* **Data RAM:** 128 kB total (131,072 cells).
* The 17-bit data pointer `p[16:0]` wraps around: decrementing below address `0` wraps around to address `131,071`.

### 3. Comments and Whitespace
* Any character in your source file that is not one of the eight tokens (`+`, `-`, `<`, `>`, `[`, `]`, `.`, `,`) is treated as a no-op (NOP).
* The FPGA simply increments the program counter (`pc <= pc + 1`) and continues.
* You can write descriptive comments, indentations, and notes directly in your code without a preprocessor!

### 4. Halting & Program Termination
* Standard Brainfuck specifications do not define an explicit "exit" instruction.
* In hardware, the FPGA soft-processor executes bytes from Flash ROM continuously. Without a halt loop, it would step through unprogrammed Flash space until address `262,143`, wrap back to `0`, and re-execute from the beginning.
* **Automatic Halt Loop Append (Recommended):** Brainfuino includes an **Append Endless Loop** configuration option in the STM32 firmware (enabled by default as `[-]+[]`). Whenever you paste or upload a program, the firmware automatically appends the robust halt idiom to the end of your code in ROM. You do not need to add halt loops manually to your Brainfuck source files!
* **Behind the Scenes (`[-]+[]`):** Brainfuino uses the bulletproof `[-]+[]` idiom rather than `+[]`. Zeroing the cell first guarantees that the cell is non-zero after `+` (avoiding the 255 + 1 = 0 wraparound bug in standard `+[]`), parking the FPGA program counter indefinitely at EOF.

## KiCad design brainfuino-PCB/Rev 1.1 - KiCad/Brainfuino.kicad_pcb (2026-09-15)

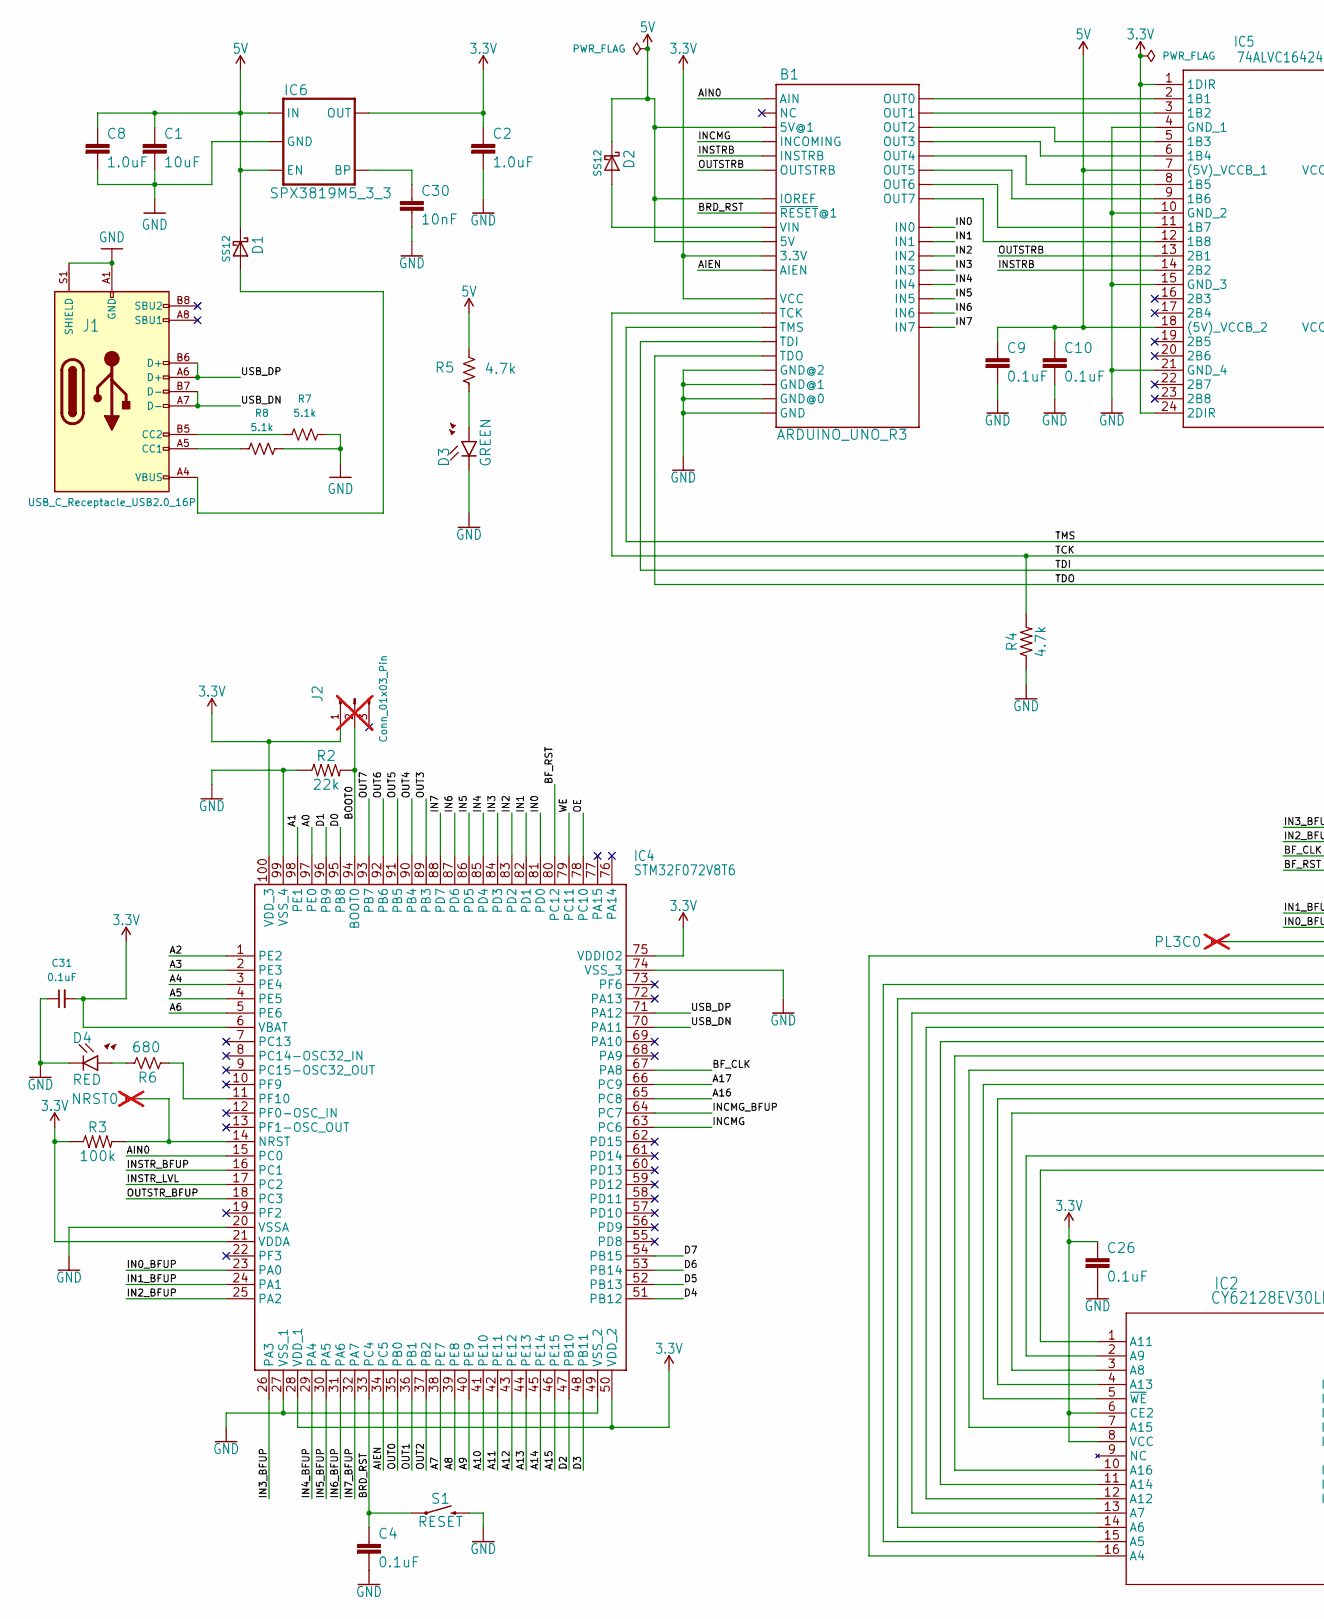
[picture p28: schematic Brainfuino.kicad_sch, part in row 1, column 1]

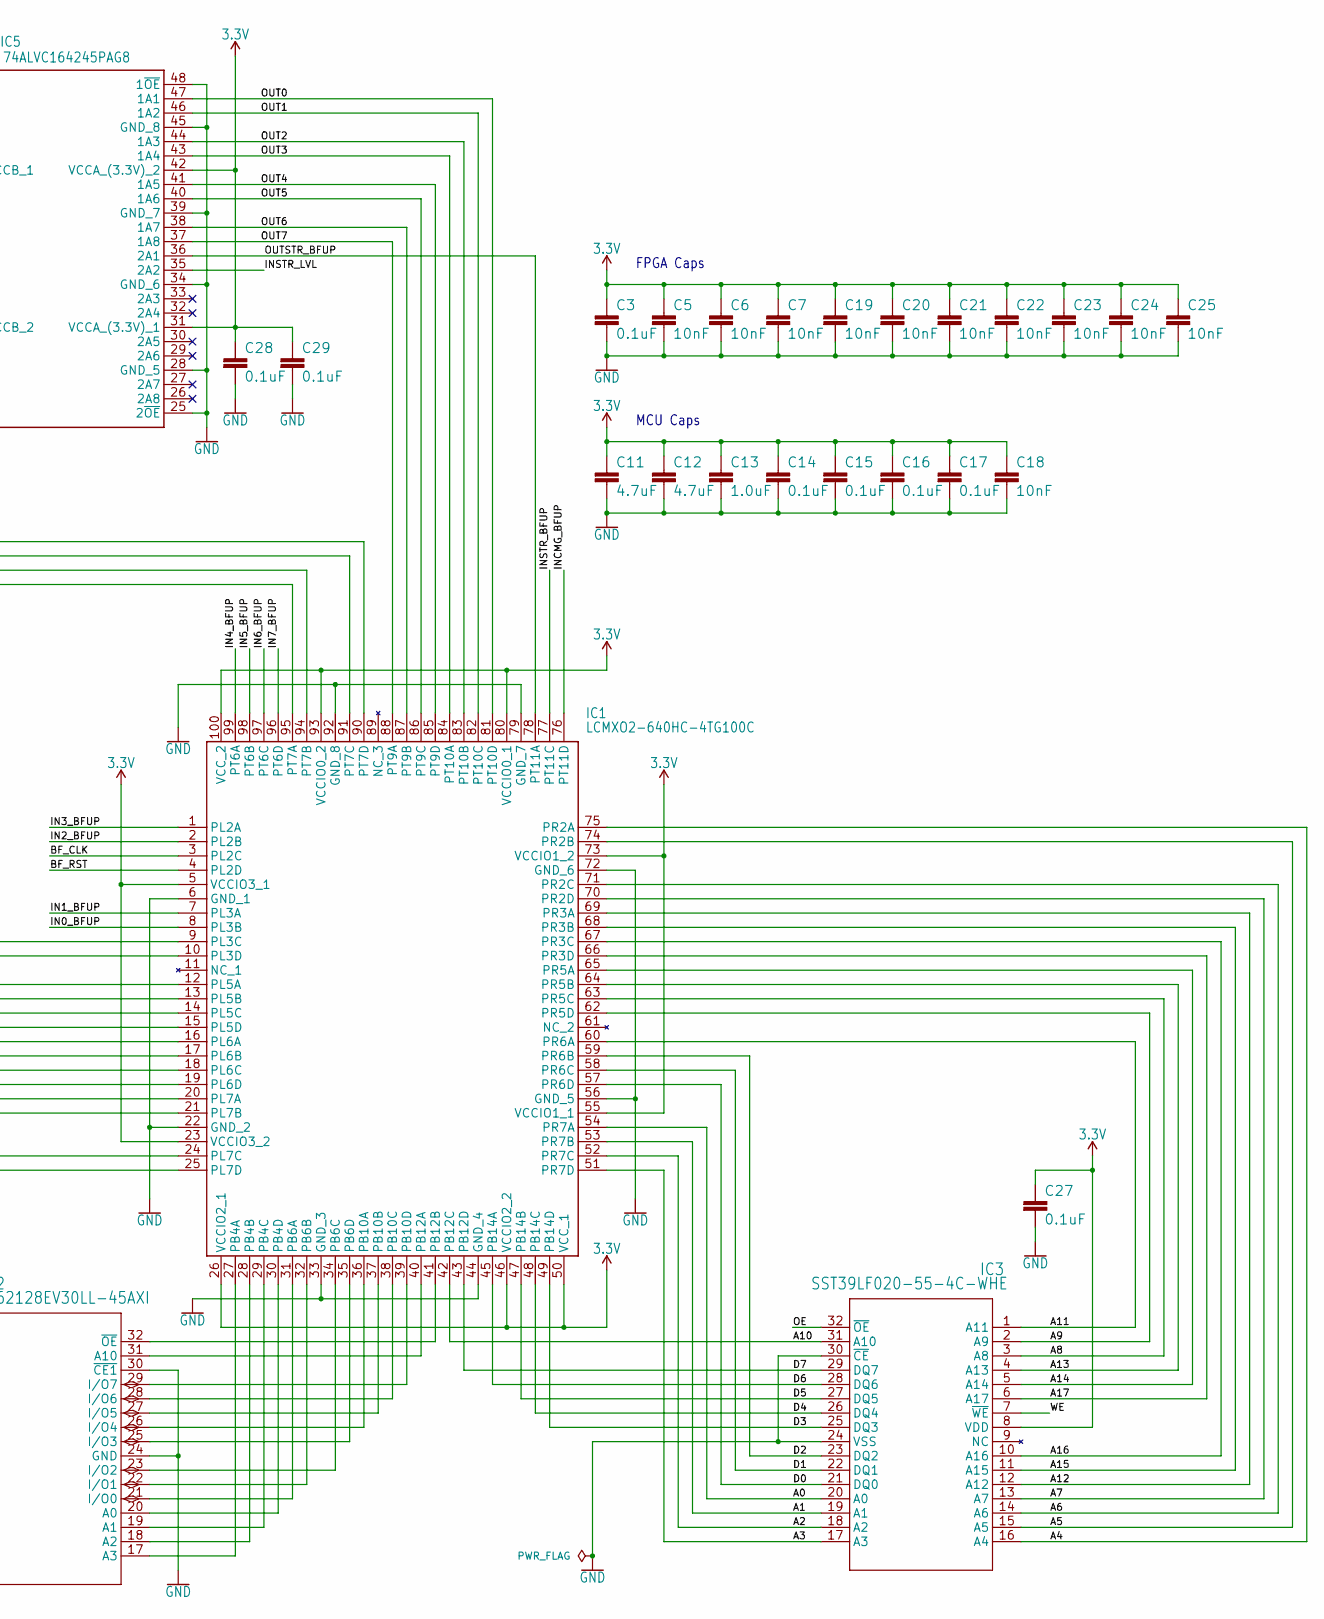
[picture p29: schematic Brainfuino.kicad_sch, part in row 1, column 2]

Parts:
B1: ARDUINO_UNO_R3; ARDUINO_R3
C1: 10uF; 0603; LCSC C19702
C2, C8, C13: 1.0uF; 0603; LCSC C15849
C3, C4, C9, C10, C14, C15, C16, C17, C26, C27, C28, C29, C31: 0.1uF; 0603; LCSC C14663
C5, C6, C7, C18, C19, C20, C21, C22, C23, C24, C25, C30: 10nF; 0603; LCSC C57112
C11, C12: 4.7uF; 0603; LCSC C19666
D1, D2: SS12; D_SMA; LCSC C2480
D3: GREEN; LED-0603; LCSC C2290
D4: RED; LED-0603; LCSC C2286
IC1: LCMXO2-640HC-4TG100C; QFP50P1600X1600X160-100N; LCSC C1519051
IC2: CY62128EV30LL-45AXI; TSOP-32; LCSC C2944685
IC3: SST39LF020-55-4C-WHE; TSOP32_WH_SST; LCSC C630573
IC4: STM32F072V8T6; QFP50P1600X1600X160-100N; LCSC C125825
IC5: 74ALVC164245PAG8; SOP50P810X120-48N; LCSC C2677360
IC6: SPX3819M5_3_3; SOT23-5; LCSC C9055
J1: USB_C_Receptacle_USB2.0_16P; USB_C_Receptacle_HRO_TYPE-C-31-M-12; LCSC C165948
J2: Conn_01x03_Pin; PinHeader_1x03_P2.54mm_Vertical; not fitted
NRST0: TEST-POINTPOGO_PTH; 1X01_NO_SILK; not fitted
PL3C0: TEST-POINTPOGO_PTH; 1X01_NO_SILK; not fitted
R2: 22k; 0603; LCSC C31850
R3: 100k; 0603; LCSC C25803
R4, R5: 4.7k; 0603; LCSC C23162
R6: 680; 0603; LCSC C23212
R7, R8: 5.1k; R_0603_1608Metric; LCSC C23186
S1: RESET; TACTILE_SWITCH_SMD_6.2MM_TALL; LCSC C2909692

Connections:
3.3V: B1.3.3V, B1.VCC, C2.1, C3.1, C5.1, C6.1, C7.1, C11.1, C12.1, C13.1, C14.1, C15.1, C16.1, C17.1, C18.1, C19.1, C20.1, C21.1, C22.1, C23.1, C24.1, C25.1, C26.1, C27.1, C28.1, C29.1, C31.2, IC1.5 (VCCIO3_1), IC1.23 (VCCIO3_2), IC1.26 (VCCIO2_1), IC1.46 (VCCIO2_2), IC1.50 (VCC_1), IC1.55 (VCCIO1_1), IC1.73 (VCCIO1_2), IC1.80 (VCCIO0_1), IC1.93 (VCCIO0_2), IC1.100 (VCC_2), IC2.6 (CE2), IC2.8 (VCC), IC3.8 (VDD), IC4.6 (VBAT), IC4.21 (VDDA), IC4.28 (VDD_1), IC4.50 (VDD_2), IC4.75 (VDDIO2), IC4.100 (VDD_3), IC5.1 (1DIR), IC5.24 (2DIR), IC5.31 (VCCA_(3.3V)_1), IC5.42 (VCCA_(3.3V)_2), IC6.5 (OUT), J2.1, R3.1
5V: B1.5V, B1.5V@1, B1.IOREF, C1.1, C8.1, C9.1, C10.1, D1.1 (K), D2.1 (K), IC5.7 ((5V)_VCCB_1), IC5.18 ((5V)_VCCB_2), IC6.1 (IN), IC6.3 (EN), R5.2
/A0: IC1.54 (PR7A), IC3.20 (A0), IC4.97 (PE0)
/A1: IC1.53 (PR7B), IC3.19 (A1), IC4.98 (PE1)
/A2: IC1.52 (PR7C), IC3.18 (A2), IC4.1 (PE2)
/A3: IC1.51 (PR7D), IC3.17 (A3), IC4.2 (PE3)
/A4: IC1.75 (PR2A), IC3.16 (A4), IC4.3 (PE4)
/A5: IC1.74 (PR2B), IC3.15 (A5), IC4.4 (PE5)
/A6: IC1.71 (PR2C), IC3.14 (A6), IC4.5 (PE6)
/A7: IC1.70 (PR2D), IC3.13 (A7), IC4.38 (PE7)
/A8: IC1.63 (PR5C), IC3.3 (A8), IC4.39 (PE8)
/A9: IC1.62 (PR5D), IC3.2 (A9), IC4.40 (PE9)
/A10: IC1.42 (PB12C), IC3.31 (A10), IC4.41 (PE10)
/A11: IC1.60 (PR6A), IC3.1 (A11), IC4.42 (PE11)
/A12: IC1.69 (PR3A), IC3.12 (A12), IC4.43 (PE12)
/A13: IC1.64 (PR5B), IC3.4 (A13), IC4.44 (PE13)
/A14: IC1.65 (PR5A), IC3.5 (A14), IC4.45 (PE14)
/A15: IC1.68 (PR3B), IC3.11 (A15), IC4.46 (PE15)
/A16: IC1.67 (PR3C), IC3.10 (A16), IC4.65 (PC8)
/A17: IC1.66 (PR3D), IC3.6 (A17), IC4.66 (PC9)
/AIEN: B1.AREF (AIEN), IC4.34 (PC5)
/AIN0: B1.AIN, IC4.15 (PC0)
/BF_CLK: IC1.3 (PL2C), IC4.67 (PA8)
/BF_RST: IC1.4 (PL2D), IC4.80 (PC12)
/BOOT0: IC4.94 (BOOT0), J2.2, R2.2
/BRD_RST: B1.RESET@1 (~RESET@1), C4.1, IC4.33 (PC4), S1.A2 (1)
/D0: IC1.57 (PR6D), IC3.21 (DQ0), IC4.95 (PB8)
/D1: IC1.58 (PR6C), IC3.22 (DQ1), IC4.96 (PB9)
/D2: IC1.59 (PR6B), IC3.23 (DQ2), IC4.47 (PB10)
/D3: IC1.49 (PB14D), IC3.25 (DQ3), IC4.48 (PB11)
/D4: IC1.48 (PB14C), IC3.26 (DQ4), IC4.51 (PB12)
/D5: IC1.47 (PB14B), IC3.27 (DQ5), IC4.52 (PB13)
/D6: IC1.45 (PB14A), IC3.28 (DQ6), IC4.53 (PB14)
/D7: IC1.43 (PB12D), IC3.29 (DQ7), IC4.54 (PB15)
/IN0: B1.IN0, IC4.81 (PD0)
/IN0_BFUP: IC1.8 (PL3B), IC4.23 (PA0)
/IN1: B1.IN1, IC4.82 (PD1)
/IN1_BFUP: IC1.7 (PL3A), IC4.24 (PA1)
/IN2: B1.IN2, IC4.83 (PD2)
/IN2_BFUP: IC1.2 (PL2B), IC4.25 (PA2)
/IN3: B1.IN3, IC4.84 (PD3)
/IN3_BFUP: IC1.1 (PL2A), IC4.26 (PA3)
/IN4: B1.IN4, IC4.85 (PD4)
/IN4_BFUP: IC1.99 (PT6A), IC4.29 (PA4)
/IN5: B1.IN5, IC4.86 (PD5)
/IN5_BFUP: IC1.98 (PT6B), IC4.30 (PA5)
/IN6: B1.IN6, IC4.87 (PD6)
/IN6_BFUP: IC1.97 (PT6C), IC4.31 (PA6)
/IN7: B1.IN7, IC4.88 (PD7)
/IN7_BFUP: IC1.96 (PT6D), IC4.32 (PA7)
/INCMG: B1.INCOMING, IC4.63 (PC6)
/INCMG_BFUP: IC1.76 (PT11D), IC4.64 (PC7)
/INSTRB: B1.INST (INSTRB), IC5.14 (2B2)
/INSTR_BFUP: IC1.77 (PT11C), IC4.16 (PC1)
/INSTR_LVL: IC4.17 (PC2), IC5.35 (2A2)
/OE: IC3.32 (~OE), IC4.78 (PC10)
/OUT0: IC1.81 (PT10D), IC4.35 (PB0), IC5.47 (1A1)
/OUT1: IC1.82 (PT10C), IC4.36 (PB1), IC5.46 (1A2)
/OUT2: IC1.83 (PT10B), IC4.37 (PB2), IC5.44 (1A3)
/OUT3: IC1.84 (PT10A), IC4.89 (PB3), IC5.43 (1A4)
/OUT4: IC1.85 (PT9D), IC4.90 (PB4), IC5.41 (1A5)
/OUT5: IC1.86 (PT9C), IC4.91 (PB5), IC5.40 (1A6)
/OUT6: IC1.87 (PT9B), IC4.92 (PB6), IC5.38 (1A7)
/OUT7: IC1.88 (PT9A), IC4.93 (PB7), IC5.37 (1A8)
/OUTSTRB: B1.OUTST (OUTSTRB), IC5.13 (2B1)
/OUTSTR_BFUP: IC1.78 (PT11A), IC4.18 (PC3), IC5.36 (2A1)
/TCK: B1.TCK, IC1.91 (PT7C), R4.2
/TDI: B1.TDI, IC1.94 (PT7B)
/TDO: B1.TDO, IC1.95 (PT7A)
/TMS: B1.TMS, IC1.90 (PT7D)
/USB_DN: IC4.70 (PA11), J1.A7 (D-), J1.B7 (D-)
/USB_DP: IC4.71 (PA12), J1.A6 (D+), J1.B6 (D+)
/WE: IC3.7 (~WE), IC4.79 (PC11)
GND: B1.GND@1 (GND), B1.GND@2 (GND@0), B1.GND@3 (GND@1), B1.GND@4 (GND@2), C1.2, C2.2, C3.2, C4.2, C5.2, C6.2, C7.2, C8.2, C9.2, C10.2, C11.2, C12.2, C13.2, C14.2, C15.2, C16.2, C17.2, C18.2, C19.2, C20.2, C21.2, C22.2, C23.2, C24.2, C25.2, C26.2, C27.2, C28.2, C29.2, C30.2, C31.1, D3.C, D4.C, IC1.6 (GND_1), IC1.22 (GND_2), IC1.33 (GND_3), IC1.44 (GND_4), IC1.56 (GND_5), IC1.72 (GND_6), IC1.79 (GND_7), IC1.92 (GND_8), IC2.24 (GND), IC2.30 (~CE1), IC3.24 (VSS), IC3.30 (~CE), IC4.20 (VSSA), IC4.27 (VSS_1), IC4.49 (VSS_2), IC4.74 (VSS_3), IC4.99 (VSS_4), IC5.4 (GND_1), IC5.10 (GND_2), IC5.15 (GND_3), IC5.21 (GND_4), IC5.25 (2~OE), IC5.28 (GND_5), IC5.34 (GND_6), IC5.39 (GND_7), IC5.45 (GND_8), IC5.48 (1~OE), IC6.2 (GND), J1.A1 (GND), J1.A12 (GND), J1.B1 (GND), J1.B12 (GND), J1.S1 (SHIELD), R2.1, R4.1, R7.2, R8.2, S1.B2 (2)
unnamed: D1.2 (A), J1.A4 (VBUS), J1.A9 (VBUS), J1.B4 (VBUS), J1.B9 (VBUS)
unnamed: B1.VIN, D2.2 (A)
unnamed: D3.A, R5.1
unnamed: D4.A, R6.1
unnamed: IC1.27 (PB4A), IC2.17 (A3)
unnamed: IC1.28 (PB4B), IC2.18 (A2)
unnamed: IC1.29 (PB4C), IC2.19 (A1)
unnamed: IC1.30 (PB4D), IC2.20 (A0)
unnamed: IC1.31 (PB6A), IC2.21 (I/O0)
unnamed: IC1.32 (PB6B), IC2.22 (I/O1)
unnamed: IC1.34 (PB6C), IC2.23 (I/O2)
unnamed: IC1.35 (PB6D), IC2.25 (I/O3)
unnamed: IC1.36 (PB10A), IC2.26 (I/O4)
unnamed: IC1.37 (PB10B), IC2.27 (I/O5)
unnamed: IC1.38 (PB10C), IC2.28 (I/O6)
unnamed: IC1.39 (PB10D), IC2.29 (I/O7)
unnamed: IC1.40 (PB12A), IC2.31 (A10)
unnamed: IC1.41 (PB12B), IC2.32 (~OE)
unnamed: IC1.9 (PL3C), PL3C0.1
unnamed: IC1.10 (PL3D), IC2.16 (A4)
unnamed: IC1.12 (PL5A), IC2.15 (A5)
unnamed: IC1.13 (PL5B), IC2.14 (A6)
unnamed: IC1.14 (PL5C), IC2.13 (A7)
unnamed: IC1.15 (PL5D), IC2.12 (A12)
unnamed: IC1.16 (PL6A), IC2.11 (A14)
unnamed: IC1.17 (PL6B), IC2.10 (A16)
unnamed: IC1.18 (PL6C), IC2.7 (A15)
unnamed: IC1.19 (PL6D), IC2.5 (~WE)
unnamed: IC1.20 (PL7A), IC2.4 (A13)
unnamed: IC1.21 (PL7B), IC2.3 (A8)
unnamed: IC1.24 (PL7C), IC2.2 (A9)
unnamed: IC1.25 (PL7D), IC2.1 (A11)
unnamed: IC4.14 (NRST), NRST0.1, R3.2
unnamed: IC4.11 (PF10), R6.2
unnamed: B1.OUT0, IC5.2 (1B1)
unnamed: B1.OUT1, IC5.3 (1B2)
unnamed: B1.OUT2, IC5.5 (1B3)
unnamed: B1.OUT3, IC5.6 (1B4)
unnamed: B1.OUT4, IC5.8 (1B5)
unnamed: B1.OUT5, IC5.9 (1B6)
unnamed: B1.OUT6, IC5.11 (1B7)
unnamed: B1.OUT7, IC5.12 (1B8)
unnamed: C30.1, IC6.4 (BP)
unnamed: J1.A5 (CC1), R8.1
unnamed: J1.B5 (CC2), R7.1

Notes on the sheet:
FPGA Caps
MCU Caps

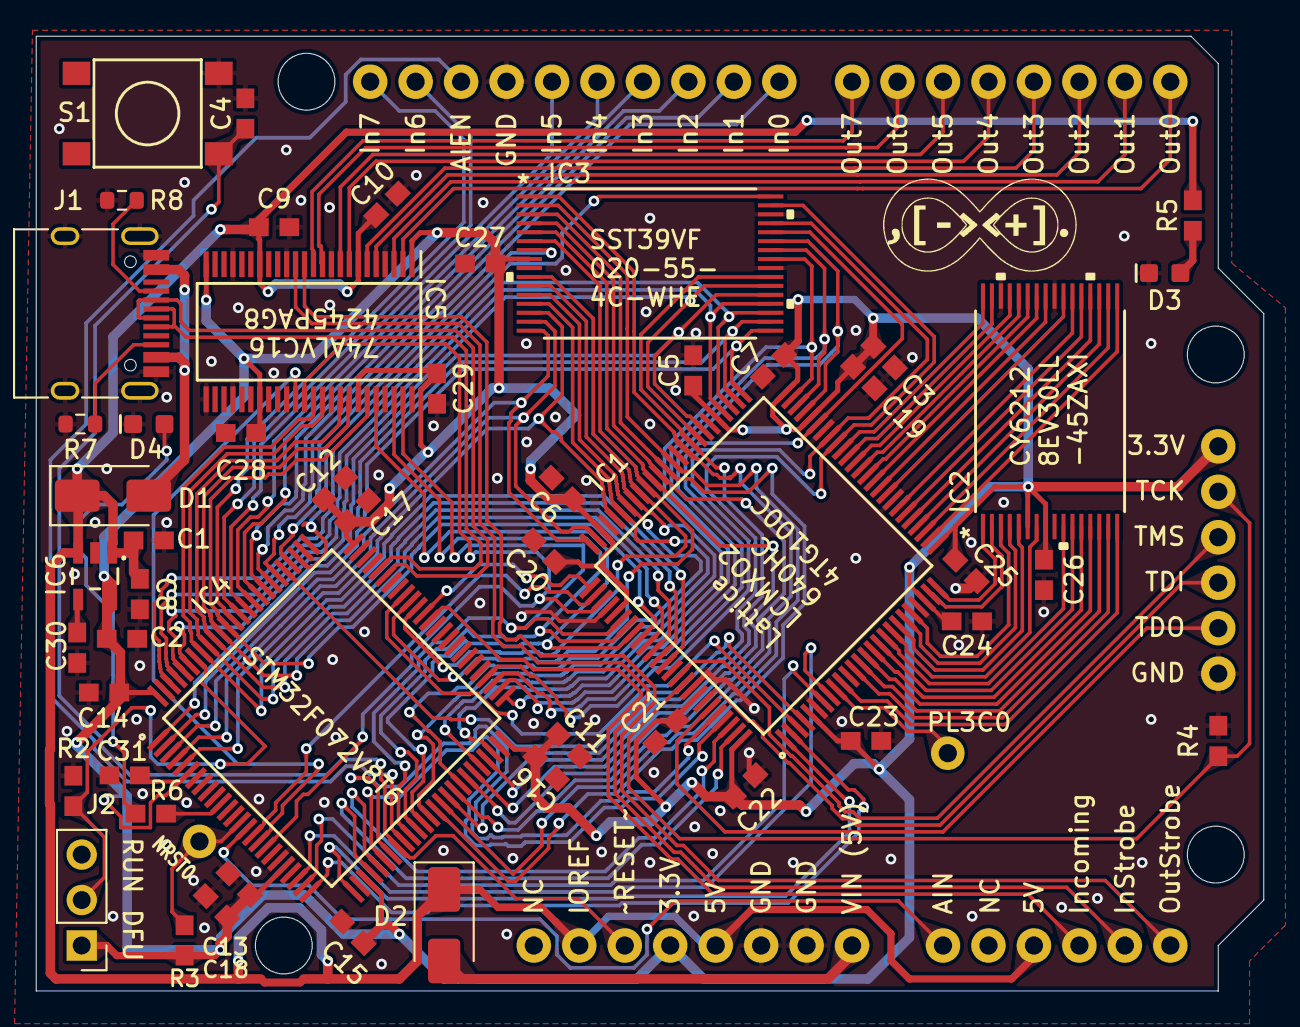
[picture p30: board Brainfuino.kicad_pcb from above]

Board: 2 copper layers, 68.6 x 53.3 mm, 54 parts (0 on the bottom side), 119 nets.

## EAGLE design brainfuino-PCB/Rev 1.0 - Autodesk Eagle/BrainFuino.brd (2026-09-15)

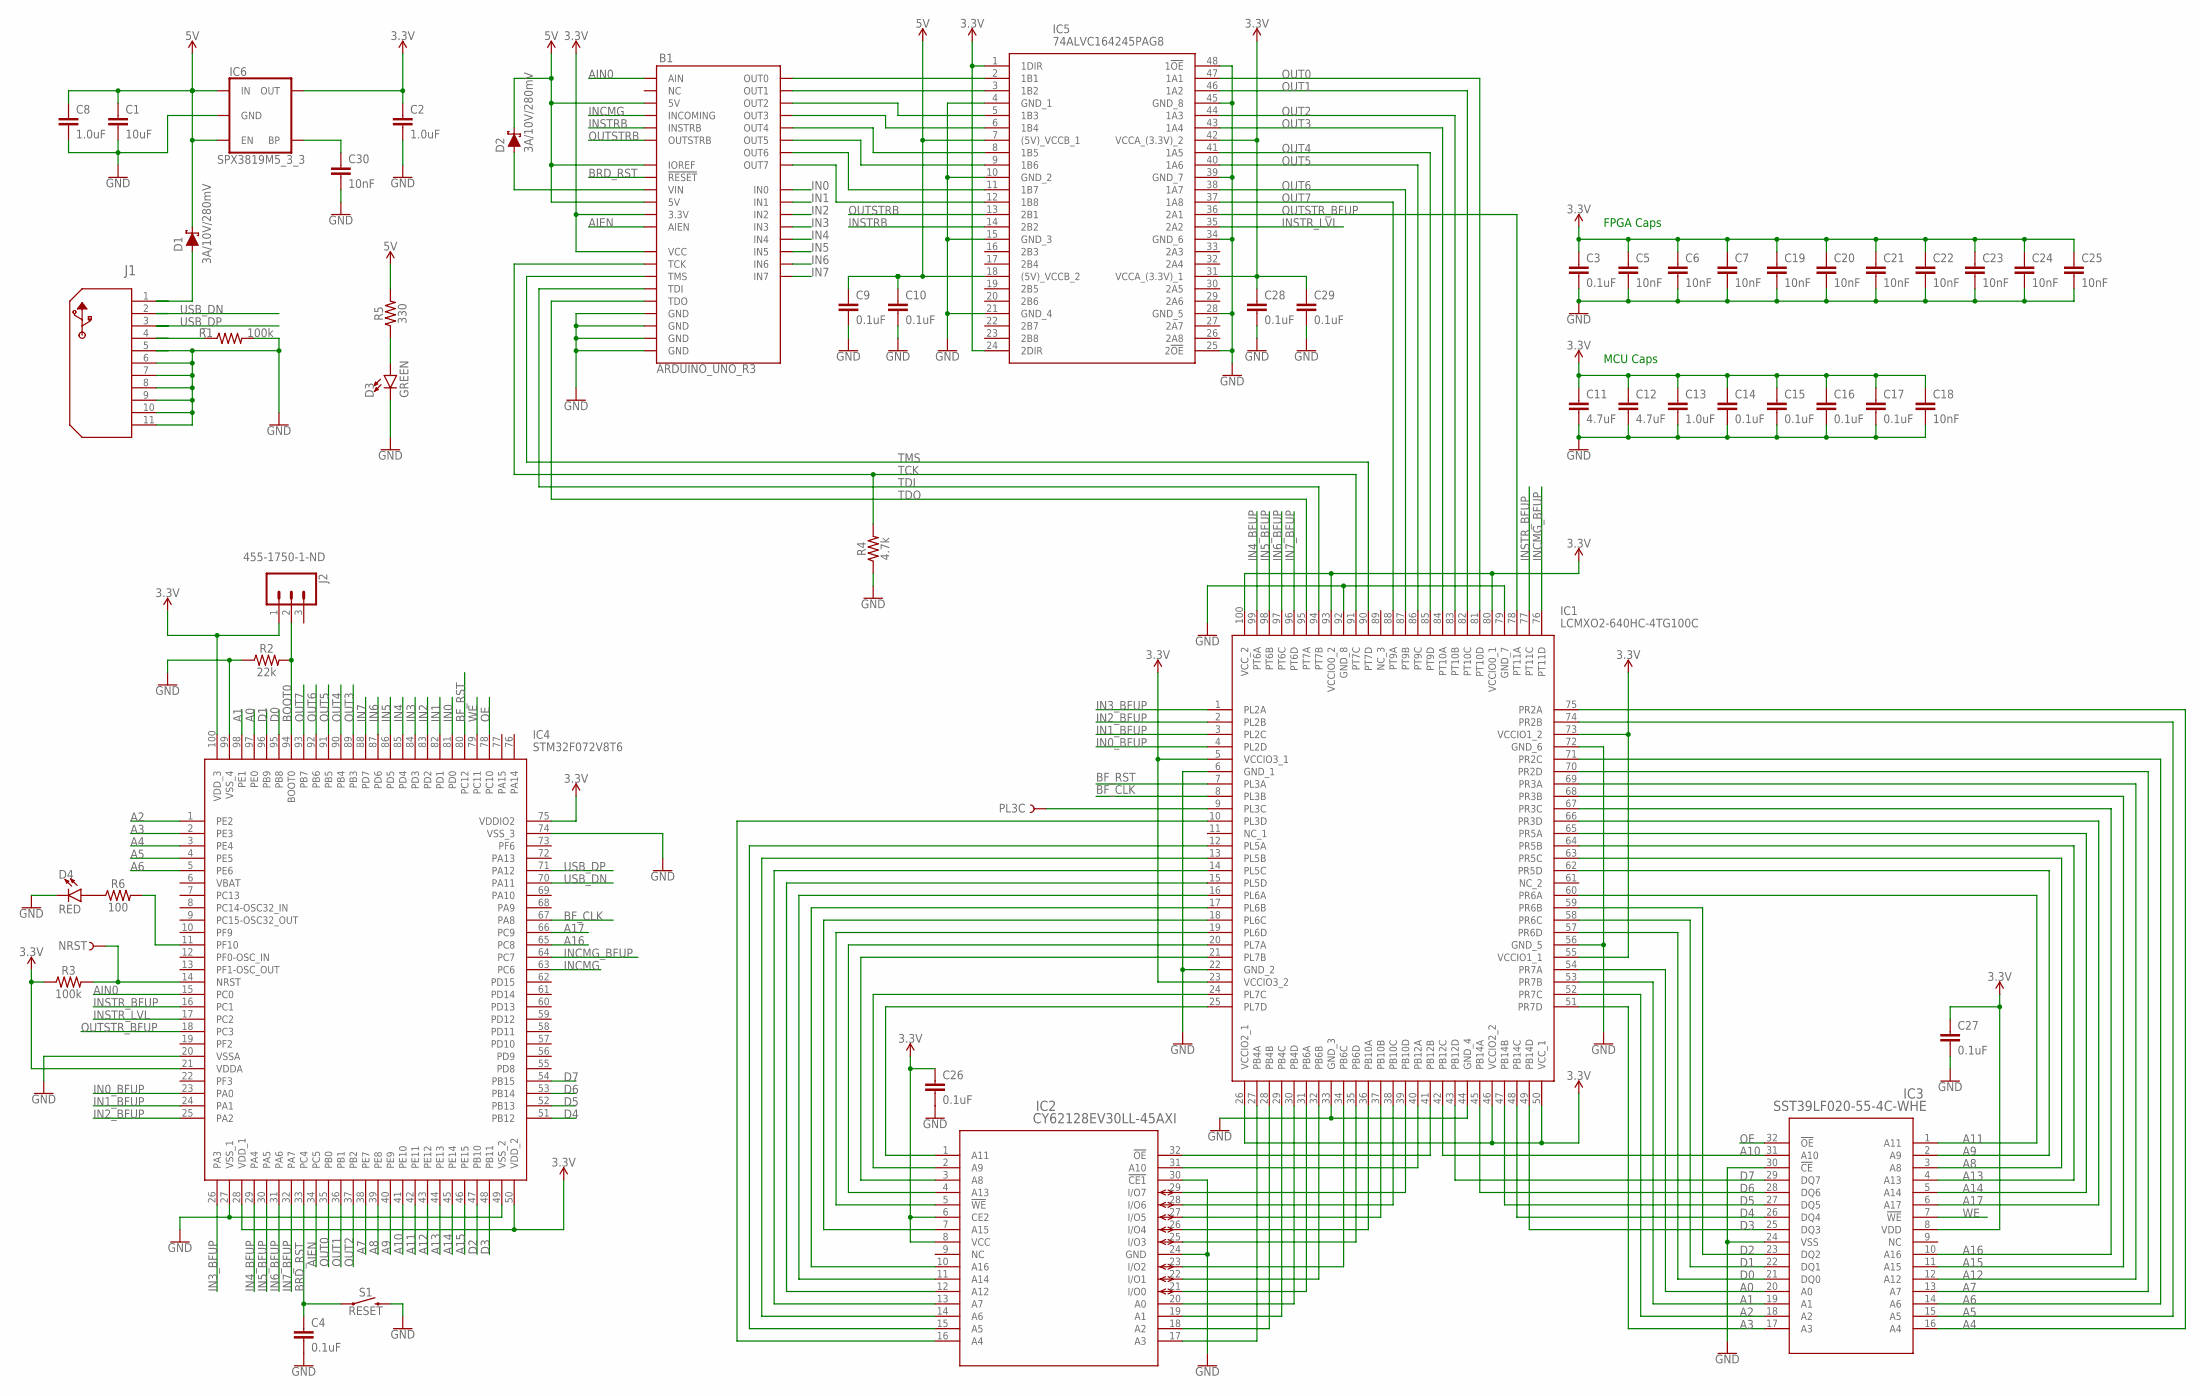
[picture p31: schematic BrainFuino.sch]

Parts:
B1: ARDUINO_UNO_R3; ARDUINO_R3
C1: 10uF; 0603
C2, C8, C13: 1.0uF; 0603
C3, C4, C9, C10, C14, C15, C16, C17, C26, C27, C28, C29: 0.1uF; 0603
C5, C6, C7, C18, C19, C20, C21, C22, C23, C24, C25, C30: 10nF; 0603
C11, C12: 4.7uF; 0603
D1, D2: 3A/10V/280mV; SOD-323
D3: GREEN; LED-0603
D4: RED; LED-0603
IC1: LCMXO2-640HC-4TG100C; QFP50P1600X1600X160-100N
IC2: CY62128EV30LL-45AXI; TSOP-32
IC3: SST39LF020-55-4C-WHE; TSOP32_WH_SST
IC4: STM32F072V8T6; QFP50P1600X1600X160-100N
IC5: 74ALVC164245PAG8; SOP50P810X120-48N
IC6: SPX3819M5_3_3; SOT23-5
J1: 1981568-1; CONN5_1981568-1_TEC
J2: 455-1750-1-ND; 1X03
NRST: TEST-POINTPOGO_PTH; 1X01_NO_SILK
PL3C: TEST-POINTPOGO_PTH; 1X01_NO_SILK
R1, R3: 100k; 0603
R2: 22k; 0603
R4: 4.7k; 0603
R5: 330; 0603
R6: 100; 0603
S1: RESET; TACTILE_SWITCH_SMD_6.2MM_TALL

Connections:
3.3V: B1.3.3V, B1.VCC, C2.1, C3.1, C5.1, C6.1, C7.1, C11.1, C12.1, C13.1, C14.1, C15.1, C16.1, C17.1, C18.1, C19.1, C20.1, C21.1, C22.1, C23.1, C24.1, C25.1, C26.1, C27.1, C28.1, C29.1, IC1.5 (VCCIO3_1), IC1.23 (VCCIO3_2), IC1.26 (VCCIO2_1), IC1.46 (VCCIO2_2), IC1.50 (VCC_1), IC1.55 (VCCIO1_1), IC1.73 (VCCIO1_2), IC1.80 (VCCIO0_1), IC1.93 (VCCIO0_2), IC1.100 (VCC_2), IC2.6 (CE2), IC2.8 (VCC), IC3.8 (VDD), IC4.21 (VDDA), IC4.28 (VDD_1), IC4.50 (VDD_2), IC4.75 (VDDIO2), IC4.100 (VDD_3), IC5.1 (1DIR), IC5.24 (2DIR), IC5.31 (VCCA_(3.3V)_1), IC5.42 (VCCA_(3.3V)_2), IC6.5 (OUT), J2.1, R3.1
5V: B1.5V, B1.5V@1 (5V), B1.IOREF, C1.1, C8.1, C9.1, C10.1, D1.C, D2.C, IC5.7 ((5V)_VCCB_1), IC5.18 ((5V)_VCCB_2), IC6.1 (IN), IC6.3 (EN), R5.2
A0: IC1.54 (PR7A), IC3.20 (A0), IC4.97 (PE0)
A1: IC1.53 (PR7B), IC3.19 (A1), IC4.98 (PE1)
A2: IC1.52 (PR7C), IC3.18 (A2), IC4.1 (PE2)
A3: IC1.51 (PR7D), IC3.17 (A3), IC4.2 (PE3)
A4: IC1.75 (PR2A), IC3.16 (A4), IC4.3 (PE4)
A5: IC1.74 (PR2B), IC3.15 (A5), IC4.4 (PE5)
A6: IC1.71 (PR2C), IC3.14 (A6), IC4.5 (PE6)
A7: IC1.70 (PR2D), IC3.13 (A7), IC4.38 (PE7)
A8: IC1.63 (PR5C), IC3.3 (A8), IC4.39 (PE8)
A9: IC1.62 (PR5D), IC3.2 (A9), IC4.40 (PE9)
A10: IC1.42 (PB12C), IC3.31 (A10), IC4.41 (PE10)
A11: IC1.60 (PR6A), IC3.1 (A11), IC4.42 (PE11)
A12: IC1.69 (PR3A), IC3.12 (A12), IC4.43 (PE12)
A13: IC1.64 (PR5B), IC3.4 (A13), IC4.44 (PE13)
A14: IC1.65 (PR5A), IC3.5 (A14), IC4.45 (PE14)
A15: IC1.68 (PR3B), IC3.11 (A15), IC4.46 (PE15)
A16: IC1.67 (PR3C), IC3.10 (A16), IC4.65 (PC8)
A17: IC1.66 (PR3D), IC3.6 (A17), IC4.66 (PC9)
AIEN: B1.AREF (AIEN), IC4.34 (PC5)
AIN0: B1.AIN, IC4.15 (PC0)
BF_CLK: IC1.8 (PL3B), IC4.67 (PA8)
BF_RST: IC1.7 (PL3A), IC4.80 (PC12)
BOOT0: IC4.94 (BOOT0), J2.2, R2.2
BRD_RST: B1.RESET@1 (!RESET!), C4.1, IC4.33 (PC4), S1.A2 (1)
D0: IC1.57 (PR6D), IC3.21 (DQ0), IC4.95 (PB8)
D1: IC1.58 (PR6C), IC3.22 (DQ1), IC4.96 (PB9)
D2: IC1.59 (PR6B), IC3.23 (DQ2), IC4.47 (PB10)
D3: IC1.49 (PB14D), IC3.25 (DQ3), IC4.48 (PB11)
D4: IC1.48 (PB14C), IC3.26 (DQ4), IC4.51 (PB12)
D5: IC1.47 (PB14B), IC3.27 (DQ5), IC4.52 (PB13)
D6: IC1.45 (PB14A), IC3.28 (DQ6), IC4.53 (PB14)
D7: IC1.43 (PB12D), IC3.29 (DQ7), IC4.54 (PB15)
GND: B1.GND@1 (GND), B1.GND@2 (GND), B1.GND@3 (GND), B1.GND@4 (GND), C1.2, C2.2, C3.2, C4.2, C5.2, C6.2, C7.2, C8.2, C9.2, C10.2, C11.2, C12.2, C13.2, C14.2, C15.2, C16.2, C17.2, C18.2, C19.2, C20.2, C21.2, C22.2, C23.2, C24.2, C25.2, C26.2, C27.2, C28.2, C29.2, C30.2, D3.C, D4.C, IC1.6 (GND_1), IC1.22 (GND_2), IC1.33 (GND_3), IC1.44 (GND_4), IC1.56 (GND_5), IC1.72 (GND_6), IC1.79 (GND_7), IC1.92 (GND_8), IC2.24 (GND), IC2.30 (!CE1), IC3.24 (VSS), IC3.30 (!CE), IC4.20 (VSSA), IC4.27 (VSS_1), IC4.49 (VSS_2), IC4.74 (VSS_3), IC4.99 (VSS_4), IC5.4 (GND_1), IC5.10 (GND_2), IC5.15 (GND_3), IC5.21 (GND_4), IC5.25 (2!OE), IC5.28 (GND_5), IC5.34 (GND_6), IC5.39 (GND_7), IC5.45 (GND_8), IC5.48 (1!OE), IC6.2 (GND), J1.5, J1.6, J1.7, J1.8, J1.9, J1.10, J1.11, R1.2, R2.1, R4.1, S1.B2 (2)
IN0: B1.IN0, IC4.81 (PD0)
IN0_BFUP: IC1.4 (PL2D), IC4.23 (PA0)
IN1: B1.IN1, IC4.82 (PD1)
IN1_BFUP: IC1.3 (PL2C), IC4.24 (PA1)
IN2: B1.IN2, IC4.83 (PD2)
IN2_BFUP: IC1.2 (PL2B), IC4.25 (PA2)
IN3: B1.IN3, IC4.84 (PD3)
IN3_BFUP: IC1.1 (PL2A), IC4.26 (PA3)
IN4: B1.IN4, IC4.85 (PD4)
IN4_BFUP: IC1.99 (PT6A), IC4.29 (PA4)
IN5: B1.IN5, IC4.86 (PD5)
IN5_BFUP: IC1.98 (PT6B), IC4.30 (PA5)
IN6: B1.IN6, IC4.87 (PD6)
IN6_BFUP: IC1.97 (PT6C), IC4.31 (PA6)
IN7: B1.IN7, IC4.88 (PD7)
IN7_BFUP: IC1.96 (PT6D), IC4.32 (PA7)
INCMG: B1.INCOMING, IC4.63 (PC6)
INCMG_BFUP: IC1.76 (PT11D), IC4.64 (PC7)
INSTRB: B1.INST (INSTRB), IC5.14 (2B2)
INSTR_BFUP: IC1.77 (PT11C), IC4.16 (PC1)
INSTR_LVL: IC4.17 (PC2), IC5.35 (2A2)
unnamed: IC1.28 (PB4B), IC2.18 (A2)
unnamed: IC1.29 (PB4C), IC2.19 (A1)
unnamed: IC1.30 (PB4D), IC2.20 (A0)
unnamed: IC1.31 (PB6A), IC2.21 (I/O0)
unnamed: IC1.32 (PB6B), IC2.22 (I/O1)
unnamed: IC1.34 (PB6C), IC2.23 (I/O2)
unnamed: IC1.35 (PB6D), IC2.25 (I/O3)
unnamed: IC1.41 (PB12B), IC2.32 (!OE)
unnamed: IC1.27 (PB4A), IC2.17 (A3)
unnamed: IC1.36 (PB10A), IC2.26 (I/O4)
unnamed: IC1.37 (PB10B), IC2.27 (I/O5)
unnamed: IC1.38 (PB10C), IC2.28 (I/O6)
unnamed: IC1.39 (PB10D), IC2.29 (I/O7)
unnamed: IC1.40 (PB12A), IC2.31 (A10)
unnamed: IC1.9 (PL3C), PL3C.1
unnamed: D3.A, R5.1
unnamed: C30.1, IC6.4 (BP)
unnamed: B1.VIN, D2.A
unnamed: D1.A, J1.1
unnamed: IC4.11 (PF10), R6.2
unnamed: D4.A, R6.1
unnamed: IC4.14 (NRST), NRST.1, R3.2
unnamed: B1.OUT0, IC5.2 (1B1)
unnamed: IC1.25 (PL7D), IC2.1 (A11)
unnamed: IC1.24 (PL7C), IC2.2 (A9)
unnamed: IC1.21 (PL7B), IC2.3 (A8)
unnamed: IC1.18 (PL6C), IC2.7 (A15)
unnamed: IC1.15 (PL5D), IC2.12 (A12)
unnamed: IC1.14 (PL5C), IC2.13 (A7)
unnamed: IC1.13 (PL5B), IC2.14 (A6)
unnamed: IC1.12 (PL5A), IC2.15 (A5)
unnamed: IC1.10 (PL3D), IC2.16 (A4)
unnamed: B1.OUT1, IC5.3 (1B2)
unnamed: B1.OUT2, IC5.5 (1B3)
unnamed: B1.OUT3, IC5.6 (1B4)
unnamed: B1.OUT4, IC5.8 (1B5)
unnamed: B1.OUT5, IC5.9 (1B6)
unnamed: IC1.17 (PL6B), IC2.10 (A16)
unnamed: B1.OUT6, IC5.11 (1B7)
unnamed: B1.OUT7, IC5.12 (1B8)
unnamed: IC1.20 (PL7A), IC2.4 (A13)
unnamed: IC1.19 (PL6D), IC2.5 (!WE)
unnamed: IC1.16 (PL6A), IC2.11 (A14)
unnamed: J1.4, R1.1
OE: IC3.32 (!OE), IC4.78 (PC10)
OUT0: IC1.81 (PT10D), IC4.35 (PB0), IC5.47 (1A1)
OUT1: IC1.82 (PT10C), IC4.36 (PB1), IC5.46 (1A2)
OUT2: IC1.83 (PT10B), IC4.37 (PB2), IC5.44 (1A3)
OUT3: IC1.84 (PT10A), IC4.89 (PB3), IC5.43 (1A4)
OUT4: IC1.85 (PT9D), IC4.90 (PB4), IC5.41 (1A5)
OUT5: IC1.86 (PT9C), IC4.91 (PB5), IC5.40 (1A6)
OUT6: IC1.87 (PT9B), IC4.92 (PB6), IC5.38 (1A7)
OUT7: IC1.88 (PT9A), IC4.93 (PB7), IC5.37 (1A8)
OUTSTRB: B1.OUTST (OUTSTRB), IC5.13 (2B1)
OUTSTR_BFUP: IC1.78 (PT11A), IC4.18 (PC3), IC5.36 (2A1)
TCK: B1.TCK, IC1.91 (PT7C), R4.2
TDI: B1.TDI, IC1.94 (PT7B)
TDO: B1.TDO, IC1.95 (PT7A)
TMS: B1.TMS, IC1.90 (PT7D)
USB_DN: IC4.70 (PA11), J1.2
USB_DP: IC4.71 (PA12), J1.3
WE: IC3.7 (!WE), IC4.79 (PC11)

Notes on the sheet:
FPGA Caps
MCU Caps

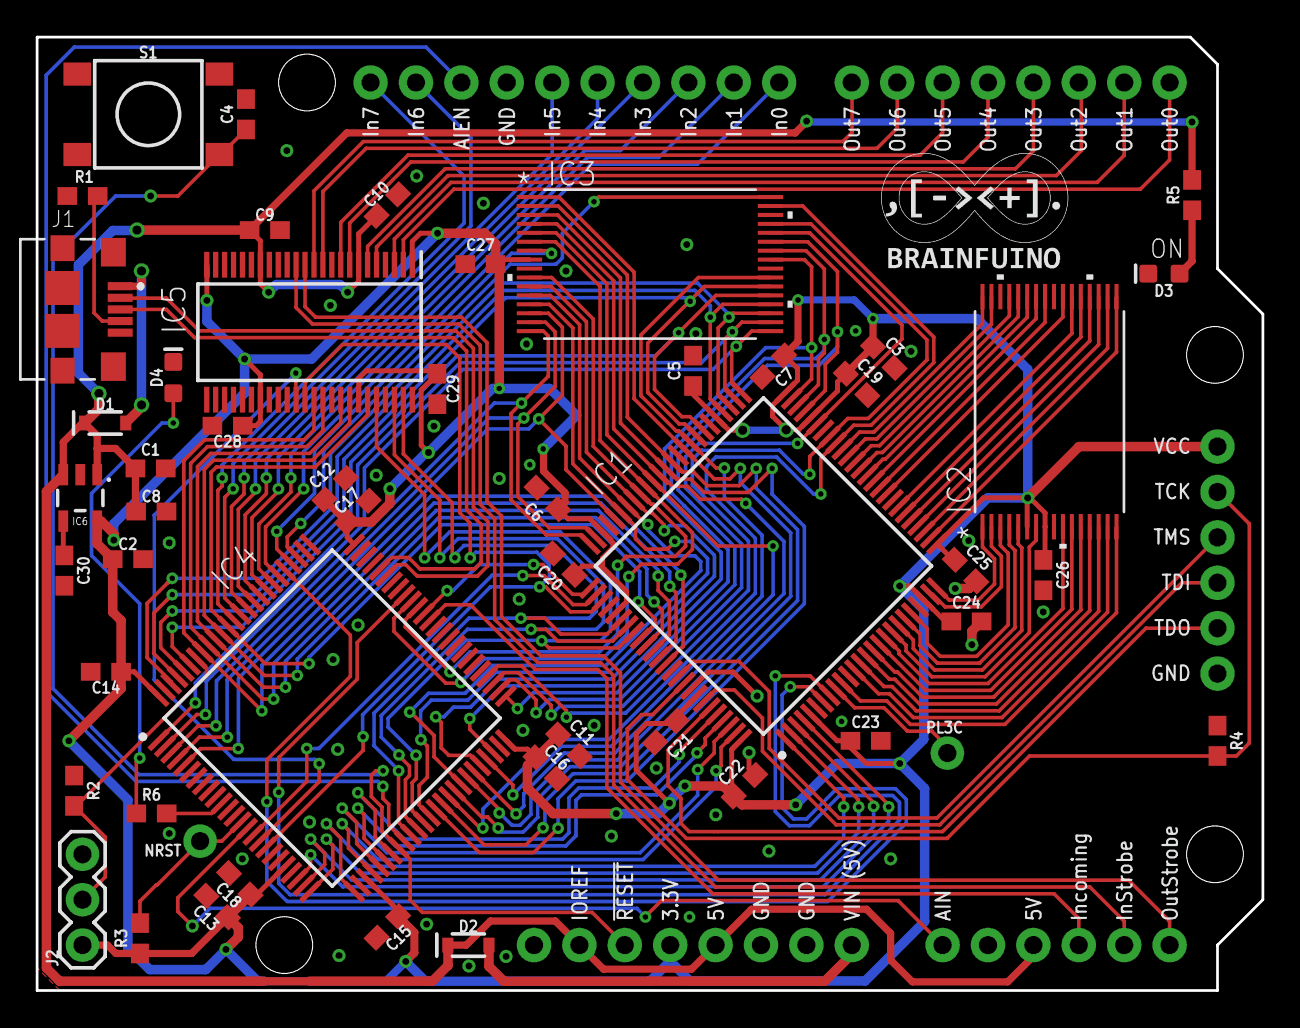
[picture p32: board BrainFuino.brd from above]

Board: 2 copper layers, 68.6 x 53.3 mm, 52 parts (0 on the bottom side), 118 nets.

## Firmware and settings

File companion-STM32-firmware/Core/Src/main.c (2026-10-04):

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
/* Includes ------------------------------------------------------------------*/
#include "main.h"
#include "usb_device.h"

/* USER CODE BEGIN Includes */
#include "usbd_cdc_if.h"
#include <string.h>
#include <stdio.h>
#include <stdarg.h>
/* USER CODE END Includes */

/* USER CODE BEGIN PD */

#define STRB_IDLE  		1
#define STRB_PULSE 		0
#define T 				10
#define STATE_RUN 		0
#define STATE_PROGRAM 	1
#define STATE_CONFIG    2
#define STATE_LIB_ADD   3

#define MENU_PAGE_MAIN      0
#define MENU_PAGE_SETTINGS  1
#define MENU_PAGE_LIBRARY   2

#define LIB_ADD_NAME            0
#define LIB_ADD_PASTE_PROMPT    1
#define LIB_ADD_PASTE           2
#define LIB_ADD_VERIFY_PROMPT   3
#define LIB_ADD_VERIFYING       4
#define LIB_ADD_COMMIT          5
#define LIB_ADD_CAPACITY_WARN   6

#define LIBRARY_TOC_ADDR        0x08014000UL
#define LIBRARY_POOL_ADDR       0x08014800UL
#define LIBRARY_POOL_SIZE       (44UL * 1024UL) // 44 kB (Pages 41-62, safe from 80 kB firmware region)
#define MAX_LIB_SLOTS           64
#define LIB_NAME_MAX_LEN        16

typedef struct {
	uint8_t  status;        // 0xFF = Empty, 0x01 = Active, 0x00 = Deleted
	char     name[LIB_NAME_MAX_LEN]; // 16 bytes: Null-terminated string (max 15 chars)
	uint8_t  pruned;        // 1 if non-BF comments stripped
	uint8_t  pad[2];        // 2 bytes padding
	uint32_t flash_offset;  // Byte offset from LIBRARY_POOL_ADDR
	uint32_t size;          // Payload size in bytes
	uint32_t crc32;         // Additive checksum / CRC
} ProgramDescriptor;

typedef union {
	ProgramDescriptor desc;
	uint32_t words[sizeof(ProgramDescriptor) / 4];
} ProgramSlot;

#define OUTBOX_CAPACITY 1024

#define PROG_BUF_SIZE           4096
#define STAGING_BUF_SIZE        1024
#define FLASH_CAPACITY          262144
#define PROG_IDLE_TIMEOUT_MS    100
#define STREAM_REPORT_INTERVAL  1024

// Run Mode speed hotkey options
#define SPEED_HOTKEY_NONE        0   // Disabled
#define SPEED_HOTKEY_PGUP_PGDN   1   // Page Up / Page Down (\x1b[5~ / \x1b[6~)
#define SPEED_HOTKEY_UP_DOWN     2   // Up Arrow / Down Arrow (\x1b[A / \x1b[B)
#define SPEED_HOTKEY_PLUS_MINUS  3   // '+' / '-'

// Manual step tick advance options
#define STEP_TICKS_1             0   // 1 Tick
#define STEP_TICKS_10            1   // 10 Ticks
#define STEP_TICKS_100           2   // 100 Ticks
#define STEP_TICKS_1K            3   // 1,000 Ticks
#define STEP_TICKS_10K           4   // 10,000 Ticks
#define STEP_TICKS_100K          5   // 100,000 Ticks

// Manual step key options
#define STEP_KEY_SPACE           0   // Spacebar (0x20)
#define STEP_KEY_TAB             1   // Tab (0x09)
#define STEP_KEY_ENTER           2   // Enter (0x0D / 0x0A)

#define MENU_ITEM_COUNT_COLLAPSED 9
#define MENU_ITEM_COUNT_EXPANDED  11

#define DFU_MAGIC_ADDR          (*((volatile uint32_t *)0x20003FF0))
#define DFU_MAGIC_VALUE         0xDEADBEEF
#define STM32F072_ROM_BASE      0x1FFFC800

/* USER CODE END PD */

/* USER CODE BEGIN PM */

//get a bit from a variable
#define GETBIT(var, bit)    (((var) >> (bit)) & 1)

/* USER CODE END PM */

ADC_HandleTypeDef hadc;
TIM_HandleTypeDef htim1;

/* USER CODE BEGIN PV */

extern USBD_HandleTypeDef hUsbDeviceFS;
uint8_t out_pending;
uint8_t code_dump;
uint8_t state;
uint8_t freq;
uint8_t serial_input;
uint8_t board_incoming;
uint8_t adc_input;
uint8_t ADC_ON;
uint32_t code_size;
uint8_t outbox[OUTBOX_CAPACITY];
volatile uint32_t head;
uint32_t leaving;
volatile uint32_t tail;
uint32_t tail_temp;
volatile uint32_t active_mco_cfg = 0;
volatile uint8_t  mco_throttled = 0;
volatile uint8_t  active_is_tim1 = 0;

// Runtime configuration settings (modifiable in interactive configuration menu)
uint8_t  cfg_auto_prog_run_mode   = 1;   // 1 = Auto-enter program mode if code paste detected in RUN mode
uint32_t cfg_auto_prog_min_bytes  = 16;  // Minimum packet size to trigger upload (safe against 3-5 byte ANSI escape keys)
uint8_t  cfg_auto_reset_after_pgm = 1;   // 1 = Automatically reset and launch program after write finishes
uint8_t  cfg_append_endless_loop  = 1;   // 1 = Automatically append '[-]+[]' infinite loop at EOF to halt PC cleanly
uint8_t  cfg_speed_hotkey_mode    = SPEED_HOTKEY_PGUP_PGDN;
uint8_t  cfg_manual_step_enabled  = 0;   // 0 = Normal continuous clock, 1 = Manual step mode (clock paused)
uint8_t  cfg_manual_step_ticks    = STEP_TICKS_100; // Step burst size (1, 10, 100, 1k, 10k, 100k)
uint8_t  cfg_manual_step_key      = STEP_KEY_SPACE; // Step trigger key (Space, Tab, Enter)
uint8_t  cfg_prune_on_paste       = 0;   // 0 = Disabled, 1 = Strip non-BF commands on paste
uint8_t  cfg_prune_in_library     = 1;   // 0 = Disabled, 1 = Strip non-BF commands when saving to library
uint8_t  cfg_cr_to_lf             = 1;   // 1 = Convert Windows \r (CR) -> \n (LF) in RUN mode

#define SERIAL_INBOX_SIZE 64
static volatile uint8_t serial_inbox[SERIAL_INBOX_SIZE];
static volatile uint8_t serial_inbox_head = 0;
static volatile uint8_t serial_inbox_tail = 0;

// Manual clock stepping accumulator queue
volatile uint32_t manual_step_ticks_pending = 0;

// Delayed Flash wear-leveling timer
uint8_t  settings_dirty = 0;
uint32_t settings_dirty_tick = 0;

uint8_t  menu_page = MENU_PAGE_MAIN;
int8_t   menu_cursor = 0;
volatile uint8_t menu_needs_render = 0;
volatile uint8_t menu_exit_requested = 0;
volatile int8_t  menu_action_pending = -1;
volatile int8_t  menu_action_dir = 1; // +1 = Right/Enter/Space, -1 = Left

// Library Add Program state machine
volatile uint8_t lib_add_substate = LIB_ADD_NAME;
char     lib_name_buf[LIB_NAME_MAX_LEN];
uint8_t  lib_name_len = 0;
uint32_t lib_code_size = 0;
uint32_t lib_raw_rx_size = 0;
uint32_t lib_add_last_rx_tick = 0;
uint32_t lib_verify_start_tick = 0;
uint8_t  lib_verify_requested = 0;
volatile uint8_t lib_start_add_requested = 0;
volatile int8_t  lib_delete_pending_slot = -1;
volatile int8_t  lib_load_pending_slot = -1;
volatile int8_t  lib_dump_pending_slot = -1;
volatile uint8_t lib_dump_viewing = 0;
volatile uint8_t lib_verify_choice_pending = 0;
volatile uint8_t lib_verify_choice = 0;
volatile uint8_t lib_verify_early_commit = 0;
volatile int8_t  lib_capacity_delete_slot = -1;

volatile uint8_t dfu_requested;
volatile uint8_t reset_requested;
volatile uint8_t dynamic_schema_requested = 0;
volatile uint8_t dynamic_lib_requested = 0;
volatile int8_t  cmd_lib_run_slot = -1;
volatile int8_t  cmd_lib_dump_slot = -1;
volatile int8_t  cmd_lib_del_slot = -1;
volatile uint8_t cmd_lib_add_requested = 0;
volatile uint8_t cmd_lib_add_verify = 0;
char cmd_lib_add_name[LIB_NAME_MAX_LEN] = {0};
volatile uint8_t lib_auto_verify = 0;
volatile uint8_t cmd_restore_requested = 0;

// Button debounce and hold tracking
uint8_t  btn_is_pressed = 0;
uint8_t  btn_last_sample = 1;
uint32_t btn_last_stable_tick = 0;
uint32_t btn_press_tick = 0;
uint8_t  btn_held_1s = 0;
uint8_t  btn_held_3s = 0;
uint8_t  btn_held_8s = 0;

// Dedicated program mode buffers and state
uint8_t prog_buffer[PROG_BUF_SIZE];
volatile uint8_t stream_staging[STAGING_BUF_SIZE];
volatile uint16_t staging_head;
volatile uint16_t staging_tail;
volatile uint32_t prog_rx_count;
volatile uint32_t prog_total_received;
volatile uint32_t prog_raw_received;
volatile uint32_t prog_flash_addr;
volatile uint32_t prog_last_rx_tick;
volatile uint8_t prog_active;
volatile uint8_t prog_is_streaming;
uint32_t prog_next_report_addr;
uint8_t stream_init_done;

/* USER CODE END PV */

void SystemClock_Config(void);
static void MX_GPIO_Init(void);
static void MX_ADC_Init(void);
static void MX_TIM1_Init(void);
/* USER CODE BEGIN PFP */

void initROMNormal(void);
uint8_t readBFOutput(void);
uint8_t wait(uint32_t);
void writeBFInput(uint8_t);
uint8_t readROM(uint32_t);
uint8_t writeROM(uint32_t, uint8_t);
uint8_t eraseROM(void);
void initROMWrite(void);

void CDC_Print(const char *str);
void CDC_Printf(const char *format, ...);
uint8_t TxBusy(void);
void initROMProgramming(void);
void setAddrBusFast(uint32_t addr);
void setDataBusFast(uint8_t data);
uint8_t readDataBusFast(void);
void setDataBusModeInput(void);
void setDataBusModeOutput(void);
uint8_t LLReadROMFast(uint32_t addr);
void LLWriteROMFast(uint32_t addr, uint8_t data);
uint8_t ToggleBitWaitFast(uint32_t addr);
uint8_t writeROMFast(uint32_t addr, uint8_t data);
uint8_t eraseROMFast(void);
uint8_t flashBufferToROM(const uint8_t *code, uint32_t len, const char *title, uint8_t append_loop, uint8_t auto_launch);
void flashDefaultLogoProgram(void);
void Execute_DFU_Jump(void);
const char *get_freq_name(uint8_t f);
void speed_step_up(void);
void speed_step_down(void);
void menu_enter(void);
void menu_exit(void);
void menu_render(void);
void menu_execute_action(uint8_t item, int8_t dir);
void led_update_pulse(uint32_t period_ms);
void settings_load(void);
void settings_save(void);

// Library prototypes
void lib_init_toc(void);
void lib_refresh_display_list(void);
uint8_t lib_get_active_count(void);
uint32_t lib_get_total_used_bytes(void);
int8_t lib_find_free_slot(void);
uint32_t lib_calculate_next_pool_offset(void);
void lib_rewrite_toc_compact(void);
uint8_t lib_save_program(const char *name, uint32_t size, uint8_t pruned);
void lib_delete_program(uint8_t slot);
void lib_load_and_run(uint8_t slot);
void lib_dump_program(uint8_t slot);
void lib_export_dynamic_schema(void);
void lib_start_add_program(void);
void CDC_Write(const uint8_t *data, uint32_t len);


/* USER CODE END PFP */

/* USER CODE BEGIN 0 */

void HAL_GPIO_EXTI_Callback(uint16_t GPIO_Pin){
	if (GPIO_Pin == GPIO_PIN_1){  // InStrobe falling edge: FPGA acknowledged current input byte
		HAL_GPIO_WritePin(BF_INCMG_GPIO_Port, BF_INCMG_Pin, GPIO_PIN_RESET);
		if (serial_inbox_head != serial_inbox_tail){
			uint8_t next_b = serial_inbox[serial_inbox_head];
			serial_inbox_head = (serial_inbox_head + 1) % SERIAL_INBOX_SIZE;
			writeBFInput(next_b);
			HAL_GPIO_WritePin(BF_INCMG_GPIO_Port, BF_INCMG_Pin, GPIO_PIN_SET);
			serial_input = 1;
		} else {
			serial_input = 0;
		}
	}
}

typedef struct {
	const char *name;
	uint32_t freq_hz;
	uint8_t is_tim1;
	uint16_t tim1_psc;
	uint16_t tim1_arr;
	uint32_t mco_cfg;
} FreqConfig;

static const FreqConfig freq_table[] = {
	// Ultra-low frequencies (TIM1_CH1 PWM on PA8)
	{ "10 Hz",          10, 1, 47999, 99,   0 },
	{ "25 Hz",          25, 1, 47999, 39,   0 },
	{ "50 Hz",          50, 1, 47999, 19,   0 },
	{ "100 Hz",        100, 1, 47999, 9,    0 },
	{ "250 Hz",        250, 1, 47999, 3,    0 },
	{ "500 Hz",        500, 1, 47999, 1,    0 },
	{ "1 kHz",        1000, 1, 479,   99,   0 },
	{ "2 kHz",        2000, 1, 479,   49,   0 },
	{ "5 kHz",        5000, 1, 479,   19,   0 },
	{ "10 kHz",      10000, 1, 479,   9,    0 },
	{ "25 kHz",      25000, 1, 479,   3,    0 },
	{ "50 kHz",      50000, 1, 479,   1,    0 },

	// Standard & high frequencies (MCO on PA8)
	{ "62.5 kHz",    62500, 0, 0,     0,    RCC_MCO1SOURCE_HSI   | RCC_MCODIV_128 },
	{ "125 kHz",    125000, 0, 0,     0,    RCC_MCO1SOURCE_HSI   | RCC_MCODIV_64  },
	{ "250 kHz",    250000, 0, 0,     0,    RCC_MCO1SOURCE_HSI   | RCC_MCODIV_32  },
	{ "500 kHz",    500000, 0, 0,     0,    RCC_MCO1SOURCE_HSI   | RCC_MCODIV_16  },
	{ "750 kHz",    750000, 0, 0,     0,    RCC_MCO1SOURCE_HSI48 | RCC_MCODIV_64  },
	{ "1 MHz",     1000000, 0, 0,     0,    RCC_MCO1SOURCE_HSI   | RCC_MCODIV_8   },
	{ "1.5 MHz",   1500000, 0, 0,     0,    RCC_MCO1SOURCE_HSI48 | RCC_MCODIV_32  },
	{ "2 MHz",     2000000, 0, 0,     0,    RCC_MCO1SOURCE_HSI   | RCC_MCODIV_4   },
	{ "3 MHz",     3000000, 0, 0,     0,    RCC_MCO1SOURCE_HSI48 | RCC_MCODIV_16  },
	{ "4 MHz",     4000000, 0, 0,     0,    RCC_MCO1SOURCE_HSI   | RCC_MCODIV_2   },
	{ "6 MHz",     6000000, 0, 0,     0,    RCC_MCO1SOURCE_HSI48 | RCC_MCODIV_8   },
	{ "8 MHz",     8000000, 0, 0,     0,    RCC_MCO1SOURCE_HSI   | RCC_MCODIV_1   },
	{ "12 MHz",   12000000, 0, 0,     0,    RCC_MCO1SOURCE_HSI48 | RCC_MCODIV_4   },
};
#define FREQ_COUNT ((uint8_t)(sizeof(freq_table) / sizeof(freq_table[0])))
#define DEFAULT_FREQ_INDEX 15 // 500 kHz
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
int main(void)
{
  /* MCU Configuration--------------------------------------------------------*/

  /* Reset of all peripherals, Initializes the Flash interface and the Systick. */
  HAL_Init();

  __HAL_RCC_SYSCFG_CLK_ENABLE();
  __HAL_SYSCFG_REMAPMEMORY_FLASH();

  /* Configure the system clock */
  SystemClock_Config();

  /* Initialize all configured peripherals */
  MX_GPIO_Init();

  // Force clean USB re-enumeration so PC host disconnects from any previous DFU session
  __HAL_RCC_GPIOA_CLK_ENABLE();
  GPIO_InitTypeDef usb_disc = {0};
  usb_disc.Pin = GPIO_PIN_12;
  usb_disc.Mode = GPIO_MODE_OUTPUT_PP;
  usb_disc.Pull = GPIO_NOPULL;
  usb_disc.Speed = GPIO_SPEED_FREQ_LOW;
  HAL_GPIO_Init(GPIOA, &usb_disc);
  HAL_GPIO_WritePin(GPIOA, GPIO_PIN_12, GPIO_PIN_RESET);
  HAL_Delay(100);
  HAL_GPIO_DeInit(GPIOA, GPIO_PIN_12); // Release PA12 back to analog/USB mode

  MX_USB_DEVICE_Init();
  MX_ADC_Init();
  MX_TIM1_Init();
  /* USER CODE BEGIN 2 */

  // Bootup alive blip on Red LED
  HAL_GPIO_WritePin(LED_GPIO_Port, LED_Pin, GPIO_PIN_SET);
  HAL_Delay(80);
  HAL_GPIO_WritePin(LED_GPIO_Port, LED_Pin, GPIO_PIN_RESET);

  serial_input = 0;
  head = 0;
  leaving = 0;
  tail = 0;

  ADC_ON = 0;

  code_size = 0;
  initROMNormal();
  wait(1000);
  HAL_GPIO_WritePin(OE_GPIO_Port, OE_Pin, GPIO_PIN_RESET);
  wait(1000);
  HAL_GPIO_WritePin(BF_RST_GPIO_Port, BF_RST_Pin, GPIO_PIN_SET);
  HAL_GPIO_WritePin(LED_GPIO_Port, LED_Pin, GPIO_PIN_RESET);
  state = STATE_RUN;

  // Load persistent settings and library TOC from internal Flash
  settings_load();
  lib_init_toc();
  set_freq(freq);

  uint8_t init_btn = HAL_GPIO_ReadPin(BRD_RST_GPIO_Port, BRD_RST_Pin);
  btn_last_sample = init_btn;
  btn_is_pressed = (init_btn == GPIO_PIN_RESET) ? 1 : 0;
  btn_last_stable_tick = HAL_GetTick();
  btn_press_tick = 0;
  btn_held_1s = 0;
  btn_held_3s = 0;
  btn_held_8s = 0;

  prog_rx_count = 0;
  prog_total_received = 0;
  prog_flash_addr = 0;
  prog_last_rx_tick = 0;
  prog_active = 0;
  prog_is_streaming = 0;
  staging_head = 0;
  staging_tail = 0;
  stream_init_done = 0;

  /* USER CODE END 2 */

  /* Infinite loop */
  /* USER CODE BEGIN WHILE */

  while (1){
	  // Check for dynamic schema query request (!MENU*) in Thread Mode
	  if (dynamic_schema_requested){
		  dynamic_schema_requested = 0;
		  menu_export_dynamic_schema();
	  }

	  // Check for dynamic library query request (!LIB*) in Thread Mode
	  if (dynamic_lib_requested){
		  dynamic_lib_requested = 0;
		  lib_export_dynamic_schema();
	  }

	  // Check for dynamic library action requests
	  if (cmd_lib_run_slot >= 0){
		  uint8_t s = (uint8_t)cmd_lib_run_slot;
		  cmd_lib_run_slot = -1;
		  CDC_Printf("!LIB:RUN:OK:%u\r\n", (unsigned int)s);
		  lib_load_and_run(s);
	  }
	  if (cmd_lib_dump_slot >= 0){
		  uint8_t s = (uint8_t)cmd_lib_dump_slot;
		  cmd_lib_dump_slot = -1;
		  lib_dump_program(s);
	  }
	  if (cmd_lib_del_slot >= 0){
		  uint8_t s = (uint8_t)cmd_lib_del_slot;
		  cmd_lib_del_slot = -1;
		  lib_delete_program(s);
		  CDC_Printf("!LIB:DEL:OK:%u\r\n", (unsigned int)s);
		  dynamic_lib_requested = 1;
	  }
	  if (cmd_lib_add_requested){
		  cmd_lib_add_requested = 0;
		  strncpy(lib_name_buf, (const char *)cmd_lib_add_name, sizeof(lib_name_buf) - 1);
		  lib_name_buf[sizeof(lib_name_buf) - 1] = '\0';
		  lib_name_len = (uint8_t)strlen(lib_name_buf);
		  lib_auto_verify = cmd_lib_add_verify;

		  // Abort any pending menu actions
		  menu_action_pending = -1;
		  lib_start_add_requested = 0;

		  initROMProgramming();
		  eraseROMFast();
		  lib_code_size = 0;
		  lib_raw_rx_size = 0;
		  lib_add_last_rx_tick = HAL_GetTick();
		  state = STATE_LIB_ADD;
		  lib_add_substate = LIB_ADD_PASTE;
		  CDC_Printf("!LIB:ADD:READY:%s\r\n", lib_name_buf);
	  }

	  // Check for restore factory demo request in Thread Mode
	  if (cmd_restore_requested){
		  cmd_restore_requested = 0;
		  CDC_Print("\r\nRestoring Default Demo to Flash...\r\n");
		  flashDefaultLogoProgram();
	  }

	  // Check for DFU jump request (executed in Thread Mode outside interrupt)
	  if (dfu_requested){
		  dfu_requested = 0;
		  Execute_DFU_Jump();
	  }

	  // Check for soft-processor reset request
	  if (reset_requested){
		  reset_requested = 0;
		  HAL_GPIO_WritePin(LED_GPIO_Port, LED_Pin, GPIO_PIN_SET);
		  HAL_GPIO_WritePin(BF_RST_GPIO_Port, BF_RST_Pin, GPIO_PIN_RESET);
		  HAL_Delay(10);
		  HAL_GPIO_WritePin(BF_RST_GPIO_Port, BF_RST_Pin, GPIO_PIN_SET);
		  HAL_Delay(60);
		  HAL_GPIO_WritePin(LED_GPIO_Port, LED_Pin, GPIO_PIN_RESET);
		  manual_step_ticks_pending = 0;
		  serial_inbox_head = 0;
		  serial_inbox_tail = 0;
		  serial_input = 0;
		  set_freq(freq);
		  CDC_Printf("\r\n[bf_\xC2\xB5P reset] %s\r\n", get_freq_name(freq));
		  if (cfg_manual_step_enabled){
			  CDC_Printf("[Manual Step Mode Active: Press %s to step %s]\r\n",
			             get_step_key_name(cfg_manual_step_key), get_step_ticks_name(cfg_manual_step_ticks));
		  }
	  }

	  // 1. Rock-solid debounced button state machine (15ms stable window to filter mechanical chatter)
	  uint8_t btn_raw = HAL_GPIO_ReadPin(BRD_RST_GPIO_Port, BRD_RST_Pin);

	  if (btn_raw != btn_last_sample){
		  btn_last_sample = btn_raw;
		  btn_last_stable_tick = HAL_GetTick();
	  }
	  else if ((HAL_GetTick() - btn_last_stable_tick) >= 15){
		  if ((btn_raw == GPIO_PIN_RESET) && !btn_is_pressed){
			  // Button officially PRESSED (held down)
			  btn_is_pressed = 1;
			  btn_press_tick = HAL_GetTick();
			  btn_held_1s = 0;
			  btn_held_3s = 0;
			  btn_held_8s = 0;
			  // Hold FPGA in reset while physical button is held down
			  HAL_GPIO_WritePin(BF_RST_GPIO_Port, BF_RST_Pin, GPIO_PIN_RESET);
		  }
		  else if ((btn_raw == GPIO_PIN_SET) && btn_is_pressed){
			  // Button officially RELEASED
			  btn_is_pressed = 0;
			  uint32_t press_duration = HAL_GetTick() - btn_press_tick;

			  if (btn_held_8s || (press_duration >= 8000)){
				  // Held >= 8s: Restore Default Brainfuino ASCII Logo Demo!
				  flashDefaultLogoProgram();
			  }
			  else if (btn_held_3s || (press_duration >= 3000)){
				  // Held >= 3s: Enter Interactive Configuration Menu
				  menu_enter();
			  }
			  else if (btn_held_1s || (press_duration >= 1000)){
				  // Held >= 1s: Enter Program Mode
				  state = STATE_PROGRAM;
				  HAL_GPIO_WritePin(LED_GPIO_Port, LED_Pin, GPIO_PIN_SET);
				  HAL_GPIO_WritePin(BF_RST_GPIO_Port, BF_RST_Pin, GPIO_PIN_RESET); // Hold soft-processor in reset

				  prog_rx_count = 0;
				  prog_total_received = 0;
				  prog_raw_received = 0;
				  prog_flash_addr = 0;
				  prog_active = 0;
				  prog_is_streaming = 0;
				  staging_head = 0;
				  staging_tail = 0;
				  stream_init_done = 0;

				  CDC_Print("\r\n\r\n=== BRAINFUINO PROGRAM MODE ===\r\nPaste Brainfuck code now (up to 256 kB)...\r\n");
				  CDC_Resume_Rx();
			  }
			  else if (press_duration >= 15){
				  // Short tap (< 1s)
				  if (state == STATE_CONFIG){
					  // In Config Menu: short press exits menu and resumes program
					  menu_exit();
				  }
				  else if (state == STATE_PROGRAM){
					  // In Program Mode: short press exits Program Mode and runs the program
					  HAL_GPIO_WritePin(LED_GPIO_Port, LED_Pin, GPIO_PIN_RESET);
					  initROMNormal();
					  wait(1000);
					  HAL_GPIO_WritePin(OE_GPIO_Port, OE_Pin, GPIO_PIN_RESET);
					  wait(1000);
					  // Pulse FPGA reset
					  HAL_GPIO_WritePin(BF_RST_GPIO_Port, BF_RST_Pin, GPIO_PIN_RESET);
					  HAL_Delay(10);
					  HAL_GPIO_WritePin(BF_RST_GPIO_Port, BF_RST_Pin, GPIO_PIN_SET);
					  serial_inbox_head = 0;
					  serial_inbox_tail = 0;
					  serial_input = 0;
					  state = STATE_RUN;
					  CDC_Print("\r\n[Running program]\r\n");
				  }
				  else {
					  // In Run Mode: short press resets the running soft-processor and blips the LED!
					  HAL_GPIO_WritePin(LED_GPIO_Port, LED_Pin, GPIO_PIN_SET);
					  HAL_GPIO_WritePin(BF_RST_GPIO_Port, BF_RST_Pin, GPIO_PIN_RESET);
					  HAL_Delay(10);
					  HAL_GPIO_WritePin(BF_RST_GPIO_Port, BF_RST_Pin, GPIO_PIN_SET);
					  HAL_Delay(60);
					  HAL_GPIO_WritePin(LED_GPIO_Port, LED_Pin, GPIO_PIN_RESET);
					  manual_step_ticks_pending = 0;
					  serial_inbox_head = 0;
					  serial_inbox_tail = 0;
					  serial_input = 0;
					  set_freq(freq);
					  CDC_Printf("\r\n[bf_\xC2\xB5P reset] %s\r\n", get_freq_name(freq));
					  if (cfg_manual_step_enabled){
						  CDC_Printf("[Manual Step Mode Active: Press %s to step %s]\r\n",
						             get_step_key_name(cfg_manual_step_key), get_step_ticks_name(cfg_manual_step_ticks));
					  }
				  }
			  }
			  btn_held_1s = 0;
			  btn_held_3s = 0;
			  btn_held_8s = 0;
			  if (state == STATE_RUN){
				  HAL_GPIO_WritePin(LED_GPIO_Port, LED_Pin, GPIO_PIN_RESET);
			  }
		  }
	  }
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

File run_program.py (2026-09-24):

#!/usr/bin/env python3
"""
Brainfuino Program Runner & Terminal
===================================
A unified CLI utility to auto-detect, flash, and interact with the
Brainfuino native Brainfuck development board.

Usage:
  python run_program.py                        # Interactive menu of available programs
  python run_program.py <path/to/program.b>     # Flash and run specified program
  python run_program.py --run-only             # Connect to currently flashed program
  python run_program.py --list                 # List all available sample programs
"""

import sys
import os
import time
import argparse
import threading
import serial
from serial.tools import list_ports

# Platform-specific non-blocking keyboard input
try:
    import msvcrt
    WINDOWS = True
except ImportError:
    WINDOWS = False
    import select
    import tty
    import termios

PROGRAMS_DIR = os.path.join(os.path.dirname(os.path.abspath(__file__)), "programs")

def auto_detect_port():
    """Locate the Brainfuino Virtual COM Port."""
    ports = list(list_ports.comports())
    
    # Check for ST CDC / Brainfuino identifiers
    for p in ports:
        desc = (p.description or "").lower()
        hwid = (p.hwid or "").lower()
        mfg = (p.manufacturer or "").lower()
        if "0483:5740" in hwid or "brainfuino" in desc or "stm" in desc or "stmicroelectronics" in mfg:
            return p.device, p.description

    # Fallback to single available port
    if len(ports) == 1:
        return ports[0].device, ports[0].description

    if ports:
        port_list = ", ".join([f"{p.device} ({p.description})" for p in ports])
        raise RuntimeError(f"Could not uniquely identify Brainfuino.\nAvailable ports: {port_list}\nPlease specify with --port <PORT>.")
    else:
        raise RuntimeError("No COM ports found. Please ensure Brainfuino is connected via USB.")

def list_available_programs():
    """Discover all .b programs in the programs/ directory grouped by folder."""
    discovered = []
    if not os.path.isdir(PROGRAMS_DIR):
        return discovered

    for root, dirs, files in os.walk(PROGRAMS_DIR):
        for f in sorted(files):
            if f.endswith(".b"):
                full_path = os.path.join(root, f)
                rel_path = os.path.relpath(full_path, os.getcwd())
                category = os.path.basename(root)
                discovered.append((category, f, full_path, rel_path))
    return discovered

def interactive_pick_program():
    """Prompt user to choose a program from programs/."""
    programs = list_available_programs()
    if not programs:
        print(f"No .b programs found in {PROGRAMS_DIR}!")
        return None

    print("\n" + "=" * 60)
    print("       BRAINFUINO PROGRAM SELECTOR")
    print("=" * 60)
    
    current_cat = None
    for idx, (cat, name, _, rel) in enumerate(programs, 1):
        if cat != current_cat:
            current_cat = cat
            print(f"\n  [{cat.upper()}]")
        size = os.path.getsize(rel)
        print(f"    {idx:2d}) {name:<20} ({size:,} bytes) -> {rel}")

    print("\n" + "=" * 60)
    while True:
        try:
            choice = input(f"Select program number (1-{len(programs)}) or 'q' to quit: ").strip()
            if choice.lower() in ('q', 'exit', 'quit'):
                return None
            idx = int(choice)
            if 1 <= idx <= len(programs):
                return programs[idx - 1][3]
            print(f"Please enter a number between 1 and {len(programs)}.")
        except ValueError:
            print("Invalid input. Please enter a number.")
        except (KeyboardInterrupt, EOFError):
            print("\nAborted.")
            return None

def open_serial(port, baud=115200):
    """Open serial port with friendly diagnostics for locked or missing ports."""
    try:
        ser = serial.Serial(port, baudrate=baud, timeout=0.05)
        return ser
    except serial.SerialException as e:
        err = str(e)
        if "PermissionError" in err or "Access is denied" in err:
            print(f"\n[ERROR] Access denied to {port}!")
            print("Another program (PuTTY, Tera Term, VS Code, etc.) has this port open.")
            print("Please disconnect that terminal and try again.\n")
        elif "FileNotFoundError" in err or "cannot find the file" in err:
            print(f"\n[ERROR] Port {port} not found! Is the Brainfuino USB cable connected?\n")
        else:
            print(f"\n[ERROR] Failed to open {port}: {e}\n")
        sys.exit(1)

def flash_program(ser, file_path):
    """Stream Brainfuck code to STM32 coprocessor for parallel ROM flashing."""
    with open(file_path, "r", encoding="latin-1", errors="replace") as f:
        code = f.read()

    size = len(code)
    print(f"\nLoaded '{file_path}': {size:,} characters.")
    print("Streaming to Brainfuino Flash ROM...")

    # Ensure in RUN mode first
    ser.write(b"\x1b\x1b\r\n")
    time.sleep(0.2)
    ser.reset_input_buffer()

    t0 = time.time()
    chunk_size = 512
    sent = 0
    for i in range(0, size, chunk_size):
        chunk = code[i:i + chunk_size].encode("latin-1")
        ser.write(chunk)
        sent += len(chunk)
        time.sleep(0.005)

    dt = time.time() - t0
    rate = (sent / dt / 1024) if dt > 0 else 0
    print(f"Sent {sent:,} bytes in {dt:.2f}s ({rate:.1f} kB/s).")
    print("Waiting for STM32 to erase and burn ROM...\n")
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

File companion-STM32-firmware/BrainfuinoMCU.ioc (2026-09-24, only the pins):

Mcu.UserName=STM32F072V8Tx
PA0.GPIO_Label=BF_IN0
PA0.Signal=GPIO_Output
PA1.GPIO_Label=BF_IN1
PA1.Signal=GPIO_Output
PA11.Signal=USB_DM
PA12.Signal=USB_DP
PA2.GPIO_Label=BF_IN2
PA2.Signal=GPIO_Output
PA3.GPIO_Label=BF_IN3
PA3.Signal=GPIO_Output
PA4.GPIO_Label=BF_IN4
PA4.Signal=GPIO_Output
PA5.GPIO_Label=BF_IN5
PA5.Signal=GPIO_Output
PA6.GPIO_Label=BF_IN6
PA6.Signal=GPIO_Output
PA7.GPIO_Label=BF_IN7
PA7.Signal=GPIO_Output
PA8.GPIO_Label=BF_CLK
PA8.Signal=RCC_MCO
PB0.GPIO_Label=BF_OUT0
PB0.Signal=GPIO_Input
PB1.GPIO_Label=BF_OUT1
PB1.Signal=GPIO_Input
PB10.GPIO_Label=D2
PB10.Signal=GPIO_Input
PB11.GPIO_Label=D3
PB11.Signal=GPIO_Input
PB12.GPIO_Label=D4
PB12.Signal=GPIO_Input
PB13.GPIO_Label=D5
PB13.Signal=GPIO_Input
PB14.GPIO_Label=D6
PB14.Signal=GPIO_Input
PB15.GPIO_Label=D7
PB15.Signal=GPIO_Input
PB2.GPIO_Label=BF_OUT2
PB2.Signal=GPIO_Input
PB3.GPIO_Label=BF_OUT3
PB3.Signal=GPIO_Input
PB4.GPIO_Label=BF_OUT4
PB4.Signal=GPIO_Input
PB5.GPIO_Label=BF_OUT5
PB5.Signal=GPIO_Input
PB6.GPIO_Label=BF_OUT6
PB6.Signal=GPIO_Input
PB7.GPIO_Label=BF_OUT7
PB7.Signal=GPIO_Input
PB8.GPIO_Label=D0
PB8.Signal=GPIO_Input
PB9.GPIO_Label=D1
PB9.Signal=GPIO_Input
PC0.GPIO_Label=AIN0
PC0.Signal=ADC_IN10
PC1.GPIO_Label=BF_INSTRB
PC1.Signal=GPXTI1
PC10.GPIO_Label=OE
PC10.Signal=GPIO_Output
PC11.GPIO_Label=WE
PC11.Signal=GPIO_Output
PC12.GPIO_Label=BF_RST
PC12.Signal=GPIO_Output
PC2.GPIO_Label=BRD_INSTRB
PC2.Signal=GPIO_Output
PC3.GPIO_Label=BF_OUTSTRB
PC3.Signal=GPXTI3
PC4.GPIO_Label=BRD_RST
PC4.Signal=GPIO_Input
PC5.GPIO_Label=AIEN
PC5.Signal=GPIO_Input
PC6.GPIO_Label=BRD_INCMG
PC6.Signal=GPIO_Input
PC7.GPIO_Label=BF_INCMG
PC7.Signal=GPIO_Output
PC8.GPIO_Label=A16
PC8.Signal=GPIO_Input
PC9.GPIO_Label=A17
PC9.Signal=GPIO_Input
PD0.GPIO_Label=IN0
PD0.Signal=GPIO_Input
PD1.GPIO_Label=IN1
PD1.Signal=GPIO_Input
PD2.GPIO_Label=IN2
PD2.Signal=GPIO_Input
PD3.GPIO_Label=IN3
PD3.Signal=GPIO_Input
PD4.GPIO_Label=IN4
PD4.Signal=GPIO_Input
PD5.GPIO_Label=IN5
PD5.Signal=GPIO_Input
PD6.GPIO_Label=IN6
PD6.Signal=GPIO_Input
PD7.GPIO_Label=IN7
PD7.Signal=GPIO_Input
PE0.GPIO_Label=A0
PE0.Signal=GPIO_Input
PE1.GPIO_Label=A1
PE1.Signal=GPIO_Input
PE10.GPIO_Label=A10
PE10.Signal=GPIO_Input
PE11.GPIO_Label=A11
PE11.Signal=GPIO_Input
PE12.GPIO_Label=A12
PE12.Signal=GPIO_Input
PE13.GPIO_Label=A13
PE13.Signal=GPIO_Input
PE14.GPIO_Label=A14
PE14.Signal=GPIO_Input
PE15.GPIO_Label=A15
PE15.Signal=GPIO_Input
PE2.GPIO_Label=A2
PE2.Signal=GPIO_Input
PE3.GPIO_Label=A3
PE3.Signal=GPIO_Input
PE4.GPIO_Label=A4
PE4.Signal=GPIO_Input
PE5.GPIO_Label=A5
PE5.Signal=GPIO_Input
PE6.GPIO_Label=A6
PE6.Signal=GPIO_Input
PE7.GPIO_Label=A7
PE7.Signal=GPIO_Input
PE8.GPIO_Label=A8
PE8.Signal=GPIO_Input
PE9.GPIO_Label=A9
PE9.Signal=GPIO_Input
PF10.GPIO_Label=LED
PF10.Signal=GPIO_Output

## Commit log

2026-09-15 Consolidate Brainfuino subsystems into monorepo and update README/gitignore
    [BOM-BrainFuino.csv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]
2026-09-16 docs: integrate step-by-step STM32CubeProgrammer DFU screenshots into firmware guide
2026-09-16 docs: remove feasibility analysis, add PCB layout diagram, generalize dedicated program mode
2026-09-16 docs: augment board artwork section with bottom PCB layout render
2026-09-16 feat(firmware): streaming flash engine with USB CDC backpressure and automated DFU bootloader
    - Implement Dedicated Program Mode with fast 10us register-level Flash writes
    - Implement streaming fallback for programs > 4 kB up to 256 kB with live progress reporting
    - Implement USB CDC endpoint flow control returning hardware NAK tokens during erase and buffer saturation
    - Implement automated software USB DFU bootloader reboot via SRAM magic flag (0xDEADBEEF) and startup assembly intercept
    - Add build.ps1 cross-platform PowerShell script for one-click compilation and USB DFU flashing
    - Add sequential test pattern generator script and 12 kB test program
    - Update documentation suite with archite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
    [generate_test_pattern.py, main.c]
2026-09-16 Implement Phase 3: Interactive Configuration Menu, button debouncing, and PWM LED pulsing
    - Add raspi-config style text configuration menu with hybrid ANSI/VT100 & numeric key navigation
    - Decouple USB ISR keystroke parsing from non-blocking Thread Mode ANSI frame rendering
    - Implement 35ms state-based debounce filter on button transitions to eliminate false restarts during long holds
    - Add 70ms Red LED blip feedback on short-press reset in Run Mode
    - Implement 1 kHz software PWM breathing/pulsing for 6s hold and active Config Menu status
    - Fix menu exit LED state latch to ensure LED shuts off immediately on exit
    - Add comprehensive Configuration Menu user guide and update terminal controls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
    [main.c, test_config_menu.py, test_config_menu_advanced.py]
2026-09-17 Add smart hardware clock-pausing, 13-speed ladder, persistent Flash storage, and test suite
    - Implemented instant MCO gating on BF_OUTSTRB falling edge in EXTI2_3_IRQHandler with bus settling and circular buffer backpressure
    - Added 13-speed granular clock ladder (62.5 kHz to 12 MHz) compliant with SST39LF020 55ns parallel Flash access time
    - Added non-volatile configuration storage in STM32 internal Flash Page 63 with CRC verification and wear-mitigation checking
    - Added startup SYSCFG memory remap and clean USB disconnect re-enumeration pulse
    - Created automated 13-speed logo fidelity test script (scripts/test_logo_all_speeds.py) verifying 100% character fidelity
    - Updated MkDocs documenta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
2026-09-17 feat(firmware): add multi-program flash library, TOC engine, and multi-page menu
    - Implement 76 kB user partition and 64-slot Table of Contents (TOC) in STM32 internal Flash (Pages 24-62)
    - Support dynamic program allocation, zero-erase tombstone deletion, and on-demand defrag compaction
    - Add non-BF ASCII comment pruning options for direct paste and library storage
    - Implement multi-page interactive menu (Main Menu, Program Library, Hardware Settings) with Left/Right arrow option cycling
    - Add interactive program upload workflow with optional FPGA pre-run verification (skip with 'n')
    - Permanently preserve factory Brainfuino logo demo in unerasable Slot 00
    - Add automated physical hardware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
    [main.c, test_library_and_menu.py]
2026-09-17 fix(firmware): update button hold timings, fix debounce, live FPGA verification, and rich load output
    - Update button hold thresholds: 1s Program Mode, 3s Settings Menu, 8s Factory Reset
    - Implement 15ms stable debounce filter to eliminate dropped quick taps and false releases
    - Fix live FPGA soft-processor execution and CDC terminal streaming during library pre-run verification
    - Add rich visual feedback during library program loading (erasure, 0-100% write progress, ROM readback verify)
    - Report pruning metrics (raw bytes, pruned bytes, percent saved) on upload completion
    - Add interactive pool capacity management and progress reporting during program compaction
    - Update automated test sui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
    [main.c, test_library_and_menu.py]
2026-09-17 Fix library menu numbering, auto-compact slot fragmentation, and align box width
    [main.c]
2026-09-18 Auto-detect STM32 Virtual COM port in test_library_and_menu.py
2026-09-18 Add library program dump ('d'), update delete shortcut ('x'), remove hardcoded logo infinite loop, and update docs
    [main.c, test_library_and_menu.py]
2026-09-24 feat: fix documentation math formatting, update web terminal and firmware commands
    - Fix unrendered LaTeX formatting across documentation and enable MathJax via Arithmatex
    - Add automated LaTeX detection and fixing scripts in scripts/
    - Update firmware with !DUMP and !LIB:ADD_NOVERIFY: commands
    - Update web serial terminal layout with permanent monitor card, tree view, BOOT0 jumper instructions, and library write options
    [find_latex_and_format_issues.py, fix_latex_and_format_issues.py, main.c]
2026-10-04 feat: enhance Bad Apple pipeline, firmware async ROM write, and web terminal monitor
    - Defer firmware ROM initialization and flash erase from USB CDC interrupt to main thread loop
    - Redesign Web Terminal Write tab into 2-column layout with permanent execution monitor
    - Add dual Direct/Line input modes and shared ANSI terminal rendering in web terminal
    - Overhaul generate_bad_apple.py with in-memory FFmpeg piping, auto-resolution, and hardware clock calibration
    - Update run_bad_apple.py with auto COM port detection and clock indexing
    - Add Bad Apple soft-processor emulator, delta analyzer, and full-duration precompiled .b files
    [emulator.py, generate_bad_apple.py, main.c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]
2026-10-23 feat: STM32 menu color alignment, strict !DUMP, QGC toasts, and ANSI cursor overlay support
2026-10-23 feat(web-terminal): modular Vite/TS architecture with 54-test automated suite
    - Refactor monolithic 6,800-line web terminal into modular TypeScript architecture (Option B)
    - Add single-file bundler (vite-plugin-singlefile) auto-syncing to index.html and documentation
    - Expose all interactive and dynamically rendered event handlers on window
    - Add comprehensive 54-test Vitest suite covering ANSI parsing, keyboard router, QGC toasts, serial connection, buttons, Intel HEX parser, flasher UI, terminal I/O, and firmware protocol
    - Fix off-by-one parsing bug in !LIB:START firmware response
    - Update GitHub Actions workflow to build web terminal bundle during docs deployment
2026-10-23 fix(firmware): prevent fragmented ANSI arrow keys from prematurely exiting settings menu
    - Implement ANSI escape sequence accumulator (menu_esc_buf) in CDC_Receive_Callback
    - If an escape sequence (0x1B) is split across USB packet boundaries, buffer incoming bytes and reassemble arrows
    - Add 40ms timeout in thread mode so standalone ESC keys back out cleanly while multi-byte arrow sequences are never misinterpreted as ESC
    - Verified live on hardware with split-packet simulation
2026-10-29 fix(web-terminal): correct USB troubleshooting modal power cycle instruction

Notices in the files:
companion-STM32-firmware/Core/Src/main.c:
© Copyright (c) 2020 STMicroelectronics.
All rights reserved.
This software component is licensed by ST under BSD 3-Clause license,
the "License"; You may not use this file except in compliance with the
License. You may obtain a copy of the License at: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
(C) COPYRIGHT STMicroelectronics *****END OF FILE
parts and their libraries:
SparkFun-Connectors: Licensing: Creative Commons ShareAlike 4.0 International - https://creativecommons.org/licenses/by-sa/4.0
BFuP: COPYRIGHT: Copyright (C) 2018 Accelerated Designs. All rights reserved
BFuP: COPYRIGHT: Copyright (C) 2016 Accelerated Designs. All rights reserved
